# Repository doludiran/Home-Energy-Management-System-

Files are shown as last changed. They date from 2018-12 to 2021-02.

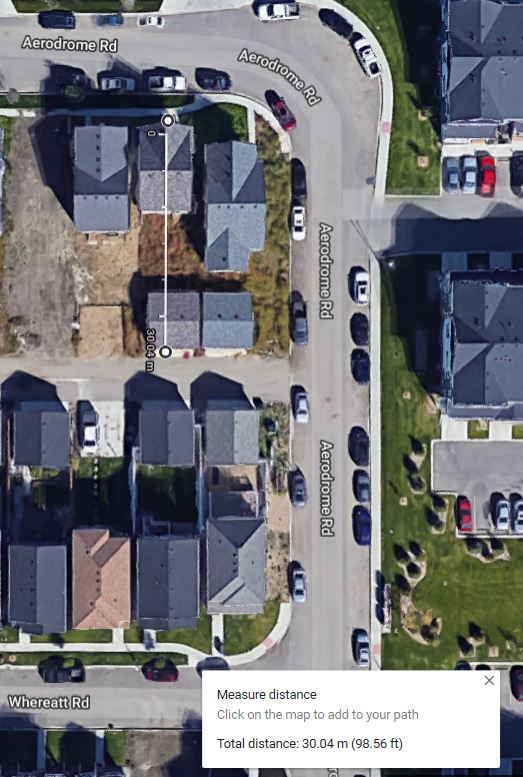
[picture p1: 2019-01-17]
Documentation/HEMS Study/Detached garage.JPG

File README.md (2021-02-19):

# Home-Energy-Management-System-
This system retrieves dynamic electricity pricing information from a utility portal and automatically schedules  large residential loads like EV charging to reduce the overall cost of energy consumed 

The design involves and consists of:
• A Central Control Unit using a Linux based Raspberry Pi programmed in Python. Components of this unit included a touch screen graphic
user interface, secure Internet interface for the automatic retrieval of dynamic pricing information from a utility web portal and xbee wireless
communication interface (zigbee) for remote switching as well as load telemetry data transmission
• A Device Energy Monitoring Unit using an ARM Cortex-M3 based Microcontroller. Components of this unit included a xbee wireless interface
(zigbee) for transmitting monitoring data as well as receiving switching commands from the Central Control Unit, Analog Circuitry for AC load
switching and power consumption measurement (AC Voltage and Current)
• An optimization algorithm to minimize power cost using SciPY
• Multi-threaded programming in c and Python
• Printed Circuit Boards (PCB) design including soldering of Surface-Mount ICs (SMT)
• Hardware and printed circuit board testing and validation
• Component selection and assembly designed to comply with CSA standards

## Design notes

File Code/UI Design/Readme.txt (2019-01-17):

/**
 ******************************************************************************
 * Name:    Readme.txt
 * Capstone Project: HOME ENERGY CONSUMPTION MONITORING AND CONTROL UI DESIGN
 * Version: V1.1
 * Author: Damilola Oludiran 
 * ----------------------------------------------------------------------
 *
 * This is a python touchscreen user interface application built using the Kivy 
 * framework. This module is responsible for the presentation of information the 
 * user as well as retrieval of user preference inputs necessary for the correct  
 * operation of the overall system. 
 * The intended target device is a Raspberry Pi 3 board.
 *          
 * Preconditions:
 * Ensure the following are installed on target:
 *  - Python and Kivy dependencies 
 *  - Kivy
 *  - Kivy garden (matplotlib.backend_kivyagg) 
 *  - sqlite3 database 
 *  - Matplotlib 
 *
 * Note: development is done using Jupiter notebook and has a .ipynb extension. In 
 * in order to run on target, the code should be copied into a .py file 
 *****************************************************************************
 */

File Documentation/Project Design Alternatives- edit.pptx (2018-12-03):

## Revised Client Problem Statement

Design a System that Implements a Demand Response Control/ Management of User Appliances during Peak Energy Consumption Periods by Exploring the Benefits of a Load Scheduling System in Time of Use(ToU) Utility Pricing.

The system will include a Central Control Unit (CCU) that Communicates with a Utility Portal via the Internet to Exchange pricing information with the user

The CCU will Communicate with Various Sensors and Components that will Control Time of Use of Certain Devices and Monitor their Energy Consumption

## Time of Use (ToU) and Real Time Pricing

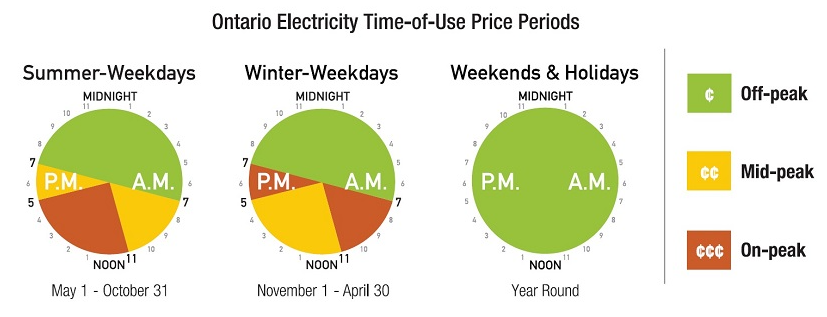
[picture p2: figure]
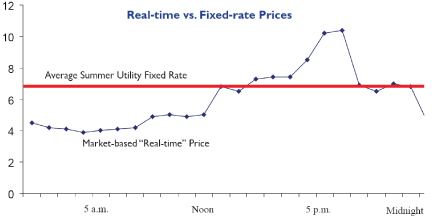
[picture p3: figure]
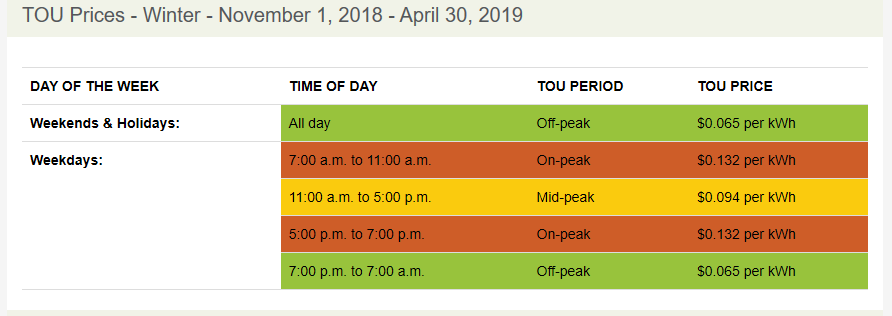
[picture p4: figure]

## System Block Diagram

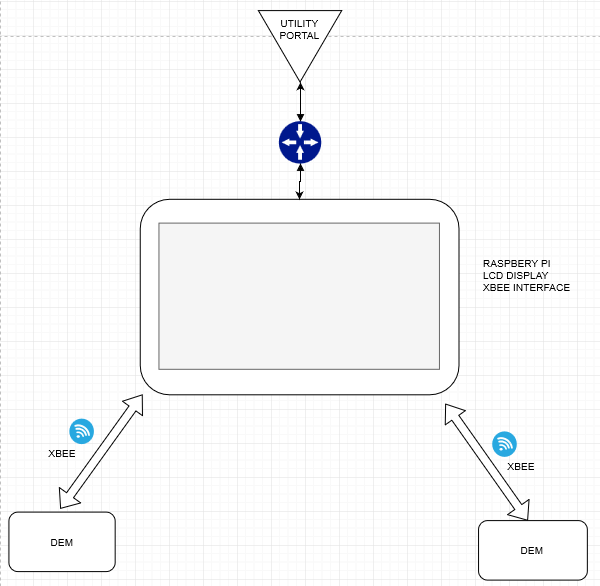
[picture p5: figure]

Central Control Unit (CCU)
Receive Data from Utility Portal
Process the Data/Request
Send Signals to the Device Energy Managers for load Scheduling
Device Energy Manager (DEMs)
Switch the Devices according to the Instructions from the CCU
Monitor Appliance Energy Usage
Send Usage Information to the CCU

CCU

## Sub-System : Device Energy Manager

Manage the Switching of the Desired Appliance

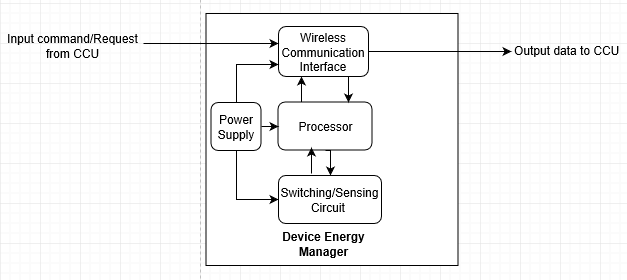
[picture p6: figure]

## Sub-System 1: Device Energy Manager (DEM)

Measure the Energy Usage/Consumption (Optional) of the Desired Appliance

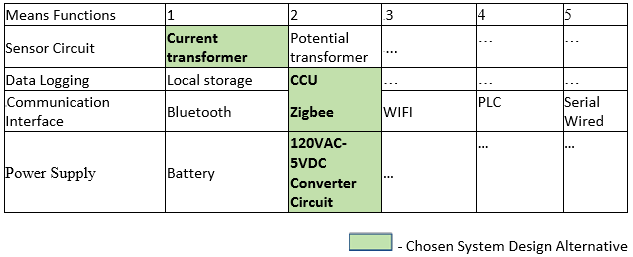
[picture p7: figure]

Switching Circuit | Relay | …… | …… | …… | ……

## Testing Plan

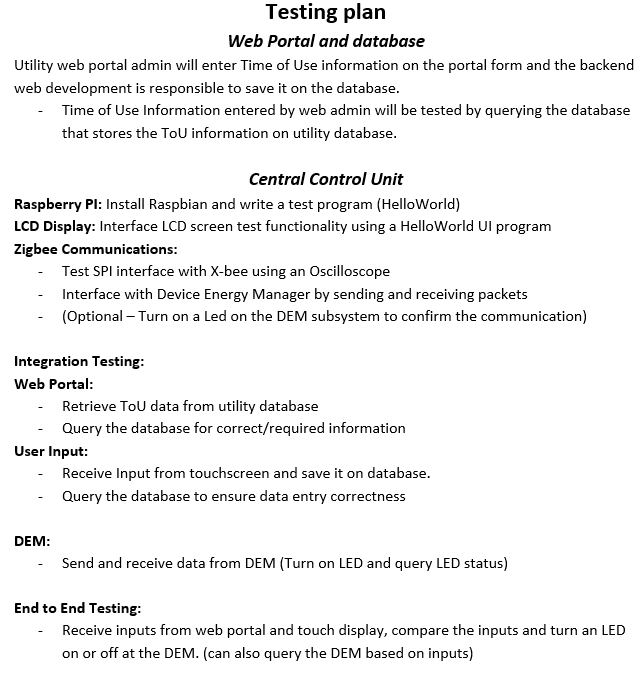
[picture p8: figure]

## Testing Plan

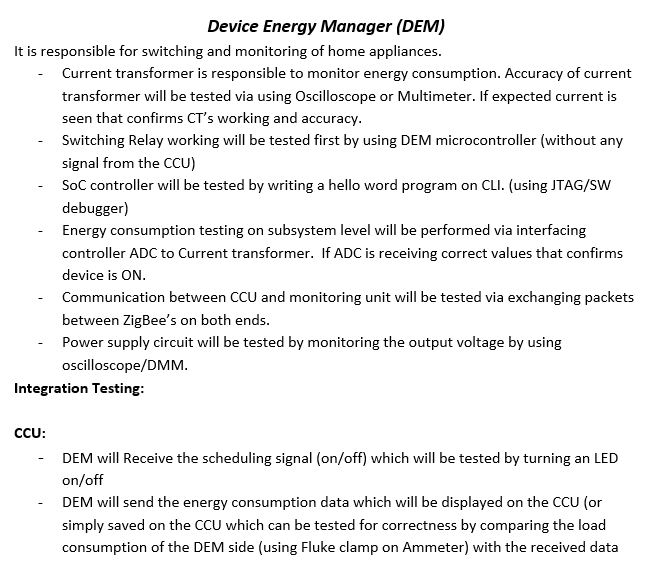
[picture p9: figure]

## Testing Plan – Division of Labour (Overall)

Dami - CCU
- Design and Programming
  - Python based touchscreen User Interface Design
  - Process/display the data from the DEMs
  - Processing User Input for device/appliance scheduling (will be done by using ToU data from utility)
  - Sending scheduling information to the DEMs
- Zigbee Communications
- Enclosure Design and Fabrication (Optional)
Amandeep –
- SoC Testing and Debugging
- RF Antenna Design
- DEM-Side Communication
- Utility Database portal Design
- CCU database design
- Demo Load Electronics
Bikramjit – DEMs
- Programming and Testing
- PCB Schematic Design and Fabrication
- Enclosure Design and Fabrication (Optional)
* This plan might be subject to revision/changes during the progress of the project

## Gantt Chart

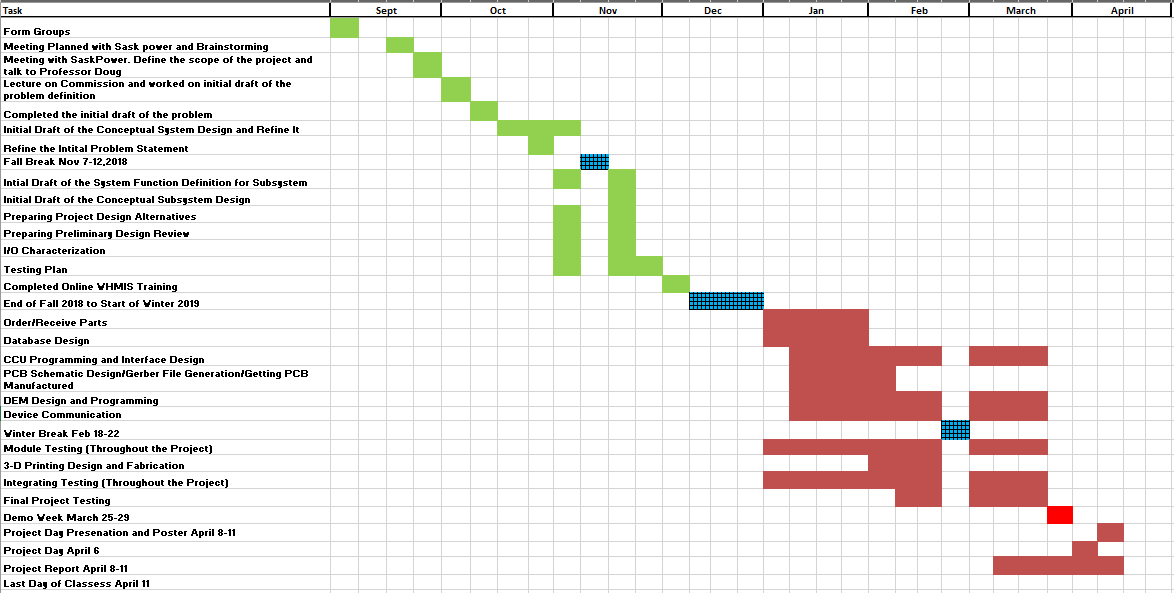
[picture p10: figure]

## Questions

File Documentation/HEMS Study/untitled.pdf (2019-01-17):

Smart home energy management systems: Concept, configurations,

## and scheduling strategies

## Bin Zhou a,n

## , Wentao Li a

## , Ka Wing Chan b

## , Yijia Cao a

## , Yonghong Kuang a

## , Xi Liu a

,

## Xiong Wang a

a College of Electrical and Information Engineering, Hunan University, Changsha 410082, China b Department of Electrical Engineering, The Hong Kong Polytechnic University, Hong Kong

## article info

Article history:
Received 22 April 2015
Received in revised form
22 January 2016
Accepted 13 March 2016
Available online 25 March 2016

Keywords:
Renewable energy
Home energy management system Home energy storage system Home appliance scheduling
Smart house

## abstract

With the arrival of smart grid era and the advent of advanced communication and information infrastructures, bidirectional communication, advanced metering infrastructure, energy storage systems and home area networks would revolutionize the patterns of electricity usage and energy conservation at the consumption premises. Coupled with the emergence of vehicle-to-grid technologies and massive distributed renewable energy, there is a profound transition for the energy management pattern from the conventional centralized infrastructure towards the autonomous responsive demand and cyber-physical energy systems with renewable and stored energy sources. Under the sustainable smart grid paradigm, the smart house with its home energy management system (HEMS) plays an important role to improve the efficiency, economics, reliability, and energy conservation for distribution systems. In this paper, a brief overview on the architecture and functional modules of smart HEMS is presented. Then, the advanced HEMS infrastructures and home appliances in smart houses are thoroughly analyzed and reviewed. Furthermore, the utilization of various building renewable energy resources in HEMS, including solar, wind, biomass and geothermal energies, is surveyed. Lastly, various home appliance scheduling strategies to reduce the residential electricity cost and improve the energy efficiency from power generation utilities are also investigated.
& 2016 Elsevier Ltd. All rights reserved.

Contents

1. Introduction | 31
2. HEMS overview | 31
2.1. Concept of HEMS | 31
2.2. Architecture of HEMS | 31
2.3. Functionalities of HEMS | 32
3. HEMS infrastructures | 33
3.1. Communication and networking system | 33
3.2. Smart meters | 33
3.3. Smart HEMS center | 33
3.4. Home appliances | 34
4. Renewable energy resources in smart houses | 34
4.1. Current status of renewable energy sources in smart houses | 34
4.2. Utilization of renewable energy resources in HEMS | 35
4.3. Techniques to renewable energy in smart HEMS | 36
5. Energy scheduling strategies in smart houses | 36
5.1. Appliance scheduling strategies for HEMSs | 36
5.2. Price-based and incentive-based demand response strategies | 37
5.3. Modelling and control schemes for household appliances | 37

Contents lists available at ScienceDirect

journal homepage: www.elsevier.com/locate/rser

# Renewable and Sustainable Energy Reviews

http://dx.doi.org/10.1016/j.rser.2016.03.047
1364-0321/& 2016 Elsevier Ltd. All rights reserved.

n Corresponding author. Tel.: þ86 731 8388 9677; fax: þ86 731 88664197. E-mail addresses: binzhou@hnu.edu.cn (B. Zhou), yjcao@hnu.edu.cn (Y. Cao).

Renewable and Sustainable Energy Reviews 61 (2016) 30–40 (http://dx.doi.org/10.1016/j.rser.2016.03.047)

5.4. Scenarios analysis for HEMS scheduling strategies | 38
6. Conclusions | 38
Acknowledgements | 39
References | 39
1. Introduction

In 1998, Electrical Power Research Institute (EPRI) carried out a research of “complex interactive network/ system” to develop a highly reliable and fully automated grid in the United States, which is the prototype of the U.S. smart grid [1]. Since the EPRI formally proposed the term “Intelli-Grid” in 2002, the concept of smart grid has been widely accepted to indicate the future development trend of power grids [2,3]. With the use of the term “Smart Grid”, European countries founded the “European Smart-Grids Technology Platform” in 2005, and then launched a research report in 2006 to comprehensively formulate the concepts and framework for the European smart grid [4]. Later, the U.S. Department of Energy released a report “The Smart Grid” in December 2007, and it integrated the European ideas and concepts into the U.S. smart grid to support the trend towards a more reliable and sustainable green energy supply [5,6]. In recent years, developing a modernized smart city infrastructure has become a global common priority in most countries because of the tremendous environmental, economic, and societal benefits that it could offer. In particular, smart electricity usage in demand side plays an important role in improving the sustainability and energy conservation for the home end-users, and will also affect the electricity consumption pattern of human daily behaviors [7,8]. Recent advancements on information and communication technologies, such as advanced metering infrastructure (AMI), smart sensor technologies, bidirectional communication, smart home appliances, home area network (HAN) and home energy storage system (HESS), etc. have been developed. Therefore, this growing trend provides the technical foundation and infrastructures for the smart house with home energy management system (HEMS) [9]. Smart HEMS is an essential home system for the successful demand-side management of smart grids [10]. It monitors and arranges various home appliances in real-time, based on user's preferences via the human–machine interface in smart houses, in order to conserve electricity cost and improve energy utilization efficiency [11–13]. With the growing concerns on global energy security and environmental emissions, more and more distributed renewable generations, such as wind turbines, solar panels, and plug-in electric vehicles (PEVs), etc., would be gird-integrated into the active distribution networks with gradually increasing penetration [14,15]. Coupled with the rapid development in advanced power electronics and alternative energy technologies, building renewable and stored energy sources installed at the residential premises can be incorporated in smart HEMS to improve the in-home efficiency of energy conversion and utilization [16]. Consequently, this leads to a fundamental transition for modern energy management systems from traditional centralized infrastructure towards the cyber-physical HEMSs and autonomous responsive demand with large geographical regions of renewable and stored energy sources throughout smart power systems [17,18].
With the two-way information flow between electricity providers and consumers in smart grid, the massive HEMSs are encouraged to participate in demand response mechanism for energy savings and cooperation. The demand response is defined as the changes in electricity usage by the end-use customers from their normal consumption patterns in response to changes in the time-dependent electricity price [19], and it offers incentives for the demand-side consumers to urge lower electricity usage over periods with higher prices or when power supply reliability is jeopardized [20]. Furthermore, in response to the real-time electricity price from smart meters, the home consumers with HEMS can shift their demand consumptions of appliances automatically or manually into off-peak hours in order to minimize the electricity payment [21]. In a typical smart house, the thermostatically controlled appliances, including heating, ventilation, and air-conditioning system, electric water heater and refrigerator, usually account for most of residential energy consumption [22]. The ever-increasing load demand and energy crisis issue have made the use of smart HEMS more attractive to both the power utilities and customers [23]. Therefore, with the consent of the customers, the HEMS can play an important role for optimal coordination and scheduling of various smart appliances and building renewable facilities.
The objective of this paper is to provide a comprehensive review of the development status and research progress on smart HEMSs with renewable and stored energy sources. First, a brief overview on the architecture and fundamental functions of HEMS is surveyed. Then, the advanced HEMS configurations and home appliances in smart houses are analyzed and presented. Third, the utilization techniques for various building renewable energy resources in smart houses, including solar, wind, biomass and geothermal energy, are reviewed. Moreover, various home scheduling strategies for optimal operations of smart HEMSs are further investigated. Lastly, the concluding remarks are drawn.
2. HEMS overview
2.1. Concept of HEMS

Under the smart grid paradigm, the AMI devices enable a reliable two-way communication between power utilities and home consumers [24]. It provides an opportunity for economic incentives of smart home to manage the demand-side resources by shifting their electricity usage during peak-load periods in response to the changes in electricity prices. The economic incentives include the saving in electricity bill, the improvement in utilization efficiency of household appliances and residential energy conservation [25]. Hence, smart HEMS is defined as the optimal system providing energy management services in order to efficiently monitor and manage electricity generation, storage, and consumption in smart houses [26,27]. With the communication and sensing techniques in HANs, the information collection for energy consumption from all household appliances can be provided, and the remote real-time monitoring and control for different operational modes of smart home devices can even be achieved by a personal computer or smart phone [28]. Besides, HEMS can provide not only the optimum utilization status of home appliances, but also energy storage and management services for distributed energy resources (DERs) and HESS [29].

2.2. Architecture of HEMS

The overall architecture of a representative smart HEMS is shown in Fig. 1. The HEMS center includes a centralized smart

B. Zhou et al. / Renewable and Sustainable Energy Reviews 61 (2016) 30–40 | 31

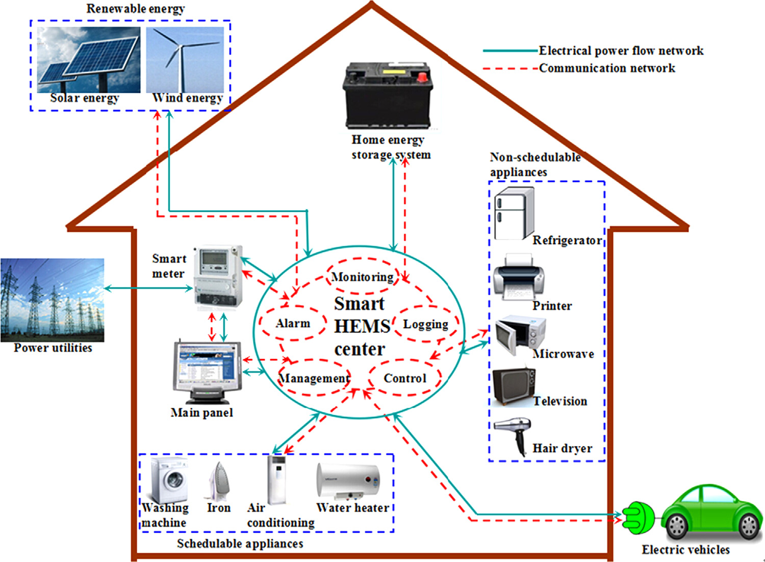
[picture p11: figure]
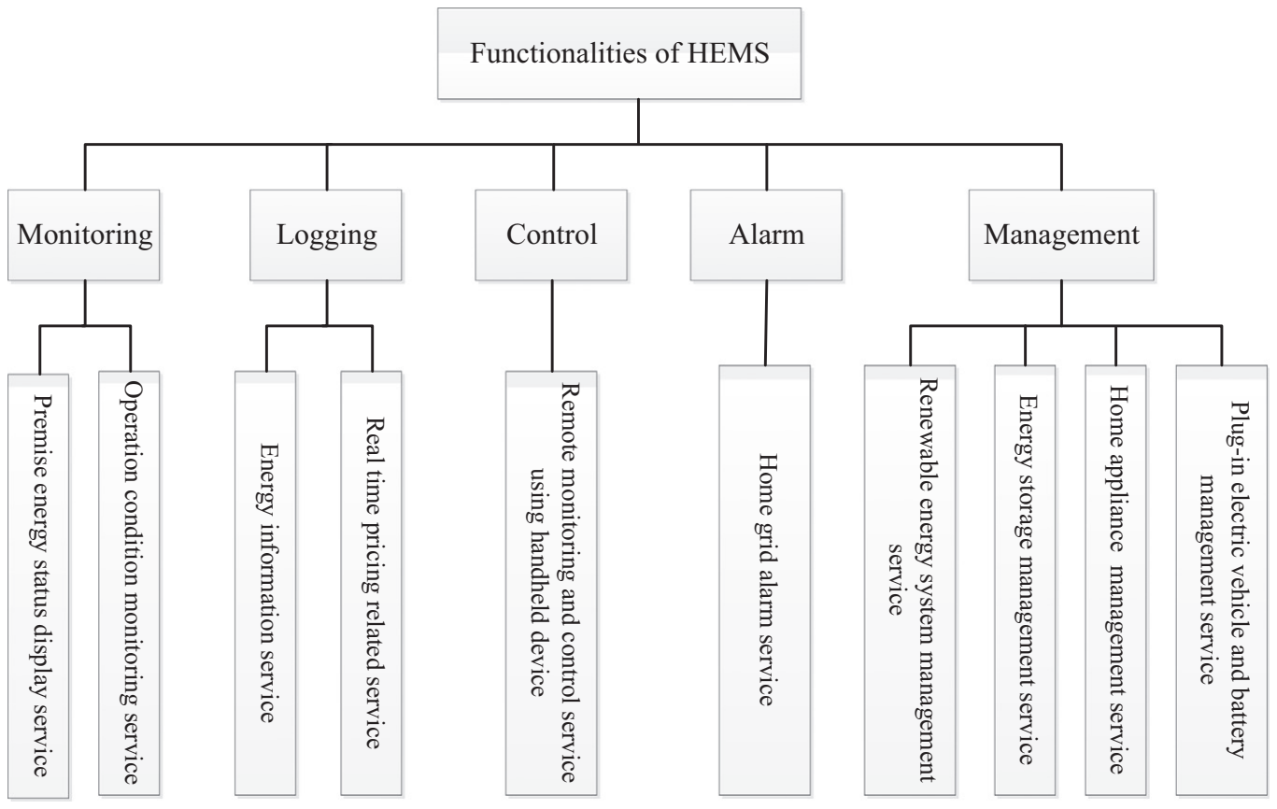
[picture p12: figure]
Functionalities of HEMS; Premise energy status display service; Plug-in electric vehicle and battery; management service

controller to provide the homeowner with monitoring modules and control functionalities based on the home communication network [30]. The real-time electricity consumption data from in-home appliances, including schedulable and non-schedulable appliances, can also be collected by the main panel of smart HEMS to implement optimal demand dispatch. In addition, the house gateway, such as smart meter, can be utilized as an interactive communication interface between power utilities and the smart house in real-life deployment. Typically, the smart meter receives a demand response signal from power utilities as an input to the smart HEMS, and the optimization of home appliance scheduling can be implemented for the residential demand response [31]. Electric vehicle (EV) is a special type of schedulable load. It not only consumes energy from power grids to meet the residents' transportation requirements, but also provides emergency power for other household loads within the smart community environment [32]. Currently, the distributed renewable generations in residential areas most commonly involve solar photovoltaic (PV). The residential on-site energy sources can be fully integrated in the interactive generation management and operations of HEMS, and allow the smart houses not only rely on the bulk power from the transmission systems. Due to the inherent intermittence and randomness of solar energy, the energy storage devices play an important role to improve the power quality and energy efficiency as well as maintain the energy system reliability [33,34].

2.3. Functionalities of HEMS

For the purpose of participating in electricity saving and demand response, HEMS should be more flexible to manage and control smart home appliances, renewable energy resources and

Fig. 1. Overall architecture of a representative HEMS.

Monitoring | Logging | Control | Management Alarm Operation condition monitoring service | Energy information service | Real time pricing related service | Remote monitoring and control service using handheld device | Home grid alarm service | Renewable energy system management service | Energy storage management service | Home appliance management service

Fig. 2. Functionalities of a representative smart HEMS.

32 | B. Zhou et al. / Renewable and Sustainable Energy Reviews 61 (2016) 30–40

HESS [35]. Moreover, the active control services, including real-time information on the amount of energy consumption and the pricing of energy in smart homes, can be provided to the consumers on the basis of HEMS. The household consumers can choose their preferences via the human-machine interface to schedule the service time of various appliances to enhance their energy utilization efficiency [36]. Fig. 2 shows the typical functionalities of a smart HEMS center with five main functional modules, including monitoring, logging, control, management and alarm. Further detailed description on the five HEMS modules are illustrated in Table 1 [36,37].

3. HEMS infrastructures

The in-home infrastructure of HEMS is composed of smart HEMS center, smart meters, communication and networking system, HESSs and other smart devices [34]. With these smart infrastructures, HEMS can access, monitor, control and optimize the performance of various DERs, EVs, household appliances and equipment. Furthermore, HEMS is capable of supporting full integration of smart appliances and smart home as well as two-way interaction with users and electric power utilities. Many attractive features of smart grid such as cost- effectiveness, flexibility, provision of differentiated services and user friendly advanced smart power technology with open standard assessment can also be implemented via the HEMS [38].

3.1. Communication and networking system

So far, various HEMSs have been designed based on different communication schemes with hardware implementation [39–46], such as power line communication [36], ZigBee [39], BACnet [40], Bluetooth [45] and human–machine interface systems [42,43]. Extensive investigations have been done on communication and networking technologies for HANs. Young-Sung Son believed that the combination of a smart meter and power line communication could provide remote access, facilitate planning, and save the energy consumption of home appliances [36]. Dae-Man Han suggested a new Smart HEMS based on an IEEE802.15.4 and ZigBee which divides and assigns various home network tasks to appropriate components [39]. With the support of active sensor networks which compose of sensor and actuator components, HEMS can integrate diversified physical sensing information and control various household devices [39]. Also, Kastner Wolfgang introduced the necessity of the building automation, systems and communication infrastructures based on BACnet [46]. Considering the potential of the easily embedding Bluetooth technique in communication devices and household appliances, Lilakiatsakun proposed a method to establish a complete home network using Bluetooth technique [45]. In addition, Fangxing Li designed a human–machine interface system which can be used in HEMS. It is supposed that HEMS shall have five main components referred as application processor, communication interface, user interface, sensor interface and load interface to facilitate user's operations on this system [42,43].
Based on the evaluation analysis of various communication technologies, ZigBee is chosen to demonstrate the proposed HEMS [42]. ZigBee, a wireless communication technology that is developing rapidly in recent years, has laid solid foundation on networking, security and software-related technical standards. ZigBee makes use of the world's most common 2.4G–2.4835 GHz frequency band. In terms of the low energy consumption and durability, ZigBee is with the low power consumption, low cost technology and can support a large number of characteristics of the network nodes, and thus can be used in a wide range of industrial applications [30].
3.2. Smart meters

Smart meters are the advanced energy meters that measure the energy consumption of a consumer and provide additional information to power utilities using a two-way communication scheme [47,48]. As a result, customers are able to make optimal decisions to schedule the electricity usage of in-home appliances as well as actions of DERs and HESS [49]. As the foundation of data acquisition, data processing and advanced metering equipment management, smart meters are the latest techniques blended with computer science, modern communications and measurement techniques. Considering that smart meters are the basis of smart electricity, the functional design of smart meters should take into account the current facts and future development, such as the access of DER and the actual capacity of communication channel [47].
Main functions of smart meters include the following [50]: 1) Measuring the multi-period and multi-mode power rates of active and reactive energy metering usage; 2) Supporting two-way communication, sending data information and accepting instruction information, such as real-time information query, real-time electricity standard rates, meter upgrade program settings, etc.; 3) Enabling the response in terms of the requirements to achieve smart load shedding and cooperating with smart meter and smart interactive terminals during the islanding transition when a failure happens on the main power grid; 4) Collecting data with smart gas meters, water meters and other versatile value-added services.
3.3. Smart HEMS center

Smart HEMS center, analogue to the brain of entire smart electricity home, is the core of HEMS and implements the smart energy management. Smart HEMS center is located in user's houses as a home appliance. Main functions of smart HEMS center

Table 1
Functional modules of HEMS.

HEMS modules Service description

Monitoring | Monitoring offers easy access to real-time information on energy consumption and allows users to focus on the electricity saving. It can also provide
| display services for the operational modes and energy status of each home appliance.
Logging | Logging is to collate and save the data information on the amount of electricity usage from appliances, generations from DERs and energy storage state.
| This service also contains demand response analysis for real-time prices from grid utility.
Control | There are two types of control, namely, direct control and remote control. Direct control is implemented on both the equipment and control system;
| whereas, remote control means customers can online access to monitor and control the usage patterns of in-home devices via handheld personal
| computer or smart phone from outside.
Management | Management is the most important function of HEMS to enhance the optimization and efficiency of electrical power usage in smart house. It covers a
| range of services including renewable energy system management service, energy storage management service, home appliance management service,
| and Plug-in EV and battery management service.
Alarm | Alarm will be generated and sent to the smart HEMS center with information on the fault locations, for example, if there is any abnormality detected.
B. Zhou et al. / Renewable and Sustainable Energy Reviews 61 (2016) 30–40 | 33

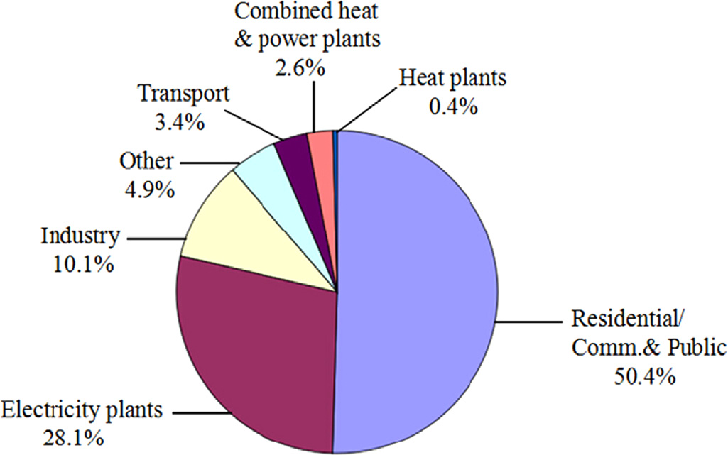
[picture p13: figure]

are as follows [51]: 1) Receiving a large amount of data sent by smart meters, main control panel, and real-time display. The control commands issued by the consumer are sent to all household equipment. Consequently, the automated demand response can be achieved; 2) Providing a friendly human-machine interface and supporting user's real-time browsing, online monitoring, task setting and other functions to arrange the usage of electricity; 3) With high scalability, the smart HEMS center can set water, electricity, gas, and other indoor controls; 4) Integrating DERs, energy storage devices and electricity regulator of EVs as well as analyzing and forecasting distributed generations to achieve the optimal control of DERs.

3.4. Home appliances

Various household appliances and energy storage devices can be thoroughly analyzed and modelled based on the device characteristics and preference usages. In order to implement the optimal coordinated appliance scheduling strategies, the smart home appliances can be divided into two categories: 1) Non-schedulable home appliances, e.g. refrigerator, printer, microwave, television, hair dryer; 2) Schedulable home appliances, which can be scheduled for optimal operation or switched on/off at any time, e.g. washing machine, air conditioner, iron, water heater, EVs. The appliances which can complete a task without any manual control, such as air conditioner and water heater, are schedulable [51]. While non-schedulable appliances, such as lights, computers and televisions, rely on manual control to complete a task and are needed only when the users are home. Since the comfort level of users is quite sensitive to the timely services of non-schedulable appliances, their usage would usually not be delayed. Schedulable appliances can be further classified into ‘interruptible’ and ‘non-interruptible’ in terms of the continuity of operation time [52]. Generally, the interruptible appliances are usually more schedulable than non- interruptible ones. The non-interruptible appliances are constrained by fixed operation period called ‘hold-time’ [52]. As a unique load, the EV becomes more important and extensive as the part of HEMS. Experts expect that the amount of EVs will be increased in the following years, which helps to reduce air pollutants and greenhouse gas emissions [53]. Since EVs can be charged or discharged when connected to the grid, a growing number of practical services can now be realized in power grid [54]. Vehicle-to-grid, as a new concept, indicates that the electric energy stored in the EV battery can also be transmitted to the power grid [55–57]. In the smart HEMS, EVs are capable of balancing the peak power, which means that EVs can supply power during peak periods while users consume power during off-peak periods.

4. Renewable energy resources in smart houses
4.1. Current status of renewable energy sources in smart houses

Since 1990s, the utilization of renewable energy sources has increased with an average annual rate of 2.0% [58]. Additionally, renewable energy has been consumed in various fields, including the industrial, residential, commercial, and public sectors. As shown in Fig. 3, only 31.1% of renewable energy is used for electricity and heat production worldwide, while 50.4% is used for residential, commercial and public purposes in 2012 [58]. It also indicates that the research on the use of renewable energy in HEMS is of great significance and developing prospects. With the rapid development of sustainable energy technologies and increasing demand for low-emission generations, the utilization of renewable energy shows promising prospects for smart houses.

From the technical and economic aspects, it is quite feasible to substitute fossil fuels with renewable energy for home electricity supply [59]. Meanwhile, with further development of smart grid technologies including communication and monitoring, control, and self-healing, the smart home energy utilization has been improved to accommodate multiplying renewable resources [60]. Due to its rapid development of renewable energy resources in the past 15 years, Germany is a forerunner in renewable electricity [61]. In 1998, Germany began to implement “100,000 Roofs Plan”, aiming at obtaining 300 MW solar power from the roofs of citizens. Presently, there are about 0.9% of German families using solar power system. Residents sell rooftop solar electricity at a high price to power grid during the day, however, at night, they buy electricity for use at a fair price. Therefore, residents become energy producers and consumers [62]. Thanks to its easy installation and low cost, the solar PV is widely used in smart houses. Cyprus, known as a leader in solar water heater in the world, is a country where 92% families and 53% hotels are using solar water heater systems, equipping with about 937,363 m² of solar collectors, nearly 1 m² per person [63]. Moreover, the solar PV cell productivity in China in 2008 was about 4 GW, 3 GW PV of which was module capacities. The cumulative capacity of installed PV power was 150 MW. At the same time, the solar water heaters have covered over 125 million m² in buildings, reaching about 60% of the worldwide total [64].
Wind power is characterized by many merits such as clean, renewable, widely distributed and land-saving [65]. Therefore, wind power is more widely used than other resources to solve severe environmental problems. For example, in 2013, one third of Denmark's electricity is produced by wind and over 83 countries in the world are using wind power to produce electricity [66–68]. Estimates show that the annual electricity generated by wind power system will amount to 1.7–5.0 TW h by 2020 if new buildings and existing buildings are all equipped with wind power systems [69–71]. Obviously, the utilization of wind power in smart houses is of great potential.
As an important means of access to energy, the application of biomass combustion power generation technology in smart houses is foreseeable. Since the 1990s, Denmark, Austria and other European countries have started the development and research of biomass power generation technologies. After years of efforts, boilers have been developed for power generation with wood chips, straw, chaff, etc. At present, biomass power generation has been used in households throughout Denmark [64]. Straw power generation and other renewable energy sources have accounted for more than 24% of the national energy consumption. The installed biomass power generation capacity in HEMS of United States has reached 10.5 million kW, while the biomass power

Fig. 3. World sectoral consumption of renewables in 2012.

34 | B. Zhou et al. / Renewable and Sustainable Energy Reviews 61 (2016) 30–40

generation techniques get faster development and higher utilization rate in Japanese cities. Likewise, China's utilization of biomass has been developed substantially. Achievements have been made in biogas, biomass power generation and liquid bio-fuel, while the majority usage belongs to electricity and heat generation. The installed capacity of biomass power generation increased to 4 GW in 2010, which was about 25% of the total. 1600 large-scale digesters and over 30 million home biogas digesters were built for smart home, and the annual biogas output was about 14 bcm and 1.65 Mt for bio-fuel [64]. Furthermore, great importance has been attached to the combination of biomass power and smart home energy dispatch. The immature technologies, the absence of comprehensive product standards, and inadequate supply chain are major barriers to the further development of biomass energy in smart houses.
Geothermal energy, defined as the heat from the underground, is an ideal renewable energy resource that is not intermitted and distributed usually around volcanic areas. There are two forms of geothermal energy utilization: geothermal heating and geothermal generations, and the latter has experienced a rapid development over recent years in the world [72]. So far, the chief geothermal energy suppliers for households are the United States, Iceland and Philippines. All around the world, Icelandic geothermal power is widely used to generate electricity due to its reliable base load and low cost. Thus, 87% of the smart houses in Iceland are heated by geothermal energy [73].
4.2. Utilization of renewable energy resources in HEMS

The world environmental condition, increasing need for energy demand nowadays, and the development of alternative energy technologies have brought forth a large amount of opportunities to develop various sustainable resources. Various building renewable energy resources, including solar, wind, biomass, geothermal energy and HESSs, have been utilized in smart houses.
As of today, solar energy is the richest inexhaustible and clean energy among all kinds of renewable energy resources [74]. Solar energy can be utilized in various aspects including solar water heater (SWH), solar PV, solar drying and solar cooling, etc. Due to easy installation and low cost, the SWH is widely used in households. Hot water heated by the solar energy can be used for showering, cooking and washing. In order to improve the conversion efficiency of SWH and reduce electricity consumption, legislations have been enacted to install SWH on each new building. Besides, more electricity bills are charged for the household who uses electricity to heat water [75]. Solar energy utilization can be classified into two types: solar thermal and solar PV. PV technique, known as the best means to convert solar energy, can directly convert the sunlight into electricity without any help from heat engines [76]. The solar PV is prevailing among residences where the annual sunshine is abundant [77]. Owing to its easy installation and maintenance, solar PV is quite suitable to incorporate into smart home to provide locals with energy and be utilized in various ways with less conversion failures. In addition, HEMS is usually equipped with an HESS which could store the energy for future or emergency use. The HESS also works as a buffer to make the HEMS reliable and improve network control [78,79]. The solar PV module is the most important part of a solar home system (SHS) and its supporting components should be properly adjusted according to direction and tilt of the module. Apart from the low price, the roof mounting for solar PV module is more suitable than ground or pole mounting and requires less wiring. The supporting components should be firmly attached to the roof beams instead of roof tiles [80]. In a stand-alone PV system, it is the irreplaceable charge controller to protect the battery from overcharge and over discharge. The charge controller is necessary for systems with unpredictable loads, user intervention, optimized or undersized battery storage and other characteristics that would allow excessive battery overcharging or over discharging, as the low voltage load will shorten the battery lifetime and diminish the load availability [81]. DC/AC inverters are used in SHS with a power larger than 100 Wp to provide customers with AC electricity. Only a few types of inverters are suitable for SHS, which are of square wave, modified square wave, and pure sine wave [82].
Wind energy is an important alternative energy, and its utilization in smart houses is always a hot topic over the years. Typically, the fan can generate electricity at the wind speed of 2.7 m/s, achieve rated power at 25 m/s, and ensure continuous electricity generation at 40 m/s. The device required by wind power generation is called wind turbine generator, which generally includes fan, generator, steering gear, tower, restricting and safety mechanism, and energy storage device [65]. In smart houses, the building hinders the linear motion of the air so that the air deflects to the top and sides of the building and produces pressure difference around the fan, which makes the generator rotate and generate electricity. Usually, the electrical energy generated is generally used for home lighting equipment, communication equipment and electrical tools [83]. Due to the volatility and intermittency of wind generations, the specific plans on the adjustable reserve capacity are of intense importance. Also, an accurate forecast on wind speed is indispensable to reduce the reserve capacity with the improved reliability [84]. HEMS can provide a well-designed storage platform to schedule the electricity generated by wind turbines through the charging/discharging strategies of HESS.
Primarily used for home cooking, heating and lighting, the biomass energy is widely used in smart houses. Numerous investigations have been studied on the biomass energy utilization, including the biomass energy in high-rise buildings [85], the biomass exploited for building heating [86], the influence of biomass boilers on energy rating [87,88], and the biomass fueled tri-generation system for selected buildings [89]. At present, the biomass power generation used in smart houses includes biomass combustion generation, biomass gasification generation, and biogas power generation. Biomass combustion generation is to combust biomass with excess air in the boiler, then the hot smoke generated exchanges heat with the heat exchanger of the boiler, and the high temperature and high pressure steam generated expands in gas turbine and hence generates electric power [86]. Biomass gasification generation technique means the thermochemical conversion of biomass into gas fuel, which is put into the combustion chamber of boiler, diesel generator, internal combustion engine generator and gas engine after purification to generate electricity. Lastly, biogas combustion generation is a biogas utilization technique that appears with the development of biogas technique. Biogas is utilized in the engine and equipped with integrated power generating units to product electricity and heat, constituting an important way for efficient utilization of biogas [89]. Geothermal energy is characterized by low cost and cleanness, and the most traditional and popular usage of the energy is to generate heat directly [90]. Over the last decades, plenty of geothermal devices have been installed in smart houses. Compared to the deep geothermal energy utilization, the shallow systems do not need the extraordinary geological settings and high geothermal gradients with clean and eco-friendly traits [91–93]. So far, the main utilization of shallow geothermal energy is air conditioning used in residential households, and the heat pump techniques are applied to pump up and utilize the shallow underground lowtemperature heat sources. Ground source heat pump is an efficient energy-saving air conditioning technology to utilize shallow geothermal resources for heat supply and cooling [72]. The exploration and development for geothermal resources is an emerging industry with high investment and high risk due to the geographical distribution limitations of geothermal energy [92].
B. Zhou et al. / Renewable and Sustainable Energy Reviews 61 (2016) 30–40 | 35

4.3. Techniques to renewable energy in smart HEMS

The alternative energy techniques in smart houses generally refer to the renewable resources developed and utilized using smart grid technologies. In this section, home energy storage system, hybrid renewable energy systems, power electronics as well as control and communication technologies are surveyed. HESS techniques have an important impact on the utilization of renewable energy in smart houses. Recent commercial advancements in large energy storage and power electronic technologies offer new opportunities in intermittent generation stabilization, optimum management, power quality improvement, and peak load shaving. Currently, lead acid batteries, flow batteries, ultracapacitors and chemical energy storages have been widely used in HESSs [94,95]. The electricity generated by solar and wind energy is always fluctuant and volatile, and the balance between energy supply and demand at any time is required in household energy systems. Consequently, the coordinated charging/discharging schemes of HESS can effectively balance the variability and volatility of renewable energy generations and maintain a stable and reliable power supply. Moreover, in smart houses, the roof mounting solar PV, wind energy and other DERs are main power sources during the peak-load periods, and the energy storage devices and EVs in HESS are of the essence for interactions between households and power utilities [59]. On the other hand, during the electricity outage periods, the HESS can be employed with various renewable generations to form an independent generating installation to provide electricity supply for the critical load consumers so as to enhance power grid resilience [29].
Due to its inherent seasonality, variability and periodicity, a single renewable energy source, such as solar, wind, and geothermal, is inadequate to provide a continuous and economic power supply for HEMS [96]. Thus, the hybrid energy system with multiplying renewable generations can be formed and utilized to alleviate the intermittent and unstable effects of electricity supply [59]. For most of HEMSs, the sunlight is sufficient with abundant power generations of PV panels in summer, and thus more energy from PV can be used and stored for electricity supply. On the other hand, sunlight will be weakened in winter and wind power is the main contributor to support more electricity supply. In addition, there are various configurations for different hybrid renewable energy systems in smart houses, such as wind/PV, PV/biomass, wind/hydropower, wind/PV/biomass, and so on [97].
Since most of renewable and stored energy resources are transformed into electrical energy in smart houses, the energy conversion technologies are critical for the utilization efficiency of various renewable energies. The major impact of power electronic conversion technologies on renewable energy development and utilization is to improve power quality, energy efficiency-peak shaving, and control strategies [19]. Power electronic techniques have been increasingly adopted in household energy generation system for grid-integrated solar and wind energy sources [82]. With the extensive utilization of renewable generations and energy storage devices in residential buildings, it is necessary to design the optimal sizing and configurations for power electronic converters [11]. Also, with the highly efficient power electronics in alterative generations, energy management and conversions, userend interfaces, together with the advanced control solutions, can pave the way for large-scale applications of renewable energies in smart houses [17]. In smart houses, PV systems generate DC power which needs to be converted to single- or three-phase AC, while the wind and microturbine systems generate variable frequency AC output which needs to be converted into the rated frequency AC for appliance utilization. For battery energy storage systems, a bidirectional DC–DC converter followed by a DC–AC inverter is the most general choice [43]. An increasing penetration level of renewable energy systems results in more stringent household demands, and the tasks of power electronics based HEMS are as varied as they are demanding by local end-customers [42]. The specific demands can be summarized as: 1) reliable/secure power supply, 2) high efficiency, low cost, small volume, and effective protection, 3) control of active and reactive power generations, 4) dynamic ride-through operation, and 5) system monitoring and communication in HEMS [11].
Communication and information technologies are required in smart HEMS to implement optimal appliance scheduling and energy management strategies. Within a smart home, the HEMS center with metering devices can collect and deliver information and control signals to optimize the electricity consumption and production schedule [30]. So far, different communication standards have been envisioned within HAN, such as HomePlug (IEEE P1901), Ethernet (IEEE 802.3), X10 (X10 standard), Insteon (X10 standard), ITU G.hn (G.hn), Z-Wave (Zensys, IEEE 802.15.4) WiFi (IEEE 802.11, IEEE 802.15.4), ONE-NET (Open-source) 6LowPAN (IEEE 802.15.4), ZigBee (IEEE 802.15.4), and EnOcean (EnOcean standard) [98]. Therefore, for effective utilization of renewable energies in HEMS, the devices require the ability to broadcast vital information about their state and energy requirements, as well as act based on signals received from the HEMS [39].
5. Energy scheduling strategies in smart houses
5.1. Appliance scheduling strategies for HEMSs

In the deregulated power markets, the implementation of demand response can loosen the control of retail electricity prices and improves the elasticity of demand [99,100]. In recent years, various decision-support tools have been reported to optimize and implement the home appliance scheduling with electrical energy services for residential consumers in smart houses [101–109]. The application of PEVs as dynamic energy storages with their travel patterns to coordinate the optimal home energy scheduling in a residential community has been presented in [102–104]. Automatic energy consumption scheduling strategies with price predictors was proposed in [105,106] to minimize electricity payment in a real-time pricing tariff environment. In [51], an energy management controller was developed on the basis of demand response information from the home gateway, and all appliances in smart houses will operate automatically in the most costeffective way. Considering various uncertainties on appliance operational time, intermittent renewable generations and variations of electricity prices, the stochastic efficient scheduling schemes for optimized HEMSs have been addressed in [107,108]. Moreover, the distributed control algorithms for household demand response have been presented in [52,109] based on the bidirectional communication network architecture to schedule the in-building appliances and renewable energy sources.
In this context, many countries and regions conducted extensive investigations and practices for the demand response, especially the United States who helped organizations carry out the demand response and achieved satisfactory results. In August 2005, US President George W. Bush signed the Energy Policy Act. The bill clearly defines that the implementation of demand response and enforces it with great support. In addition, a study of demand response was submitted by the US Department of Energy to the Congress in February 2006, elaborating on the benefits of the implementation of demand response and recommendations [110]. Subsequently, the US Federal Energy Regulatory Commission also submitted the annual report of demand response to the Congress in August 2006 and September 2007 which analyzed the background and status of implementation of demand response in
36 | B. Zhou et al. / Renewable and Sustainable Energy Reviews 61 (2016) 30–40

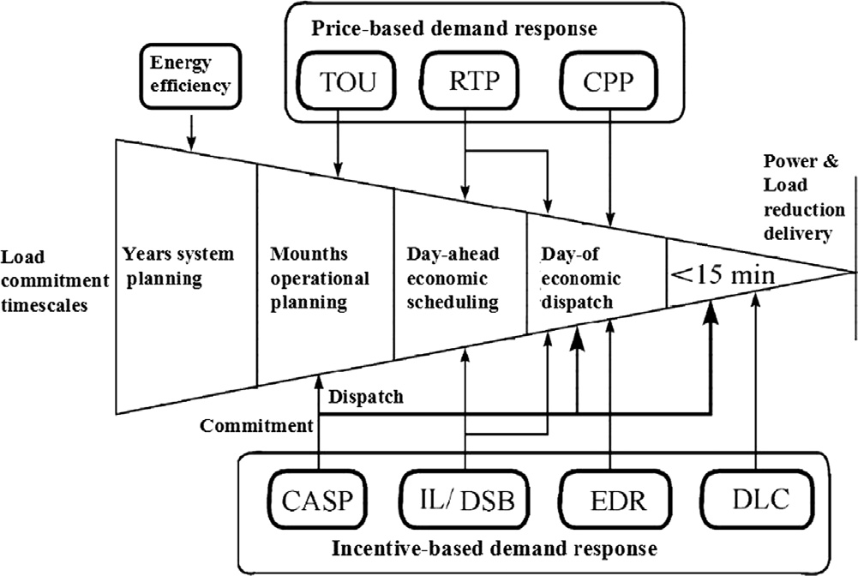
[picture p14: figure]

residential households, the influence of demand response on power grids as well as the applications of AMI in the demand response and smart houses [111,112].

5.2. Price-based and incentive-based demand response strategies

According to the research reports from US Department of Energy, in accordance with the user in different ways to respond, the demand response schemes of power market includes the following two types: price-based demand response and incentive-based demand response [109]. Table 2 shows a comparison of the two demand response schemes [110]. The price-based demand response refers to the retail prices when users are in face of changeable electricity demand, including time-of-use pricing (TOU), real-time pricing (RTP) and critical peak pricing (CPP) and so on. User decision-making process through the internal economy would change the periods of low electricity price and reduce the electricity consumption in high-price periods to conserve electricity costs. On the other hand, the incentive-based demand response stands for the demand response implementation mechanism through the formulation of a deterministic or timevarying policy, including direct load control (DLC), interruptible load (IL), emergency demand response (EDR), demand side bidding (DSB), and capacity/ ancillary service program (CASP) and so on [110]. The function of incentive-based demand response presents its capability in motivating users in the impact of system reliability or timely response by higher electricity prices and demand reduction [99]. These two types of demand response mechanisms are inherently relevant and complementary to each other, and Fig. 4 illustrates their appliances scheduling and commitment strategies with different energy utilization efficiency and time scales in smart HEMS [110]. As can be seen in Fig. 4, with the real-time appliance scheduling strategies, the demand response in smart houses not only can be implemented flexibly on different time scales, but also can participate in the coordination of various appliance management and renewable generation scheduling [113,114].
Modern smart grid infrastructures with two-way communication enable power utilities to provide end-users with a time-dependent electricity price for interactive demand response. Based on communication and sensing techniques in HANs, a smart HEMS center can therefore schedule an optimal real-time and priceresponsive electricity usage scheme for home energy storages and residential appliance loads, including schedulable and non-schedulable appliances [100]. The principal objective of optimal demand response scheme of HEMS is to manage the power consumption of home appliances during peak and off-peak periods in order to reduce the electricity cost of consumers and improve the utilization of energy from power generation utilities. Furthermore,

HEMS should also schedule and coordinate the power generated from weather-dependent renewable energies, energy storage devices and user comfort levels to make more reliable and efficient use of electricity in an optimum way. Thus, there arises an urgent requirement for an optimal appliance scheduling scheme of HEMS with renewable and storage energy sources in smart grid environment [101,102]. The progressive development of smart grid infrastructures and advanced energy storage devices has brought new opportunities and challenges in demand response. The smart HEMS should cope with increased uncertainties of renewable energy sources in a large scale, HESS, and consumer comfort preference on home appliances [113]. Besides, a smart HEMS shall be able to respond to renewable generation fluctuations, electricity price, and other human behavior influences in real-time or near real-time to achieve a comfortable lifestyle with financial incentives [114]. The system shall also be flexible enough to accommodate and manage various home appliances, renewable energy resources and HESSs for energy saving and demand response.

5.3. Modelling and control schemes for household appliances

The emergence of smart grids and the increasing concern for electricity saving have presented opportunities for smart HEMS in demand response markets. As an important demand response tool, HEMS shift and curtail household appliance usages to improve the energy efficiency and production profile of a household on behalf of a consumer. HEMS usually formulate optimal consumption and production schedules with the consideration of multiple objectives such as energy costs, environmental concerns, load profiles, and consumer comfort [115]. In general, the main objective of control schemes for household appliances in HEMS is

Table 2
A comparison of two demand response schemes.
Schemes | Options | Functional descriptions
Price-based demand response Time-of-use pricing | A tariff-making model in which the electricity prices vary with time, usually designed over a 24 h day.
| Real-time pricing | A pricing scheme in which the price for electricity typically fluctuates hourly, reflecting changes of
| | wholesale price of electricity.
| Critical peak pricing | A pricing strategy where electricity prices are determined beforehand at peak hours of critical day.
Incentive-based demand response | Direct load control | In order to solve the reliability problem or regional emergency in power systems, the program operator
| | remotely shuts down or cycles a customer's electrical equipment on short notice.
| Interruptible load | Reducing or interrupting the participation of load in emergency situations of the system.
| Demand side bidding | Customers offer bids for curtailment based on wholesale electricity market prices or an equivalent.
| Emergency demand response | Processing the system reliability accident caused by network operating risk, power shortages, black-
| | outs, and so on.
| Capacity/ancillary service
| program | Dealing with the generator failure, transmission line fault and other system accidents caused by the
| | tight capacity. It can also participate in voltage control, frequency regulation and demand side
| | resources reserve.

Fig. 4. Demand response scheduling strategies in smart HEMS.

B. Zhou et al. / Renewable and Sustainable Energy Reviews 61 (2016) 30–40 | 37

the minimization of energy consumption [115]. Besides, various artificial intelligence techniques have been applied to the control of both conventional and bioclimatic buildings. Intelligent controllers, optimized by the use of evolutionary algorithms were developed for the control of the subsystems of an intelligent building and in-home appliances [116]. The synergy of the neural networks, with fuzzy logic, and different evolutionary algorithms resulted in the so-called computational intelligence, which now has started to be applied in smart houses [117]. Moreover, the detailed modelling considerations for HEMS, including modelling demand response of devices, modelling of well-being, modelling multi-objectivity, modelling for uncertainty and communications infrastructure requirements inferred based on modelling, are surveyed in [118].
Since each appliance has unique characteristics, difficulties may arise for the HEMS to intuitively develop a model that represents each device. Beyond the infrastructure and communication challenges associated with the dynamic inclusion of new devices, such as recognizing one's plug-in hybrid. EVs returning home, the modelling and control of a multitude of appliances can be an evident barrier to the deployment of HEMS optimization [39]. Well-being analysis, relating to the lifestyle of residential consumers, is considered as an important objective to maintain in managing energy consumption [97]. The loss in the quality of service caused by energy delivery can bring inconvenience to the consumer. It is unsuitable to simply infer the inconvenience incurred to the consumer as a result of a shifted load because inconvenience is not time-invariant while consumers are heterogeneous. The work in [69] elaborates the multiobjective optimal models for smart appliance scheduling, and incorporating uncertainty into the scheduling process has the potential to improve the scheduling efficiency. Model predictive control is the most common method for addressing forecast errors, and is an open-loop online control system that approximates the desired solution by reducing the impact of the undesired dynamic properties of the system [101]. The HEMS modelling requirements are dependent on the market and communication infrastructure. In case where information from the grid is minimal or unnecessary, the HEMS only needs to communicate with the devices in the house [112], and the HEMS passively receive the information from the grid, either through the internet or through broad wireless signals [118]. Finally, when active bi-directional communication is required between the HEMS and the utilities, the HEMS should send the information frequently, securely, and with an effective communication protocol.
5.4. Scenarios analysis for HEMS scheduling strategies

A smart HEMS is a residential demand response tool that shifts and curtails demand to improve the energy efficiency and reduce electricity cost based on the real-time electricity price and consumer comfort [117]. In this section, the HEMS scheduling strategies have been analyzed under different operational scenarios. Study on the efficiency of HEMS based on Marc Beaudin and Hamidreza Zareipour indicates that a HEMS could reduce the operational cost of electricity by 23.1%, and decrease the residential peak-load demand by 29.6% [118]. In addition, it can be found from [98] that other advantages with HEMS include the minimization of energy wastage, reduction of household occupant intervention, eco-friendliness, and improvement of resident well-being. In the practical applications, not all users can simultaneously obtain the utilization of power load control, HESS, DER and the opportunity of selling electricity to the power grid. However, the extensive investigations indicate that energy consumption bill can be decreased if users possess HESS, DER, and the chance of selling electricity to the grid. In [119], three appliance scheduling schemes under different HEMS operational scenarios have been implemented and analyzed, and the corresponding electricity usage costs are shown in Table 3. The technical capabilities in the smart house are incrementally increased, including the load scheduling only, and then adding successively the HESS, the capability to sell electricity, and the capability to generate electricity (solar panels, and DER genset). In the basic scenario with the user limited to scheduling controllable loads, the economic gain varies from 9.8% (against B-DA case) to 28.3% (against B-RT case). In presence of the HESS, the proposed algorithm in
[119] improves the objective function by 21.2% to 37.7%. If the consumer also has the ability to sell electricity, the robust appliance scheduling method outperforms the base case by 23.3–53.8%. Finally, if the solar panel is also grid-connected to the home energy system, the robust appliance scheduling approach in [119] outperforms the base case by 34.9–86.6%. It can be noted that the B-RT and B-DA scenarios limited to the load scheduling capabilities always lead to higher bills than the corresponding flat price scenario. This illustrates suboptimal energy utilization when residential customers are to cope with dynamic pricing environments not equipped with the proper decision tools. It can also be concluded that the modeling framework proposed in [119] will lead to significant economic savings for both the energy consumer and provider.
6. Conclusions

In the smart grid environment, the smart house with its HEMS plays an important role in the intelligent use of electricity and demand response. The smart HEMS with wireless networks, smart home appliances, digital citizen services, and smart sensor technologies could elevate standards of living and commerce with social and environmental capitals. In recent years, the popularity of HEMS has been increased significantly due to high accessibility, convenience and affordability via smart phone and tablet connectivity. Meanwhile, the development of modernized smart grid infrastructures with a variety of two-way communication, metering and monitoring devices lays a solid foundation for smart HEMS application. In the near future, the extensive use of HEMS will thoroughly change the way of electricity usage and renewable energy utilization in the residential houses. In this paper, the introduction and description for the overview of HEMS architecture have been illustrated, as well as a detailed investigation on

Table 3
Comparative analysis on electricity cost under different scenarios.
Scenarios | Base case with real-time pricing (B-RT case) ($)

Base case with day-ahead prices (B-DA case) ($)

The robust approach proposed in [119] ($)

Appliance scheduling | 14.35 | 14.17 | 12.78
Adding energy storage system 13.50 | 13.02 | 10.26
Adding electricity selling | 13.48 | 11.52 | 6.23
Adding solar PV panels | 4.39 | 6.43 | 0.59
Adding DER set | 2.53 | 6.22 | 0.42
38 | B. Zhou et al. / Renewable and Sustainable Energy Reviews 61 (2016) 30–40

the functions of renewable energy, HESSs, home appliances and demand response in HEMS. On the other hand, the utilization of renewable energy in buildings is becoming increasingly widespread. Findings show that solar energy is a main contributor to home energy consumption, while the wind, biomass, and geothermal energy often contribute relatively less and limited due to urban geography and climate factors. The utilization of building renewable energy also demonstrates that remarkable energy savings could be achieved from transmission energy losses and traditional primary energy. Furthermore, the home scheduling strategies for smart appliances, renewable energy and HESS have been investigated and analyzed to reduce the residential electricity cost and improve energy utilization from electric power utilities. Consequently, developing the smart HEMS has become a common global priority to support the trend towards a more sustainable and reliable green energy supply for smart grid.

Acknowledgements

The authors gratefully acknowledge the support of the National Natural Science Foundation of China (Key Program: 51137003), the National Natural Science Foundation of China (51507056), the Fundamental Research Funds for the Central Universities (Grant number 531107040841), and also would like to express our sincere thanks to the organizations and individuals whose literatures have been cited in this paper.

References

[1] Amin M. Minimizing failure while maintaing efficiency of complex interactive networks and systems: EPRI and US Department of Defense Complex interactive networks/systems initiative; First Annual Report; 2000.
[2] Haase P. Intelli grid: a smart network of power. EPRI J 2005:17–25 (http://refhub.elsevier.com/S1364-0321(16)00282-3/sbref1). (http://refhub.elsevier.com/S1364-0321(16)00282-3/sbref1)
[3] Profiling and mapping of intelligent grid R & D programs. EPRI 2006.
[4] European smart-grids technology platform: vision and strategy for Europe's electricity networks of the future. Directorate-General for Research Sustainable Energy Systems; 2006.
[5] Obama. Remarks by the president on recovery act funding for smart grid technology; 2009.
[6] IEEE. IEEE provides leadership for smart grid initiative around the globe; 2009.
[7] Chen SY, Song SF, Li LX, et al. Survey on smart grid technology. Power Syst Technol 2009;33(8):1–7 (http://refhub.elsevier.com/S1364-0321(16)00282-3/sbref2). (http://refhub.elsevier.com/S1364-0321(16)00282-3/sbref2)
[8] Kirschen DS. Demand-side view of electricity markets. IEEE Trans Power Syst 2003;18(2):502–7 (http://refhub.elsevier.com/S1364-0321(16)00282-3/sbref3). (http://refhub.elsevier.com/S1364-0321(16)00282-3/sbref3)
[9] Liu ZY. Basic knowledge of smart grid. Beijing: China Electric Power Press; 2010. (http://refhub.elsevier.com/S1364-0321(16)00282-3/sbref4)
[10] Brooks A, Lu E, Reicher D, Spirakis C, Weihl B. Demand dispatch. IEEE Power Energy Mag 2010;8(3):20–9 (http://refhub.elsevier.com/S1364-0321(16)00282-3/sbref5). (http://refhub.elsevier.com/S1364-0321(16)00282-3/sbref5)
[11] Vojdani A. Smart integration—the smart grid needs infrastructure that is dynamic and flexible. IEEE Power Energy Mag 2008;6(6):71–9 (http://refhub.elsevier.com/S1364-0321(16)00282-3/sbref6). (http://refhub.elsevier.com/S1364-0321(16)00282-3/sbref6)
[12] Farhangi H. The path of the smart grid. IEEE Power Energy Mag 2009;8 (1):18–28 (http://refhub.elsevier.com/S1364-0321(16)00282-3/sbref7). (http://refhub.elsevier.com/S1364-0321(16)00282-3/sbref7)
[13] Zhang P, Li C, Bhatt N. Next-generation monitoring, analysis, and control for the future smart control center. IEEE Trans Smart Grid 2010;1(2):186–92 (http://refhub.elsevier.com/S1364-0321(16)00282-3/sbref8). (http://refhub.elsevier.com/S1364-0321(16)00282-3/sbref8)
[14] Kantarci ME, Mouftah HT. Wireless multimedia sensor and actor networks for the next-generation power grid. AdHoc Netw 2011;9(4):542–51 (http://refhub.elsevier.com/S1364-0321(16)00282-3/sbref9). (http://refhub.elsevier.com/S1364-0321(16)00282-3/sbref9)
[15] Ali ARA, Hag AE, Bahadiri M, Harbaji M, Yousef AEH. Smart home renewable energy management system. Energy Proced 2011;12:120–6 (http://refhub.elsevier.com/S1364-0321(16)00282-3/sbref10). (http://refhub.elsevier.com/S1364-0321(16)00282-3/sbref10)
[16] Li C, Shi H, Cao Y, Wang J, Kuang Y, Tan Y. Comprehensive review of renewable energy curtailment and avoidance: a specific example in China. Renew Sustain Energy Rev 2015;41:1067–79 (http://refhub.elsevier.com/S1364-0321(16)00282-3/sbref11). (http://refhub.elsevier.com/S1364-0321(16)00282-3/sbref11)
[17] Ma O, Alkadi N, Cappers P, Denholm P. Demand response for ancillary services. IEEE Trans Smart Grid 2013;4(4):1988–95 (http://refhub.elsevier.com/S1364-0321(16)00282-3/sbref12). (http://refhub.elsevier.com/S1364-0321(16)00282-3/sbref12)
[18] Li SH, Zhang D, Roget AB, O’Neill Z. Integrating home energy simulation and dynamic electricity price for demand response study. IEEE Trans Smart Grid 2014;5(2):779–88 (http://refhub.elsevier.com/S1364-0321(16)00282-3/sbref13). (http://refhub.elsevier.com/S1364-0321(16)00282-3/sbref13)
[19] Zhou S, Wu Z, Li J, Zhang X. Real-time energy control approach for smart home energy management system. Electr Power Compon Syst 2014;42:315–26 (http://refhub.elsevier.com/S1364-0321(16)00282-3/sbref14). (http://refhub.elsevier.com/S1364-0321(16)00282-3/sbref14)
[20] Benefits of demand response in electricity markets and recommendations for achieving them. U.S. Department of Energy; 2006.
[21] Zhao Y, Sheng W, Sun J, Shi W. Research and thinking of friendly smart home energy system based on smart power. Electr Control Eng ((ICECE)) 2011:4649–54 (http://refhub.elsevier.com/S1364-0321(16)00282-3/sbref15). (http://refhub.elsevier.com/S1364-0321(16)00282-3/sbref15)
[22] Tompros S, Mouratidis N, Draaijer M, Foglar A, Hrasnica H. Enabling applicability of energy saving applications on the appliances of the home environment. IEEE Netw 2009;23:8–16 (http://refhub.elsevier.com/S1364-0321(16)00282-3/sbref16). (http://refhub.elsevier.com/S1364-0321(16)00282-3/sbref16)
[23] Parvania M, Firuzabad MF. Demand response scheduling by stochastic SCUC. IEEE Trans Smart Grid 2010;1:1. (http://refhub.elsevier.com/S1364-0321(16)00282-3/sbref17)
[24] Kahrobaee S, Rajabzadeh RA, Kiat SL, Asgarpoor S. A multiagent modeling and investigation of smart homes with power generation, storage, and trading features. IEEE Trans Smart Grid 2013;4(2):659–68 (http://refhub.elsevier.com/S1364-0321(16)00282-3/sbref18). (http://refhub.elsevier.com/S1364-0321(16)00282-3/sbref18)
[25] Tsui KM, Chan SC. Demand response optimization for smart home scheduling under real-time pricing. IEEE Trans Smart Grid 2012;3:4. (http://refhub.elsevier.com/S1364-0321(16)00282-3/sbref19)
[26] Han J, Choi CS, Park WK, Lee I. Green home energy management system through comparison of energy usage between the same kinds of home appliances. In: Proceedings of the 15h IEEE international symposium on consumer electronics (ISCE); 2011: p. 1–4.
[27] Son YS and Moon KD. Home energy management system based on power line communication. In: Proceedings of the 28th international conference on consumer electronics (ICCE) 2010.
[28] Han J, Choi CS, and Lee I. More efficient home energy management system based on ZigBee communication and infrared remote controls. In: Proceedings of the 29th international conference on consumer electronics (ICCE); 2011.
[29] Jeong Li, Sic CC, Ki PW, Soo HJ, Woo Li. A study on the use cases of the smart grid home energy management system. In: Proceedings of the international conference on ICT convergence (ICTC); 2011. p. 746–50.
[30] Kuzlu M, Pipattanasomporn M, Rahman S. Hardware demonstration of a home energy management system for demand response applications. IEEE Trans Smart Grid 2012;3(4):1704–11 (http://refhub.elsevier.com/S1364-0321(16)00282-3/sbref20). (http://refhub.elsevier.com/S1364-0321(16)00282-3/sbref20)
[31] Dimeas A, Drenkard S, Hatziargyriou N, Karnouskos S, Kok K, Ringelstein J, Weidlich A. Smart houses in the smart grid: developing an interactive network. IEEE Electr Mag 2014;2(1):81–93 (http://refhub.elsevier.com/S1364-0321(16)00282-3/sbref21). (http://refhub.elsevier.com/S1364-0321(16)00282-3/sbref21)
[32] Mesarića P, Krajcarb S. Home demand side management integrated with electric vehicles and renewable energy sources. Energy Build 2015;108 (1):1–9 (http://refhub.elsevier.com/S1364-0321(16)00282-3/sbref22). (http://refhub.elsevier.com/S1364-0321(16)00282-3/sbref22)
[33] Missaoui R, Joumaa H, Ploix S, Bacha S. Managing energy smart homes according to energy prices: analysis of a building energy management system. Energy Build 2014;71:155–67 (http://refhub.elsevier.com/S1364-0321(16)00282-3/sbref23). (http://refhub.elsevier.com/S1364-0321(16)00282-3/sbref23)
[34] Asare B, Kling WL, Ribeiro PF. Home energy management systems: evolution, trends and frameworks. In: Proceedings of the universities power engineering conference; 2014: p. 1–5.
[35] Ali AR, Hag AE, Bahadiri M, Harbaji M, Haj YAE. Smart home renewable energy management system. Energy Proced 2011;12:120–6 (http://refhub.elsevier.com/S1364-0321(16)00282-3/sbref24). (http://refhub.elsevier.com/S1364-0321(16)00282-3/sbref24)
[36] Son YS, Pulkkinen T, Moon KD, Kim C. Home energy management system based on power line communication. IEEE Trans Consum Electron 2010;56 (3):1380–6 (http://refhub.elsevier.com/S1364-0321(16)00282-3/sbref25). (http://refhub.elsevier.com/S1364-0321(16)00282-3/sbref25)
[37] Dam SS, Bakker CA, Buiter JC. Do home energy management systems make sense? Assessing their overall lifecycle impact Energy Policy 2013;63:398–407 (http://refhub.elsevier.com/S1364-0321(16)00282-3/sbref26). (http://refhub.elsevier.com/S1364-0321(16)00282-3/sbref26)
[38] Zhang Y, Zeng P, Zang C. Review of home energy management system in smart grid. Power Syst Protect Control 2014;42(18):144–54 (http://refhub.elsevier.com/S1364-0321(16)00282-3/sbref27) [in Chinese. (http://refhub.elsevier.com/S1364-0321(16)00282-3/sbref27)
[39] Han D, Lim J. Design and implementation of smart home energy management systems based on ZigBee. IEEE Trans Consum Electron 2010;56(3):1417–25 (http://refhub.elsevier.com/S1364-0321(16)00282-3/sbref28). (http://refhub.elsevier.com/S1364-0321(16)00282-3/sbref28)
[40] Inoue M, Higuma T, Ito Y, Kushiro N, Kubota H. Network architecture for home energy management system. IEEE Trans Consum Electron 2003;49:606–13 (http://refhub.elsevier.com/S1364-0321(16)00282-3/sbref29). (http://refhub.elsevier.com/S1364-0321(16)00282-3/sbref29)
[41] Kantarci ME, Mouftah HT. Wireless sensor networks for cost efficient residential energy management in the smart grid. IEEE Trans Smart Grid 2011;2 (2):314–25 (http://refhub.elsevier.com/S1364-0321(16)00282-3/sbref30). (http://refhub.elsevier.com/S1364-0321(16)00282-3/sbref30)
[42] Hu QR, Li FX. Hardware design of smart home energy management system with dynamic price response. IEEE Trans Smart Grid 2013;4(4):1878–87 (http://refhub.elsevier.com/S1364-0321(16)00282-3/sbref31). (http://refhub.elsevier.com/S1364-0321(16)00282-3/sbref31)
[43] Song G, Ding F, Zhang W, Song A. A wireless power outlet system for smart homes. IEEE Trans Consum Electron 2008;54(4):1688–91 (http://refhub.elsevier.com/S1364-0321(16)00282-3/sbref32). (http://refhub.elsevier.com/S1364-0321(16)00282-3/sbref32)
[44] Kuzlu M, Pipattanasomporn M, Rahman S. Hardware demonstration of a home energy management system for demand response applications. IEEE Trans Smart Grid 2012;3(4):1704–11 (http://refhub.elsevier.com/S1364-0321(16)00282-3/sbref33). (http://refhub.elsevier.com/S1364-0321(16)00282-3/sbref33)
[45] Lilakiatsakun W, Seneviratne A. Wireless home networks based on a hierarchical bluetooth scatternet architecture. In: Proceedings of the 9th IEEE international conference on networks 2001: p. 481–85.
[46] KastnerW Neugschwandtner G, Soucek S, Newmann HM. Communication systems for building automation and control. Proc IEEE 2005;93:6. (http://refhub.elsevier.com/S1364-0321(16)00282-3/sbref34)
[47] Benzi F, Anglani N, Bassi E, Frosini L. Electricity smart meters interfacing the households. IEEE Trans Ind Electron 2011;58(10):4487–94 (http://refhub.elsevier.com/S1364-0321(16)00282-3/sbref35). (http://refhub.elsevier.com/S1364-0321(16)00282-3/sbref35)
[48] Depuru SSSR, Wang L, Devabhaktuni V, Gudi N. Smart meters for power grid – challenges, issues, advantages and status. In: Proceedings of the power systems conference and exposition (PSCE) 2011: p. 1–7.
[49] Arif A, Hussain AM, Mutairi AN, Ammar AE, Khan Y, Malik N. Experimental study and design of smart energy meter for the smart grid. In: Proceedings of the renewable and sustainable energy conference (IRSEC) 2013: p. 515–20.
[50] Zheng J, Gao DW, Lin L. Smart meters in smart grid: an overview. In: Proceedings of the green technologies conference; 2013: p. 57–64.
[51] Zhao Z, Lee WC, Shin Y, Song K. An optimal power scheduling method for demand response in home energy management system. IEEE Trans Smart Grid 2013;4(3):1391–400 (http://refhub.elsevier.com/S1364-0321(16)00282-3/sbref36). (http://refhub.elsevier.com/S1364-0321(16)00282-3/sbref36)
[52] Phani C, Yang P, Nehorai A. A distributed algorithm of appliance scheduling for home energy management system. IEEE Trans Smart Grid 2014;5(1):282–90 (http://refhub.elsevier.com/S1364-0321(16)00282-3/sbref37). (http://refhub.elsevier.com/S1364-0321(16)00282-3/sbref37)
[53] Ma Y, Houghton T, Cruden A, Infield D. Modeling the benefits of vehicleto-grid technology to a power system. IEEE Trans Power Syst 2012;27 (2):1012–20 (http://refhub.elsevier.com/S1364-0321(16)00282-3/sbref38). (http://refhub.elsevier.com/S1364-0321(16)00282-3/sbref38)
B. Zhou et al. / Renewable and Sustainable Energy Reviews 61 (2016) 30–40 | 39

[54] Tu Y, Li C, Cheng L, Le L. Research on vehicle-to-grid technology. Comput Distr Contr Intell Environ Monit ((CDCIEM)) 2011:1013–6 (http://refhub.elsevier.com/S1364-0321(16)00282-3/sbref39). (http://refhub.elsevier.com/S1364-0321(16)00282-3/sbref39)
[55] Kempton W, Tomić J. Vehicle-to-grid power fundamentals: calculating capacity and net revenue. J Power Sources 2005;144:268–79 (http://refhub.elsevier.com/S1364-0321(16)00282-3/sbref40). (http://refhub.elsevier.com/S1364-0321(16)00282-3/sbref40)
[56] Kempton W, Steven EL. Electric vehicles as a new source of power for electric utilities. Transp Res 1997;2(3):157–75 (http://refhub.elsevier.com/S1364-0321(16)00282-3/sbref41). (http://refhub.elsevier.com/S1364-0321(16)00282-3/sbref41)
[57] Andersson SL, Elofsson AK. Plug-in hybrid electric vehicles as regulating power providers: case studies of Sweden and Germany. Energy Policy 2010:38. (http://refhub.elsevier.com/S1364-0321(16)00282-3/sbref42)
[58] IEA. Renewables information 2014. International Energy Agency 2014.
[59] GENI. Renewable energy potential of small island states. Global Energy Network Institute; August 2008. Available at:〈http://www.geni.org/globalenergy/library/technical-articles/generation/small-island-nations/renewableenergy-potential-of-small-island-states/Renewable%20Energy%20Pot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〉. (http://www.geni.org/globalenergy/library/technical-articles/generation/small-island-nations/renewable-energy-potential-of-small-island-states/Renewable%20Ener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)
[60] Vijayapriya T, Kothari D. Smart grid: an overview. Smart Grid Renew Energy 2011;2(4):305–11 (http://refhub.elsevier.com/S1364-0321(16)00282-3/sbref43). (http://refhub.elsevier.com/S1364-0321(16)00282-3/sbref43)
[61] The Reegle Portal. Available at: 〈http://www.reegle.info/policy-and-regulatory-overviews/DE〉. (http://www.reegle.info/policy-and-regulatory-overviews/DE)
[62] Dena - German energy agency. Bruttostromerzeugung in Deutschland. 2012. [Online]. Available at: 〈http://www.thema-energie.de/energie-im-ueberblick/daten-fakten/statistiken/energieerzeugung/bruttostromerzeugung-indeutschland.html〉. (http://www.thema-energie.de/energie-im-ueberblick/daten-fakten/statistiken/energieerzeugung/bruttostromerzeugung-in-deutschland.html)
[63] IRENA. Feed-in tariff specifications, features, amendments, and current and future challenges in Cyprus. Int Renew Energy Agency 2013. (http://refhub.elsevier.com/S1364-0321(16)00282-3/sbref44)
[64] The reegle portal. Available at: 〈http://www.reegle.info/policy-and-regulatory-overviews/CN〉. (http://www.reegle.info/policy-and-regulatory-overviews/CN)
[65] Fthenakis V, Kim HC. Land use and electricity generation: a life-cycle analysis. Renewable and Sustainable Energy Reviews 2009;13(6-7):1465–74 (http://refhub.elsevier.com/S1364-0321(16)00282-3/sbref45). (http://refhub.elsevier.com/S1364-0321(16)00282-3/sbref45)
[66] Available at: 〈http://online.wsj.com/articles/denmarks-wind-power-outputrises-to-record-in-first-half-1409750563〉. (http://online.wsj.com/articles/denmarks-wind-power-output-rises-to-record-in-first-half-1409750563)
[67] Vittrup C. was a record-setting year for Danish wind power. Energinet. dk 2013;2014:20. (http://refhub.elsevier.com/S1364-0321(16)00282-3/sbref46)
[68] REN21 (2011). Renewables 2011: global status report. 2011.〈http://germanwatch.org/klima/gsr2011.pdf〉. (http://germanwatch.org/klima/gsr2011.pdf)
[69] The World Wind Energy Association. Half-year Report. WWEA; 2014: p. 1–8.
[70] Raadala HL, Gagnonb L, Modahla IS, Hanssena OJ. Life cycle greenhouse gas (GHG) emissions from the generation of wind and hydro powerr. Renew Sustain Energy Rev 2011:3417–22 (http://refhub.elsevier.com/S1364-0321(16)00282-3/sbref47). (http://refhub.elsevier.com/S1364-0321(16)00282-3/sbref47)
[71] The feasibility of building-mounted/integrated wind turbines (BUWTs): achieving their potential for carbon emission. Energy Research. (5) 2005. p. 17–89.
[72] Bertani R. Geothermal power generation in the world 2005–2010 update report. Geothermics; 2012: p. 1–29.
[73] Gunnarsson A. Geothermal power in Iceland. In: Proceedings of the power engineering society summer meeting; 2002. p. 1.
[74] Parida B, Inivan S, Goic R. A review of solar photovoltaic technologies. Renew Sustain Energy Rev 2011;15(3):1625–36 (http://refhub.elsevier.com/S1364-0321(16)00282-3/sbref48). (http://refhub.elsevier.com/S1364-0321(16)00282-3/sbref48)
[75] Anja S, Sc M. Analysis of the potential solar energy market in the Caribbean. OECD library; July 2010. Available at:〈http://www.credp.org/Data/Solar_Market_Analysis_Caribbean.pdf〉. (http://www.credp.org/Data/Solar_Market_Analysis_Caribbean.pdf)
[76] World Energy Resources: 2013 Survey. World Energy Council; 2013. Available at:〈http://www.worldenergy.org/wp-content/uploads/2013/10/WER_2013_8_Solar_revised.pdf〉. (http://www.worldenergy.org/wp-content/uploads/2013/10/WER_2013_8_Solar_revised.pdf)
[77] Live Science Survey. 2012. Available at:〈http://www.livescience.com/en energy.html〉. (http://www.livescience.com/enenergy.html)
[78] Wan C, Zhao J, Song Y, Xu Z. Photovoltaic and solar power forecasting for smart grid energy management. CSEE J Power Energy Syst 2015;1(4):38–46 (http://refhub.elsevier.com/S1364-0321(16)00282-3/sbref5050). (http://refhub.elsevier.com/S1364-0321(16)00282-3/sbref5050)
[79] Tascikaraoglu A, Boynuegri AR, Uzunoglu M. A demand side management strategy based on forecasting of residential renewable sources: a smart home system in Turkey. Energy Build 2014;80:309–20 (http://refhub.elsevier.com/S1364-0321(16)00282-3/sbref49). (http://refhub.elsevier.com/S1364-0321(16)00282-3/sbref49)
[80] Vervaart MR, Nieuwenhout FDJ. SOLAR HOME SYSTEMS 2000. (http://refhub.elsevier.com/S1364-0321(16)00282-3/sbref50)
[81] Harrington S, Dunlop J. Battery charge controller characteristics in photovoltaic systems. IEEE Trans Aerosp Electron Syst Mag 1992;7(8):15–21 (http://refhub.elsevier.com/S1364-0321(16)00282-3/sbref51). (http://refhub.elsevier.com/S1364-0321(16)00282-3/sbref51)
[82] Luo FL, Ye H. Laddered multilevel DC/AC inverters used in solar panel energy systems. Power Electron IET 2013;6(9):1769–77 (http://refhub.elsevier.com/S1364-0321(16)00282-3/sbref52). (http://refhub.elsevier.com/S1364-0321(16)00282-3/sbref52)
[83] Yang XY, Xiao Y, Chen SY. Wind speed and generated power forecasting in wind farm. Proc CSEE 2005;25(11):1–5 (http://refhub.elsevier.com/S1364-0321(16)00282-3/sbref53) [in Chinese. (http://refhub.elsevier.com/S1364-0321(16)00282-3/sbref53)
[84] Ma L, Luan S, Jiang C, Liu H, Zhang Y. A review on the forecasting of wind speed and generated power. Renew Sustain Energy Rev 2009;13(4):915–20 (http://refhub.elsevier.com/S1364-0321(16)00282-3/sbref54). (http://refhub.elsevier.com/S1364-0321(16)00282-3/sbref54)
[85] Mazen R, Radwan M, Abdel SM. Utilization of biomass energy in high-rise buildings. In: Proceedings of the 4th international youth conference on energy (IYCE); 2013: p. 1–3.
[86] The NEED project, Biomass 2012. Available:〈http://www.NEED.org〉, 2012..
[87] Carpioa M, Zamoranob M, Costac M. Impact of using biomass boilers on the energy rating and CO (http://refhub.elsevier.com/S1364-0321(16)00282-3/sbref55)2 (http://refhub.elsevier.com/S1364-0321(16)00282-3/sbref55) emissions of Iberian Peninsula residential buildings. Energy Build 2013;66:732–44 (http://refhub.elsevier.com/S1364-0321(16)00282-3/sbref55). (http://refhub.elsevier.com/S1364-0321(16)00282-3/sbref55)
[88] Šubić MB, Rauch M, Dović D, Andrassy M. Primary energy consumption of the dwelling with solar hot water system and biomass boiler. Energy Conversion Manag 2014;87:1151–61 (http://refhub.elsevier.com/S1364-0321(16)00282-3/sbref56). (http://refhub.elsevier.com/S1364-0321(16)00282-3/sbref56)
[89] Huang Y, Wang YD, Rezvani S, Wright DRM, Anderson M, Hewit NJ. Biomass fuelled trigeneration system in selected buildings. Energy Convers Manag 2011;52(6):2448–54 (http://refhub.elsevier.com/S1364-0321(16)00282-3/sbref57). (http://refhub.elsevier.com/S1364-0321(16)00282-3/sbref57)
[90] Dickson M, Fanelli M. Geothermal background. UNESCO renewable energy series. In: Dickson MH, Fanelli M, editors. Geothermal energy: utilization and technology. London, UK: Earthscan Publications Ltd; 2003. (http://refhub.elsevier.com/S1364-0321(16)00282-3/sbref58)
[91] Fridleifsson I, Bertani R, Huenges E, Lund J, Ragnarsson A, Rybach L. The possible role and contribution of geothermal energy to the mitigation of climate change. In: Homeyer O, Trittin T, (eds). In: Proceedings of the IPCC scoping meeting on renewable energy source; 2008.
[92] Man Y, Yang H, Spitler J, Fang Z. Feasibility study on novel hybrid ground coupled heat pump system with nocturnal cooling radiator for cooling load dominated buildings. Appl Energy 2011:4160–71 (http://refhub.elsevier.com/S1364-0321(16)00282-3/sbref59). (http://refhub.elsevier.com/S1364-0321(16)00282-3/sbref59)
[93] Rosiek S, Batlles FJ. Shallow geothermal energy applied to a solar-assisted air-conditioning system in southern Spain: two-year experience. Appl Energy 2012;100:267–76 (http://refhub.elsevier.com/S1364-0321(16)00282-3/sbref60). (http://refhub.elsevier.com/S1364-0321(16)00282-3/sbref60)
[94] Neves D, Silva CA, Connors S. Design and implementation of hybrid renewable energy systems on micro-communities: a review on case studies. Renew Sustain Energy Rev 2014;31:935–46 (http://refhub.elsevier.com/S1364-0321(16)00282-3/sbref61). (http://refhub.elsevier.com/S1364-0321(16)00282-3/sbref61)
[95] Francisco DG, Andreas S, Oriol GB, Roberto VR. A review of energy storage technologies for wind power applications. Renew Sustain Energy Rev 2012;16(4):2154–71 (http://refhub.elsevier.com/S1364-0321(16)00282-3/sbref62). (http://refhub.elsevier.com/S1364-0321(16)00282-3/sbref62)
[96] Neven D, Maria GC. Increasing renewable energy sources in island energy supply: case study Porto Santo. Renew Sustain Energy Rev 2004;8(4):383–99 (http://refhub.elsevier.com/S1364-0321(16)00282-3/sbref63). (http://refhub.elsevier.com/S1364-0321(16)00282-3/sbref63)
[97] Ma T, Yang HX, Lin L. A feasibility study of a stand-alone hybrid solar–wind– battery system for a remote island. Appl Energy 2014;121:149–58 (http://refhub.elsevier.com/S1364-0321(16)00282-3/sbref64). (http://refhub.elsevier.com/S1364-0321(16)00282-3/sbref64)
[98] Kailas A, Cecchi V, Mukherjee A. A survey of communications and networking technologies for energy management in buildings and home automation. J Comput Netw Commu 2012. (http://refhub.elsevier.com/S1364-0321(16)00282-3/sbref65)
[99] Elta K, Cajsa B, Angela P, Tobias E, Lennart S, Rudi AH. Quantifying distribution-system operators' economic incentives to promote residential demand response. Util Policy 2015;35:28–40 (http://refhub.elsevier.com/S1364-0321(16)00282-3/sbref66). (http://refhub.elsevier.com/S1364-0321(16)00282-3/sbref66)
[100] Matteo M, Beth-Anne S, Giorgio R. Role of residential demand response in modern electricity markets. Renew Sustain Energy Rev 2014;33:546–53 (http://refhub.elsevier.com/S1364-0321(16)00282-3/sbref67). (http://refhub.elsevier.com/S1364-0321(16)00282-3/sbref67)
[101] Zong Y, Kullmann D, Thavlov A, Gehrke O, Bindner HW. Application of model predictive control for active load management in a distributed power system with high wind penetration. IEEE Trans Smart Grid 2012;3(2):1055–62 (http://refhub.elsevier.com/S1364-0321(16)00282-3/sbref68). (http://refhub.elsevier.com/S1364-0321(16)00282-3/sbref68)
[102] Rad MAH, Wong VWS, Jatskevich J, Schober R, Garcia AL. Autonomous demand-side management based on game-theoretic energy consumption scheduling for the future smart grid. IEEE Trans Smart Grid 2010;1(3):302–31 (http://refhub.elsevier.com/S1364-0321(16)00282-3/sbref69). (http://refhub.elsevier.com/S1364-0321(16)00282-3/sbref69)
[103] Nguyen DT, Le LB. Joint optimization of electric vehicle and home energy scheduling considering user comfort preference. IEEE Trans Smart Grid 2014;5(1):188–99 (http://refhub.elsevier.com/S1364-0321(16)00282-3/sbref70). (http://refhub.elsevier.com/S1364-0321(16)00282-3/sbref70)
[104] Pedrasa MAA, Spooner TD, MacGill IF. Coordinated scheduling of residential distributed energy resources to optimize smart home energy services. IEEE Trans Smart Grid 2010;1(2):134–43 (http://refhub.elsevier.com/S1364-0321(16)00282-3/sbref71). (http://refhub.elsevier.com/S1364-0321(16)00282-3/sbref71)
[105] Rad AHM, Garcia AL. Optimal residential load control with price prediction in real-time electricity pricing environments. IEEE Trans Smart Grid 2010;1 (2):120–33 (http://refhub.elsevier.com/S1364-0321(16)00282-3/sbref72). (http://refhub.elsevier.com/S1364-0321(16)00282-3/sbref72)
[106] Corno F, Razzak F. Intelligent energy optimization for user intelligible goals in smart home environments. IEEE Trans Smart Grid 2012;3(4):2128–35 (http://refhub.elsevier.com/S1364-0321(16)00282-3/sbref73). (http://refhub.elsevier.com/S1364-0321(16)00282-3/sbref73)
[107] Konstantinos O, Emmanouil A, Charis S. Frequency-based control of islanded microgrid with renewable energy sources and energy storage. J. Mod. Power Syst Clean Energy 2016;4(1):54–62 (http://refhub.elsevier.com/S1364-0321(16)00282-3/sbref500). (http://refhub.elsevier.com/S1364-0321(16)00282-3/sbref500)
[108] Chen XD, Wei TQ, Hu SY. Uncertainty-aware household appliance scheduling considering dynamic electricity pricing in smart home. IEEE Trans Smart Grid 2013;4(2):932–41 (http://refhub.elsevier.com/S1364-0321(16)00282-3/sbref75). (http://refhub.elsevier.com/S1364-0321(16)00282-3/sbref75)
[109] Chen C, Wang JH, Kishore S. A distributed direct load control approach for large-scale residential demand response. IEEE Trans Power Syst 2014;29 (5):2219–28 (http://refhub.elsevier.com/S1364-0321(16)00282-3/sbref76). (http://refhub.elsevier.com/S1364-0321(16)00282-3/sbref76)
[110] US Department of Energy. Benefits of demand response in electricity markets and recommendations for achieving them: a report to the United State Congress pursuant to section 1252 of the Energy Policy Act of 2005.
[111] Federal Energy Regulatory Commission. Assessment of demand response and advanced metering; 2006. Staff report.
[112] Federal Energy Regulatory Commission. Assessment of demand response and advanced metering; 2007. Staff report.
[113] Zhang Q, Wang X, Wang J, Feng C, Liu L. Survey of demand response research in deregulated electricity markets. Autom Electr Power Syst 2008;32(3):97– 106 (http://refhub.elsevier.com/S1364-0321(16)00282-3/sbref77) [in Chinese. (http://refhub.elsevier.com/S1364-0321(16)00282-3/sbref77)
[114] Ozturk Y, Senthilkumar D, Kumar S, Lee G. An intelligent home energy management system to improve demand response. IEEE Trans Smart Grid 2013;4(2):694–701 (http://refhub.elsevier.com/S1364-0321(16)00282-3/sbref78). (http://refhub.elsevier.com/S1364-0321(16)00282-3/sbref78)
[115] Wang S, Xu X. Optimal and robust control of outdoor ventilation airflow rate for improving energy efficiency and IAQ. Build Environ 2004;39:763–73 (http://refhub.elsevier.com/S1364-0321(16)00282-3/sbref79). (http://refhub.elsevier.com/S1364-0321(16)00282-3/sbref79)
[116] Lopez L, Sanchez F, Hagras H, Callaghan V, An evolutionary algorithm for the off-line data driven generation of fuzzy controllers for intelligent buildings. In: Proceedings of the IEEE international conference on system, man and cybernetics. 1; 2004. p. 42–7.
[117] Dounis AI, Caraiscos C. Advanced control systems engineering for energy and comfort management in a building environment—a review. Renew Sustain Energy Rev 2009;13:1246–61 (http://refhub.elsevier.com/S1364-0321(16)00282-3/sbref80). (http://refhub.elsevier.com/S1364-0321(16)00282-3/sbref80)
[118] Beaudin M, Zareipour H. Home energy management systems: a review of modelling and complexity. Renew Sustain Energy Rev 2015;45:318–35 (http://refhub.elsevier.com/S1364-0321(16)00282-3/sbref81). (http://refhub.elsevier.com/S1364-0321(16)00282-3/sbref81)
[119] Hubert T, Grijalva S. Modeling for residential electricity optimization in dynamic pricing environments. IEEE Trans Smart Grid 2012;3(4):2224–31 (http://refhub.elsevier.com/S1364-0321(16)00282-3/sbref82). (http://refhub.elsevier.com/S1364-0321(16)00282-3/sbref82)
40 | B. Zhou et al. / Renewable and Sustainable Energy Reviews 61 (2016) 30–40

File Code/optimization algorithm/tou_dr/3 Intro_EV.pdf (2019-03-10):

### ENEL 890AO: Computational Methods in Electrical Engineering

Zhanle (Gerald) Wang
Faculty of Engineering
U of R

Introduction of Electric Vehicle

### Electric Vehicle (EV) and EV charging

- Electric cars vs Petrol cars (https://www.youtube.com/watch?v=ewcWN-rHQ6Q)

Advantages • Sustainability • Efficiency • Convenience • Economy

### Sustainability

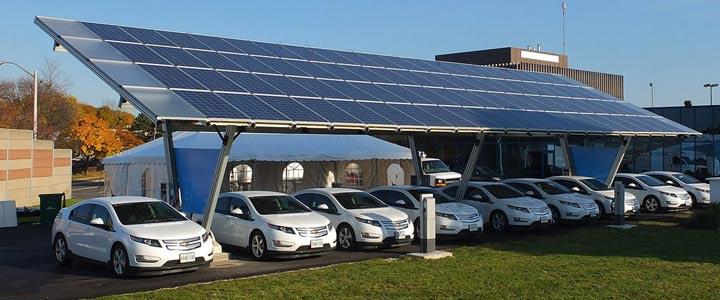
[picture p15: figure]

https://www.solarpowerrocks.com/affordable-solar/how-much-solar-do-i-need-to-charge-my-electric-car/

### Efficiency

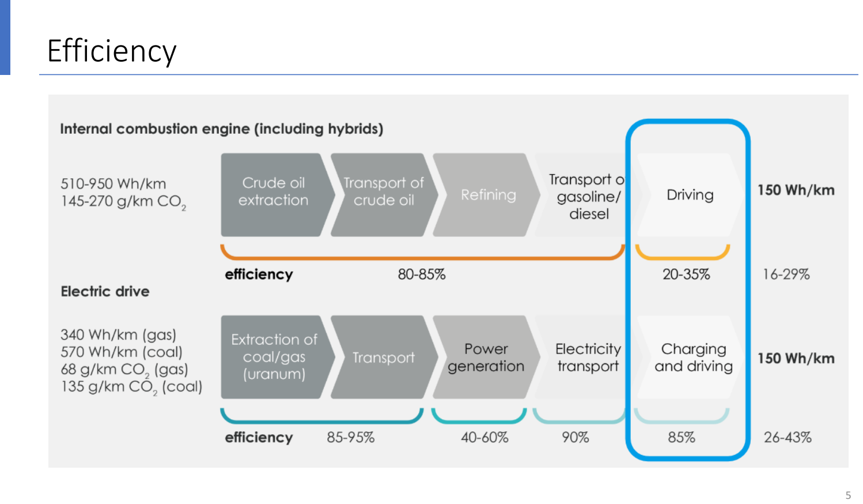
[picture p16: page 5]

### Lower total cost of ownership

- Higher purchase price, but
- Lower maintenance costs
- Lower taxes
- Cheaper fuel (electricity)
- Government subsidy

- Emission Calculator Tool: https://afdc.energy.gov/vehicles/electric_emissions.html
- Fuel Economy Tool:
http://www.fueleconomy.gov/feg/Find.do?action=sbsSelect
- compare the ‘2018 Honda Civic 4Dr, 2.0 L, 4 cyl, Automatic’ and the ‘2018 Tesla Model S AWD - 75D’.
- 33.7 kWh (121 MJ) is equivalent to one gallon gas fuel
- 259 miles is about 417 km

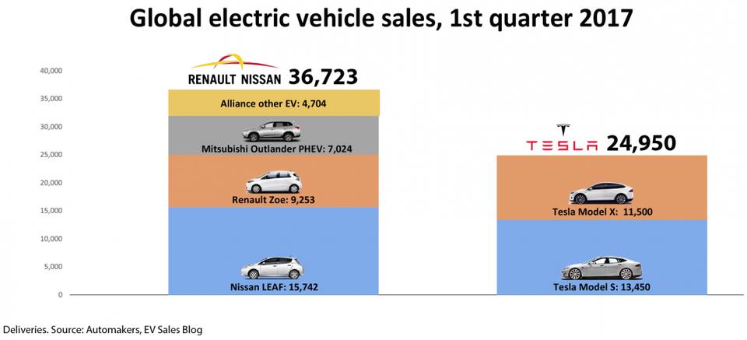
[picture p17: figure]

### Basic EV charging

- Onboard charger: 1.9 – 22 kW
- DC offboard charger: 50 – 350 kW
- Charging level
- Level 1: 0 – 10 kW
- Level 2: 10 – 50 kW
- Level 3: 50 – 350 kW

### Impact on power system

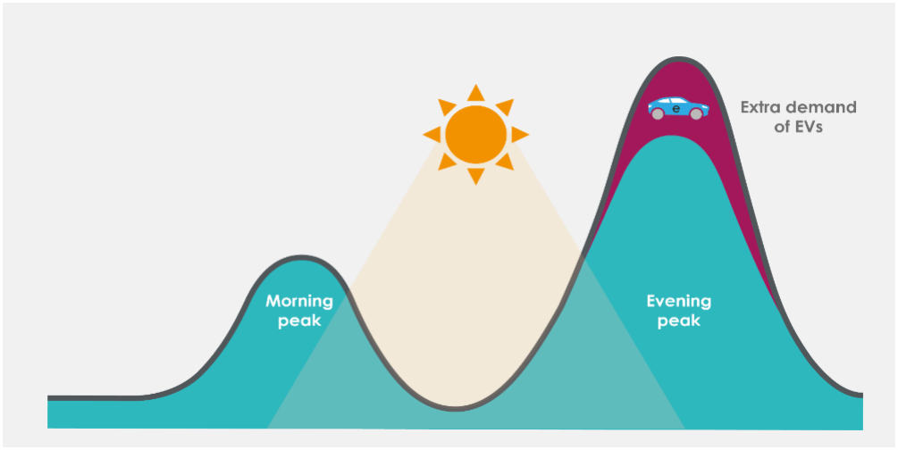
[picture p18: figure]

### Possible solutions

- Grid capacity expansion (expensive)
- Controlled battery charging or Smart charging
- Incentive to user
- Rewarded for flexible load pattern

### Smart Charging

- Smart charging is a series of intelligent functionalities to control the EV charging power in order to create a flexible, sustainable, low cost and efficient charging environment.

### Benefits of smart charging

- Increase the flexibility of charging
- Higher utilization rates of fixed assets
- Efficient utilization of energy in distribution network
- Make electric vehicles more sustainable
- Provide new revenue streams to EV owners

V2G

- Using the electric vehicle battery to feed power back to the grid using a bidirectional EV charger

### V2G advantages and challenges

- Advantage
- Storage for renewables
- Reduce peak demand
- Emergency power
- Ancillary services
- Challenges
- Bidirectional charger
- Battery degradation
- ICT infrastructure
- Standardization and regulatory framework
- Lack of incentives for user

Example applications of smart charging

- Local load balancing
- Adjust charging time/power according to load
- Balance multiple charge points with priority
- Renewable energy utilization
- Price based charging
- Peak shaving
- Grid back up

### Load balancing

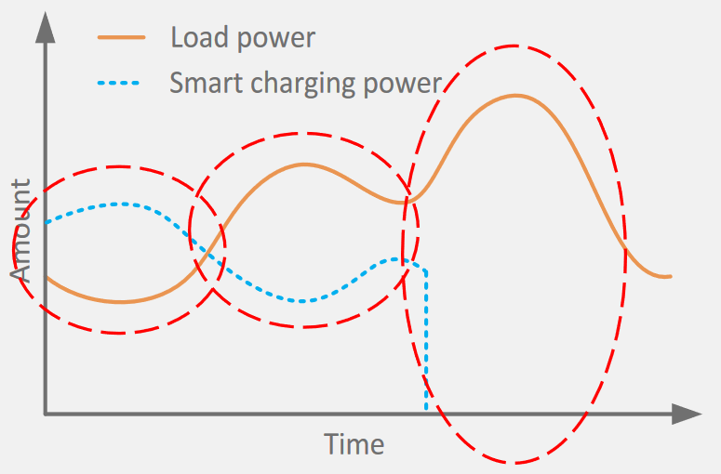
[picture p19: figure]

### Load balancing

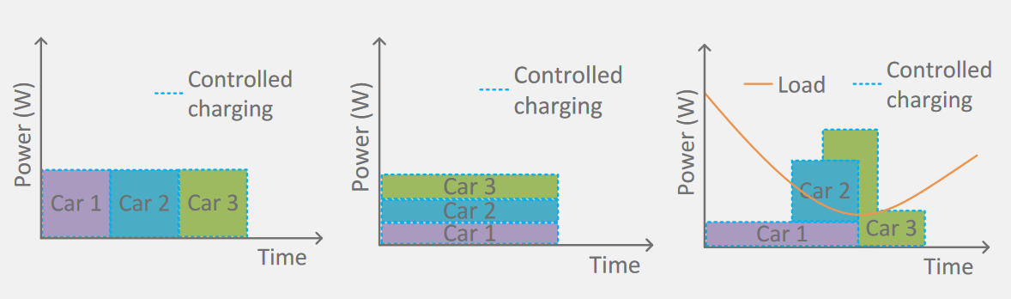
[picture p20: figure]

### Renewable energy availability

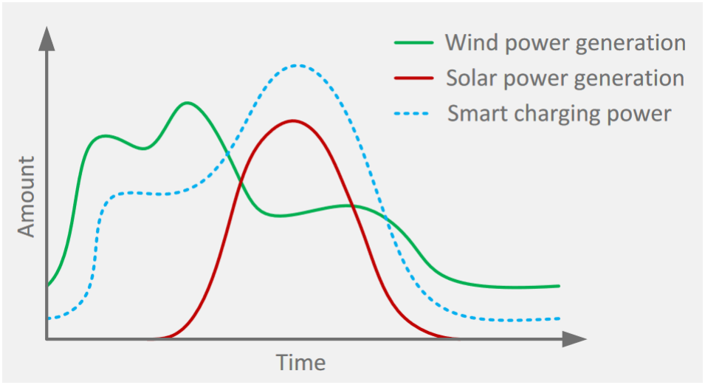
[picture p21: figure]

### Price based charging

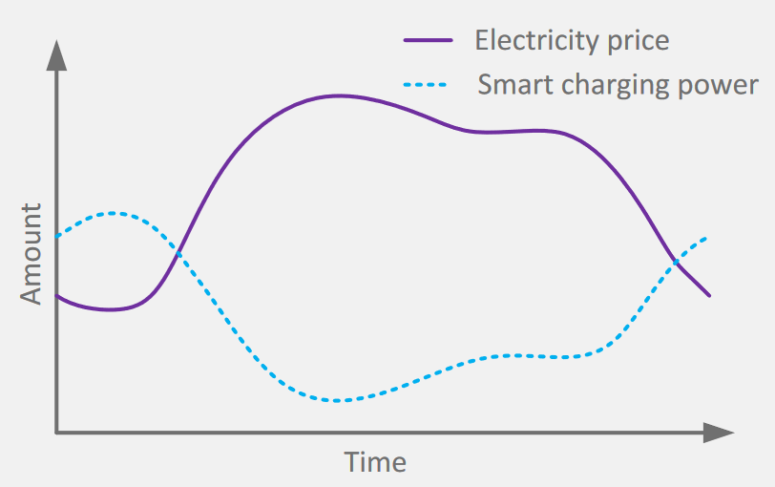
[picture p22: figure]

### Price based charging

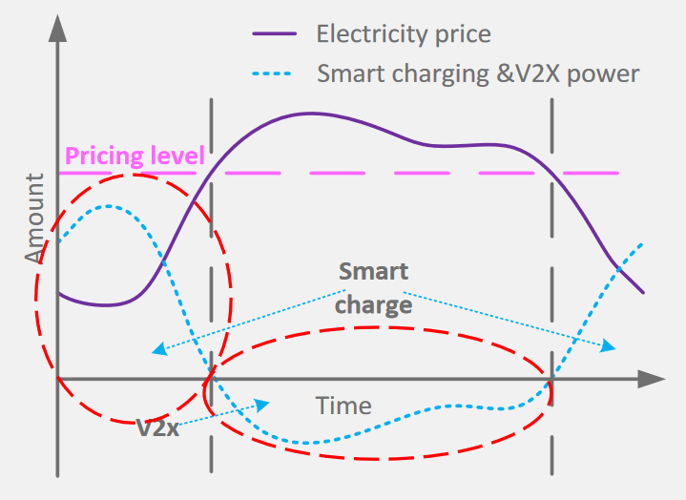
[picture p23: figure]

### Peak shaving

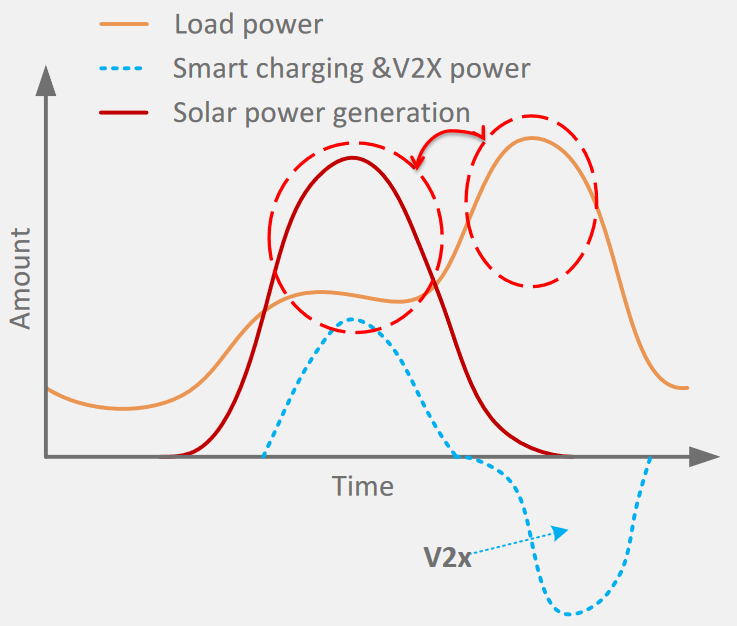
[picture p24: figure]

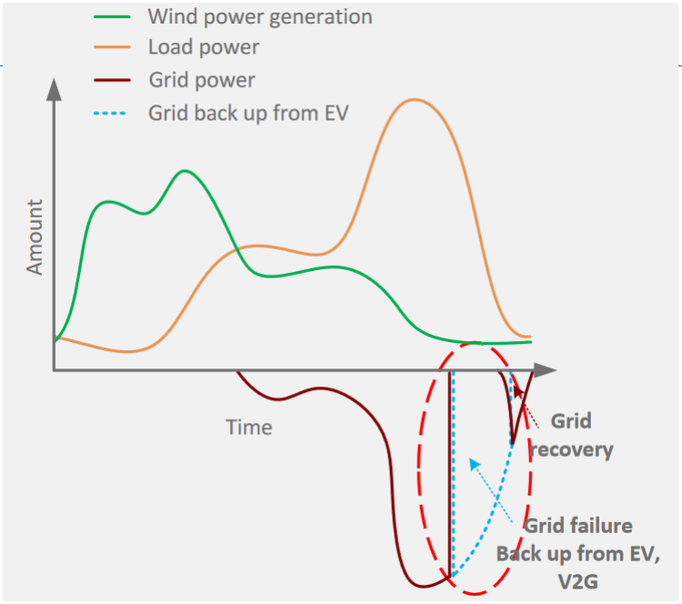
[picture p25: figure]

### Grid backup

### Example: price-based charging

- Capacity: 100 kWh
- Rated charging demand: 10 kW
- State-of-charge (SOC): Available capacity expressed as a percentage of some reference, sometimes its rated capacity. (e.g., empty 0%, full 100%)

### Example: price

### -based charging

-time

Suppose you have a EV with a capacity
of 100 kWh. The rated power of the
charger is 10 kW.
In your neighborhood hourly real
price (RTP) is applied for electricity
usage.
When you arrive home the SOC is
10%, you need to determine the
hourly EV charging schedule to
minimize the electricity cost.

### Example: price-based charging

Suppose you have a EV with a capacity of 100 kWh. The rated power of the charger is 10 kW. In your neighborhood hourly real-time price (RTP) is applied for electricity usage. When you arrive home the SOC is 10%, you need to determine the hourly EV charging schedule to minimize the electricity cost.

### Formulation Steps

- Encode decisions/actions as decision variables whose values we are seeking
- Identify the relevant problem data
- Express constraints on the values of the decision variables as mathematical relationships (inequalities) between the variables and problem data
- Express the objective function as a function of the decision variables and the problem data


### Python code

n = 24
# Construct the problem.

q = cp.Variable(n)
objective = cp.Minimize(p*q)
constraints = [0 <= q, q <= 10, sum(q)==90]
prob = cp.Problem(objective, constraints)

# The optimal objective value is returned by `prob.solve()`. result = prob.solve()

# The optimal value for x is stored in `x.value`. print(q.value)

plt.plot(p)
plt.figure()
plt.plot(q.value)

import pandas as pd
import cvxpy as cp
import matplotlib.pyplot as plt

# read .csv

mp = pd.read_csv("hourlyprice.csv",header=None) # convert dataframe to array
p = mp.values
p = p[0]
p = p/1000

### Matlab code

filename = 'hourlyprice.csv'; p = csvread(filename);
p = p';
p = p/1000; % $/kWh
n=24;
cvx_begin
variable q(n)
minimize( q'*p )
subject to
q<=10;
q>=0;
sum(q) == 100;
cvx_end

%% plot
t=1:24;
[hAx,hLine1,hLine2] = plotyy

(t,p,t,q);
title('Smart Charging')
xlabel('Time')
ylabel

(hAx(1),'Price ($/kWh')
ylabel

(hAx(2),'Charging Demand (kW)') set(hAx(2),'YLim',[

-1 11])
set(hLine1,'Marker','.')
set(hLine2,'Marker','s')

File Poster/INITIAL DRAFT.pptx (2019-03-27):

## MODEL PICTURES

HOME ENERGY MANAGEMENT SYSTEM
(HEMS)

GRAPHS

WITHOUT HEMS


GRAPHS

WITH HEMS

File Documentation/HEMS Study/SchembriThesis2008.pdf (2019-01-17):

i

## The Influence of Home Energy Management Systems on the Behaviours of Residential Electricity Consumers: An Ontario, Canada Case Study

by

### Jeremy Schembri

### A thesis presented to the University of Waterloo in fulfillment of the thesis requirements for the degree of Master of Environmental Studies

in

### Environment and Resource Studies

### Waterloo, Ontario, Canada, 2008

### © Jeremy Schembri 2008

ii

AUTHOR‟S DECLARATION

I hereby declare that I am the sole author of this thesis. This is a true copy of the thesis including any required final revisions, as accepted by my examiners.

I understand that my thesis may be made electronically available to the public.

iii

# Abstract

The current state of Ontario‟s electricity system and natural environment has prompted

the provincial government to call for the province to adopt a „culture of conservation.‟

Answering this call will involve the promotion of a variety of solutions. Included in that

will be the use of information and communication technology, which encompasses

technologies such as home energy management system (HEMS). It is believed that the

feedback and home automation features of the HEMS will enable its users to alter their

electricity consumption behaviours, via net reductions and/or load shifting. This study

has assessed the ability of HEMS to encourage reduction in total and on-peak electricity

consumption while in a time-of-use pricing environment. Additional focus was on which

consumers had the greatest success using the HEMS to adopt electricity conservation

behaviours. Two hundred and sixteen participants of a Milton, Ontario HEMS pilot study

were chosen to take part in this case study. These participants were divided into two

equal groups: a sample group, those who received a HEMS, and a control group, those

who did not receive a HEMS. Participants from both groups were asked to complete two

surveys and allow their electricity consumption data to be analyzed. The initial survey

was to establish some baseline information about the participants. The second survey was

designed to determine if changes had occurred in the household since the initial baseline

survey. Through the analysis of the survey and households electricity consumption data,

conclusions were drawn on how participants used the HEMS. The study had a 2.9%

relative reduction in total electricity consumption and a 13.2% relative reduction in on-

peak electricity consumption. However, additional analysis of the results revealed

promising findings with regard to the HEMS ability to catalyze conservation and demand

management among recent time-of-use pricing adopters.

iv

# Acknowledgements

I would first like to thank Dr. Ian H. Rowlands for having the confidence in me to

undertake a study of this magnitude. His advice and guidance over the years was always

constructive and helpful. I could not have asked for a better supervisor than Professor

Rowlands as his concern for and dedication to his students goes unmatched.

Additional gratitude goes to Milton Hydro Inc.‟s President and CEO, Don Thorne,

and Vice-President Finance, Mary-Jo Corkum, for their continued support of the CDM

research being completed at the University of Waterloo. Also, I would be remised not to

extend a sincere thank you to Andrew Peers of Milton Hydro Inc. Andrew was my

primary contact, he was always quick to assist in any way he could, even when this meant

opening the doors of his home to myself and other project stakeholders.

I am very appreciative to all those at Direct Energy and Bell Canada whom I had

grown to know well over the course of this study. Their hard work and determination in

ensuring that this study was launched was vital to the completion of this thesis. The

completion of this research was made possible thanks to Bell Canada's support through

its Bell University Laboratories R & D program.

The statistical advice of Erin Harvey of the University of Waterloo‟s statistical

consulting services was invaluable and allowed for a more complete statistical analysis

within this thesis. Dr. Paul Parker also provided insights and guidance that allowed for

this work to be well balanced and complete.

I would also like to recognize Chris Lemieux and Jennifer Robinson for sharing

their experiences and advice with me throughout my thesis writing process. Their words

of wisdom and humour kept me level headed and moving forward.

Finally, I would like to thank all my family and friends who supported me

throughout this process. Special thanks to my mother, my brother Josh, and Cassie

Corrigan, each were there when I needed them and always willing to assist when they

could, and for that I am truly grateful.

v
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

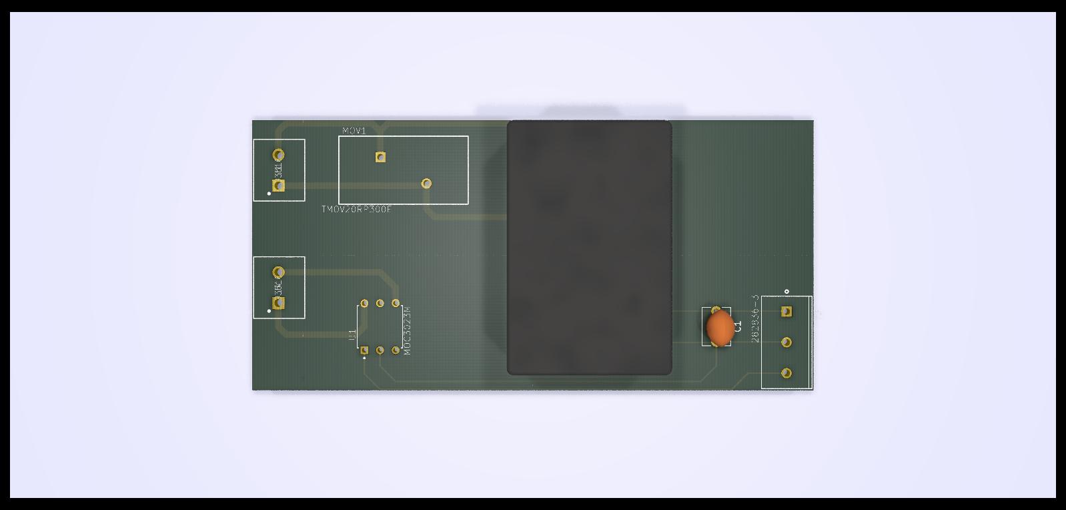
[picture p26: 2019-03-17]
PCB Designs/DEM PCB Design/power supply/Revised PS/initial.jpg

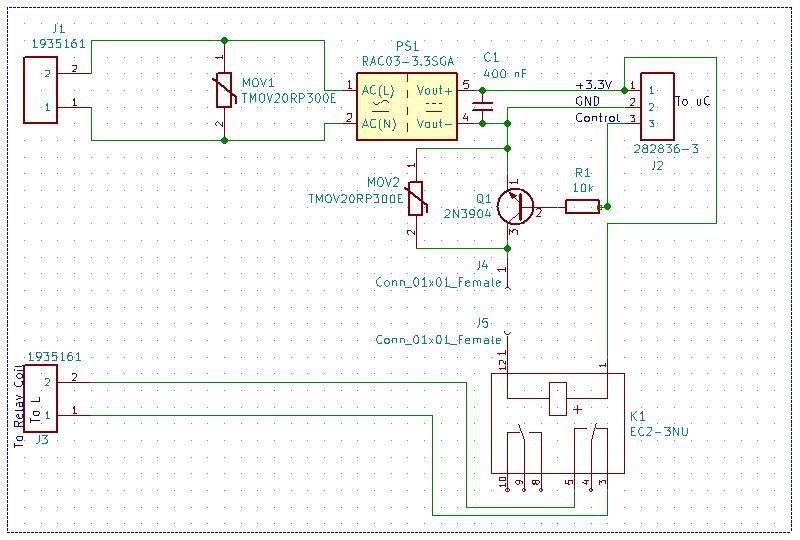
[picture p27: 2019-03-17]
PCB Designs/PCB Final inc. gerber/PS and Switching.JPG

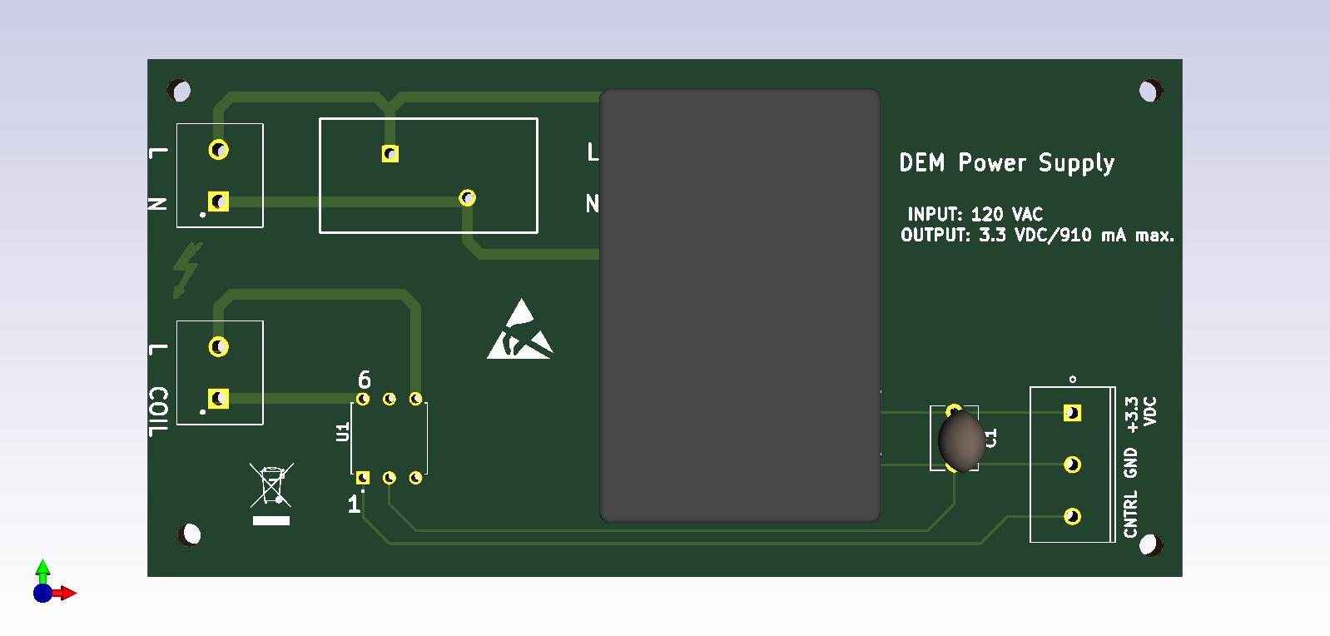
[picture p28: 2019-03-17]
PCB Designs/DEM PCB Design/power supply/Revised PS/rev1.jpg

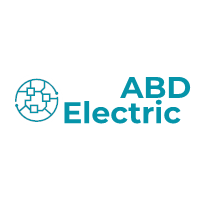
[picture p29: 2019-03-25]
Code/Utility portal/Backend code/Finalrevision/image/abd.png

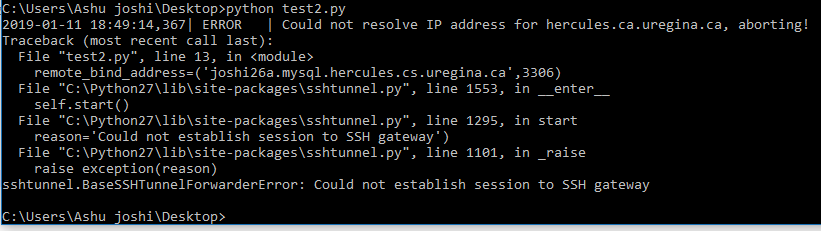
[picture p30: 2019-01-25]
Code/Python to Mysql script/errorscreenshoot.PNG

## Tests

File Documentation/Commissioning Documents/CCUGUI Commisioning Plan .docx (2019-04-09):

| ENEL 417 Capstone project Home Energy Management System (HEMS) Commisioning Plan ------------------------ Central control unit (CCU) User interface APPLICATION WRITTEN BY: Damilola Oludiran

TECHNICAL REQUIREMENTS:

Object-oriented programming (Python Classes and Class methods)

USER INTERFACE APPLICATION SPECIFICATIONS:

SCREENS:

- Home Screen
1. Present Time of Use Billing information in a Graphic and intuitive way
2. Means to access menu of connected appliances and loads (Thermostat and EV)
3. Time/Date and other relevant information
- Menu Screen:
1. Means to access control screens and information for the thermostat and EV
2. Means to return to home screen
- Thermostat Screen:
1. Control the temperature level based on user input
2. Means to switch between Heating and/or Cooling Modes
3. Means to return to previous screen
- EV Screen:
1. Means for Switching the load remotely
2. Means for collecting user scheduling input
3. Means of displaying historical energy consumption
4. Ability to return to previous screen
- Scheduling Screen:
1. Retrieve user input for specifying deadline for appliance
2. Retrieve user input for specifying appliance start times
3. Means to cancel schedule
4. Means to return to previous screen
- Energy consumption Screen:
1. Present Appliance Energy Consumption Data in a Graphical and intuitive way
2. Means to return to previous screen

CENTRAL CONTROL UNIT GRAPHIC USER INTERFACE APPLICATION DESIGN:

OVERVIEW:

1. HOME SCREEN

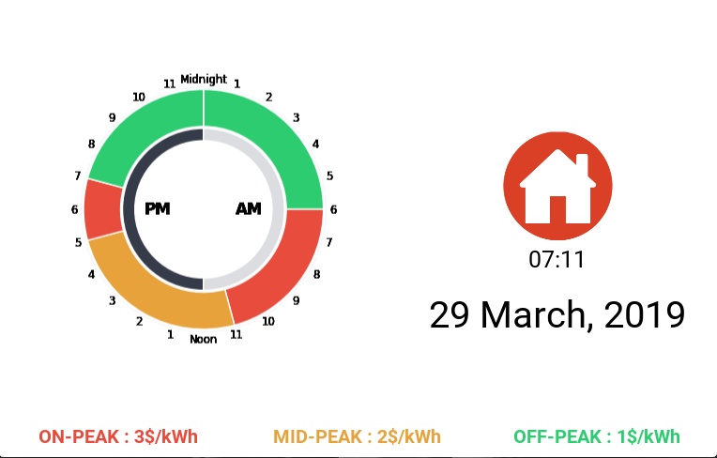
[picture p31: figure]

Purpose: | - Present Dynamic Pricing Data to the User in a Graphical Intuitive way - Means to access menu of connected appliances and loads (Thermostat and EV) - Time/Date and other relevant information
Navigation and User Interaction: | The Time of use pricing data is presented in a 24hour clock format. The various pricing periods of the day are indicated using different colors. Green Indicates Off-Peak, Orange indicates Mid-Peak and Red Indicates On-Peak. The Home icon is a button for accessing the device menu screen. The Daily Pricing information is also presented at the bottom of the screen for reference.

2. MENU SCREEN:

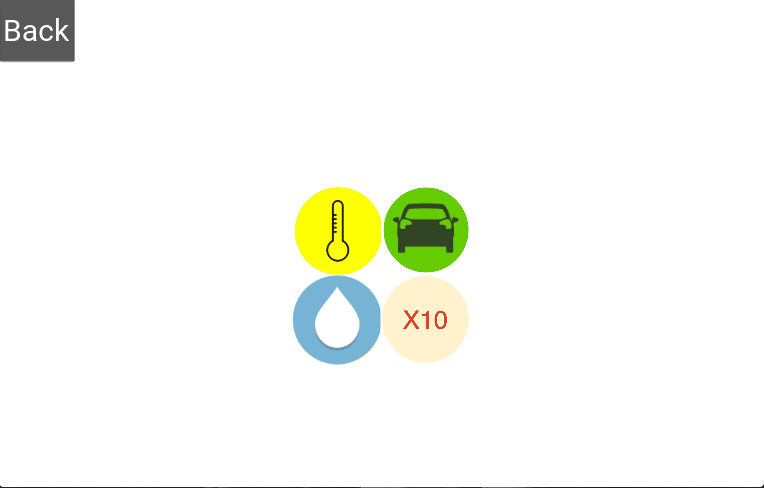
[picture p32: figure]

Purpose: | - Means to access control screens and information for the thermostat and EV - Means to return to home screen
Navigation and User Interaction: | The user can access the profile/information of all connected loads. Each Icon is a button.

3. THERMOSTAT SCREEN:

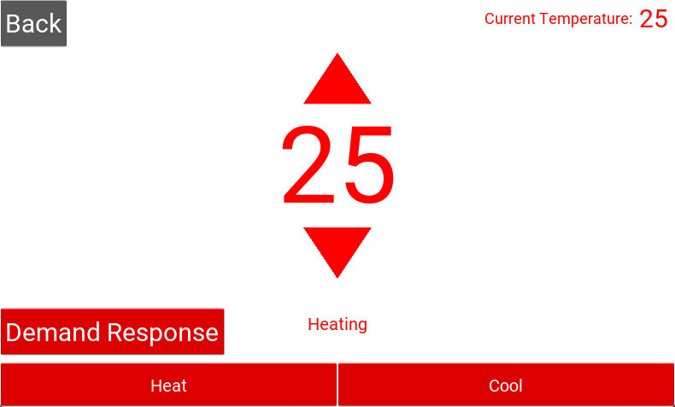
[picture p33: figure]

Purpose: | - Control the temperature level based on user input - Means to switch between Heating and/or Cooling Modes - Means to return to previous screen
Navigation and User Interaction: | The user can control the Home Temperature settings from this interface. The user can also switch between heating and cooling modes and indicate willingness to save costs by selecting a Demand Response mode

4. EV SCREEN:

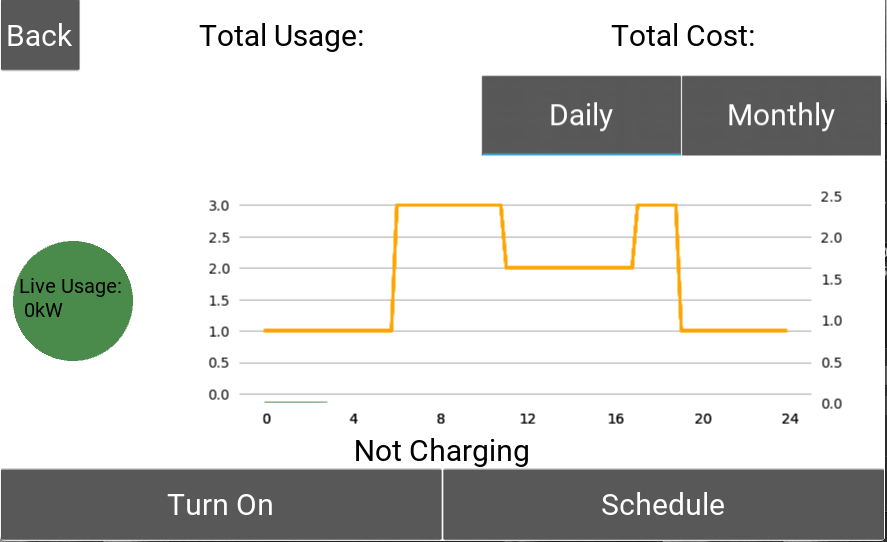
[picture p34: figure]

Purpose: | - Means for Switching the load remotely - Means for collecting user scheduling input - Means of displaying historical energy consumption - Ability to return to previous screen
Navigation and User Interaction: | The user can remotely switch the EV using the Turn on Button. Toggling the button turns the EV charging on or off depending on the previous state. The user can also access a scheduling screen using the schedule button. The real-time power consumption of the load is presented to the user in a graphical plot that shows the pricing information and the real-time load profile of the EV. The total monthly cost and total energy consumed.

5. EV SCHEDULING SCREEN:

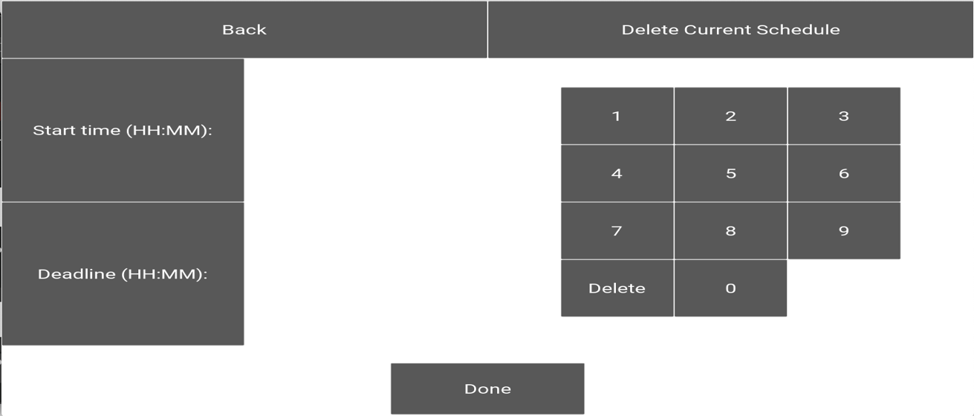
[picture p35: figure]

Purpose: | - Retrieve user input for specifying deadline for appliance - Retrieve user input for specifying appliance start times - Means to cancel schedule - Means to return to previous screen
Navigation and User Interaction: | The user can enter a plug-in time and deadline (when the EV should be fully charged). The schedule is submitted by pushing the “Done” button. the user can also delete the current schedule if optimization is no longer required. The Input format Is also authenticated as

6. ENERGY CONSUMPTION SCREEN:

*See EV Screen Above
Purpose:
Navigation and User Interaction:

CLASS DIAGRAM (OVERVIEW):

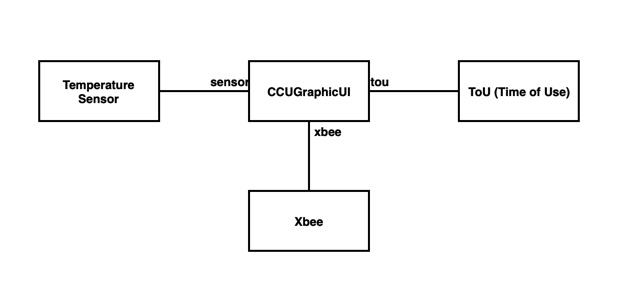
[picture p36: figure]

Figure 1.5: High-level Class Diagram

The figure above represents an overview of the application structure. The system is programmed in python using a multi-threaded approach. The Main application is a user interface application programmed using the Kivy python library. There are three other threads, namely, the ToU, XBee and Temperature Sensor and they are responsible for asynchronously processing the various IOs necessary for system operation. The sequence diagram below shows the inter-thread/ system interaction.

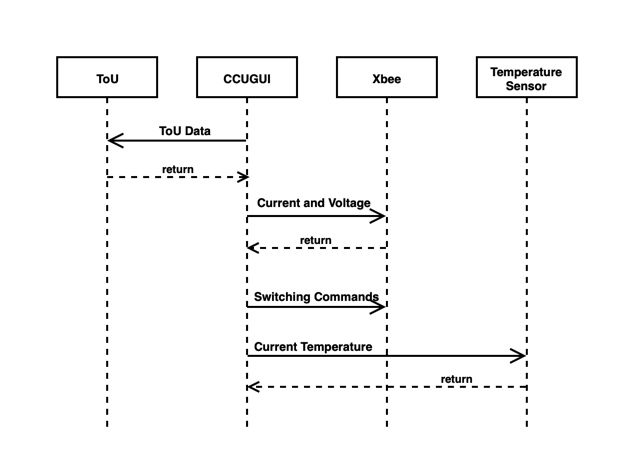
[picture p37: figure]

Figure 1.6: Sequence Diagram

CENTRAL CONTROL UNIT GRAPHIC USER INTERFACE APPLICATION TESTING:

STAND-ALONE TESTING:

The following tests will be performed on the central control unit application to evaluate the design against the design specifications listed above:

1. Log into the utility portal and enter new Time of Use (ToU) pricing information
2. Run the CCUGUI.py program.
3. Confirm that the ToU information displayed on the Home Screen is correct
4. Confirm the current data and time displayed on the home screen
5. Evaluate the home screen based on the following interface specification:

HOME SCREEN:

Specification | Y/N
Retrieve and Present Time of Use Billing information in a Graphic and intuitive way | Yes
Means to access menu of connected appliances and loads (Thermostat and EV) | Yes
Time/Date and other relevant information | Yes

6. Click on the menu button on the home screen
7. Evaluate the menu screen based on the following specifications:

MENU SCREEN:

Specification | Y/N
Access buttons and/or icons for the control screens and information for the thermostat and EV | Yes
Means to return to Home Screen | Yes

8. Click on the thermostat icon
9. Attempt to increase or decrease temperature setting
10. Change from heating to cooling mode
11. Evaluate the screen based on the following specifications:

Thermostat Screen:

Specification | Y/N
Control the temperature level based on user input | Yes
Switch between Heating and/or Cooling Modes | Yes
Means to return to previous screen | Yes

12. Return to the menu screen
13. Select the EV icon
14. Evaluate the screen based on the following specifications:

EV Screen:

Specification | Y/N
Switch the load remotely | Yes
Collect user scheduling input | Yes
Display historical energy consumption | Yes
Return to previous screen | Yes

15. Select the scheduling option
16. Input a test schedule for EV charging at future time
17. Delete Schedule
18. Evaluate the screen based on the following specifications:

SCHEDULING SCREEN:

Specification | Y/N
Specify deadline for appliance in HH:MM time format | Yes
Specify appliance runtime in HH:MM time format | n/a
Specify appliance start times in HH:MM time format | Yes
Cancel schedule | Yes
Return to previous screen | Yes

19. Return to EV screen
20. Select the usage option
21. Evaluate the screen based on the following specifications:

ENERGY CONSUMPTION SCREEN: **see EV Screen

Specification | Y/N
Present Appliance Energy Consumption Data in a Graphical and intuitive way | Yes
Means to return to previous screen | Yes

Scheduling Test Scenario:

Start from 4:00 a.m.

End at 4:00 p.m.

3kWh load at 0.6kW charging point: Approximate Charging Time: 5 hours

Results:

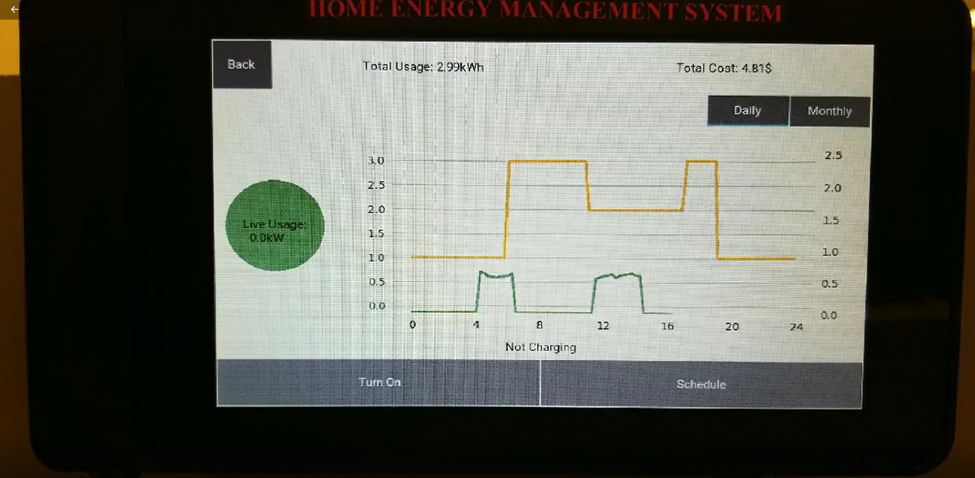
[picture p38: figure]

Comments: We expected the charging to start in the off-peak hours between 4:00am and 6:00am and then stop during the on-peak hours till 11:00am to resume charging till completion before 4:00p.m. Results was as expected.

The working of Optimization and Scheduling was confirmed.

Tested By: Amandeep Joshi, Bikramjit Saini, Damilola Oludiran

Date: 28/03/2019

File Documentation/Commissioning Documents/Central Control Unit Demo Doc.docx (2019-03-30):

Central Control Unit

This unit is responsible for the control and management of the Home Energy Management System. It’s functions include:

- Retrieving the Time of Use pricing information from the Utility Portal
- Retrieving Temperature readings as well as sending control signals to Thermostat subsystem Heater and AC
- Optimization, scheduling and sending control signals to the Device Energy Manager
- Receiving Current and Voltage Measurements from the Device Energy Manager and Computing total energy consumption and cost

Components:

- Raspberry Pi 3B
- 7 inch Official Raspberry Pi Touchscreen Display
- Xbee s2c RF module

Software Architecture Overview:

The Central Control Unit Application Development is done using Python, it consists of a Graphic User Interface developed using the Kivy Framework. Kivy is an open-source cross-platform development python framework using for the development for touch screen applications. The various IO interface and time of use data retrieval is done using python threaded classes that interface and communicate with the system through queues. The figure below shows the high-level system overview.

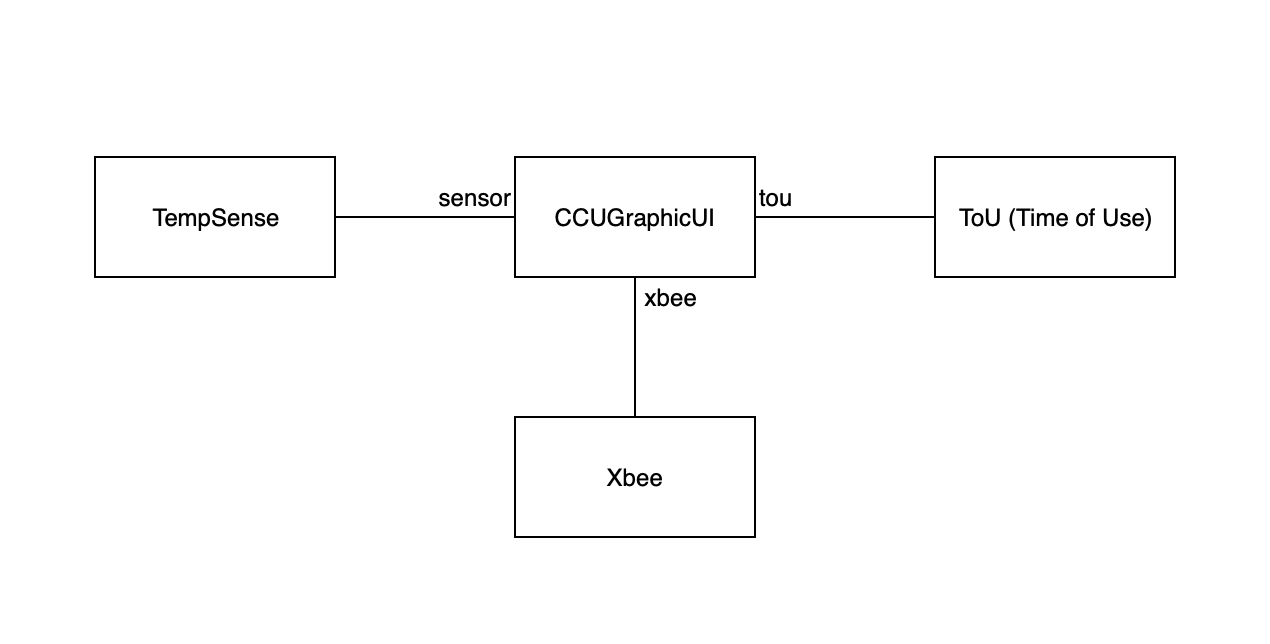
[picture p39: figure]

Figure 1: High level system overview

Wireless Communication:

Protocol: 802.15.4

Radio: Xbee s2c

Interface: USART

Baudrate: 9600 bps

Optimization Model:

Price: Π(t)

Charging Power: P(t)

Minimize Σ P(t)× Π(t)

Subject to: 0 ≤P(t)≤ Pmax

Σ P(t)=Required Energy

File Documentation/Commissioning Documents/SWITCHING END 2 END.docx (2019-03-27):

switching circuit

End to End Testing

University of Regina

ENEL 417

Purpose: Test the remote switching from Central Control Unit (CCU) to the Device Energy Manager (DEM)

Important Note: Please make sure the end to end Zigbee communication is tested before performing this test.

Procedure: In order to test this circuit, perform the following step:

1. Connect the Zigbee module to the power supply and the microcontroller board* as shown in figure 1.0 below:

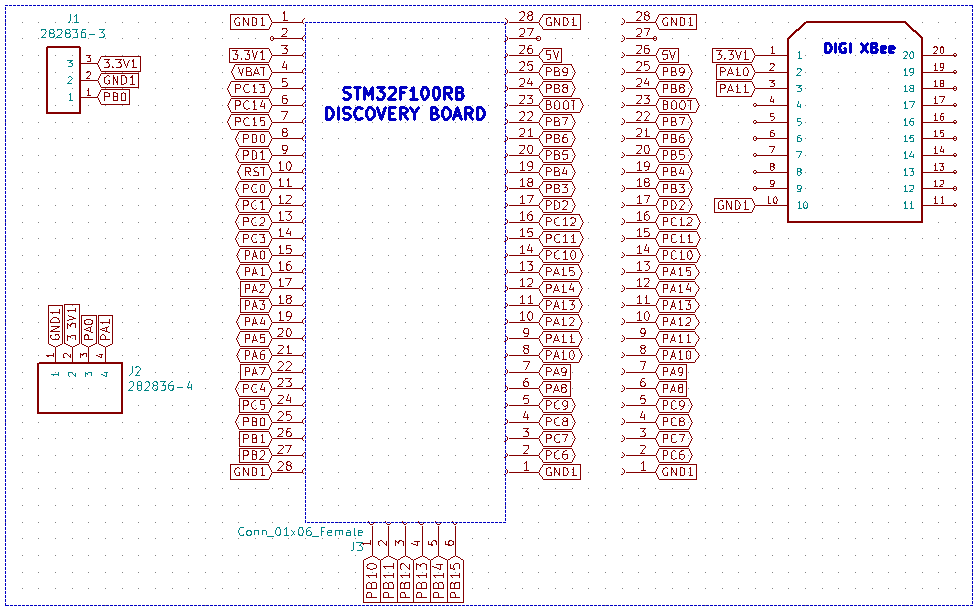
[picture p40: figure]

Figure 1.0: Microcontroller and XBEE Schematic

*- For this test, please connect the Zigbee data pins (2 (Rx),3 (Tx)) to PA3 and PA2 respectively. The above schematic is for the final design and uses USART2 instead of USART1

2. Connect the switching circuit as shown in figure 1.1 below:


Figure 1.1: Power Supply and Switching Circuit

3. Ask the team member responsible for programming the device to load the program into the STM32 discovery board.
4. Ask the team member responsible for CCU to run the app and send the switching command via XBEE
5. The Blue LED on the STM32 board will light up indicating that the switching command has reached and the microcontroller has sent the switching signal to the switching circuit
6. Additionally, the switching circuit is connected to PB0 pin on the microcontroller. A DMM can be used to check the status of this pin in order to confirm the switching signal. The DMM will read around 3V when the pin is ‘on’.
7. In the end, the PB0 pin can be connected to the control input of the circuit in figure 1.1.
8. The DC relay can be heard energizing which will close the contacts 3 and 5. This confirms that the end to end switching is working.
9. The AC relay is not used in this test but is tested in the switching circuit test.

Results:

Pass: (Y / N):

Date:

Signature Signature Signature Signature

(Supervisor) Team Member1 Team Member2 Team Member3

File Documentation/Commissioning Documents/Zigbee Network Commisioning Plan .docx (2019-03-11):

| ENEL 417 Capstone project Home Energy Management System (HEMS) Commisioning Plan ------------------------ SUB-SYSTEM LEVEL Zigbee network WRITTEN BY: Damilola Oludiran

WIRELESS COMMUNICATION INTERFACE SPECIFICATIONS:

1. 1. Range: at least 30m urban (non-line of sight).

(*typical distance between a house and a detached garage in Regina, Saskatchewan)


2. Minimum Throughput 2.5Kbps (Data) (assuming 144Hz sample rate for Current Data)

RANGE TESTING WITH XCTU:

DESCRIPTION:

Digi XCTU is a configuration and testing software that will be used to test the network performance under a variety of cases and scenarios.

TEST REQUIREMENTS:

- PC with Xbee X-CTU
- 2x Xbee RF Nodes
- 1x USB to Serial Adaptor

INSTALL DIGI XCTU:

Digi XCTU can be downloaded and installed from https://www.digi.com/products/iot-platform/xctu

TEST SETUP:


PROCEDURE:

- Set up the Remote node as shown in the figure above.
- Connect the other Xbee to a PC running XCTU with a serial to USB connector. Ensure all the pins are properly connected (TX->RX, 3.3V->Vcc, Gnd->Gnd)
- Launch Digi XCTU and click add radio, select the serial port and connect to the attached radio.
- Select Range Test from the Tools drop down menu


- Select the local node and the remote node


- Change the Range Test Type to Loopback and set the number of packets to 100 packets.

- Set the Rx and Tx timeouts to 1000ms as shown in the figure above.

- Move the remote node to the required test distance and click on start test.

- Record results in the table below:

TEST CASES:

Test Case 1:

Location: | University of Regina, Education Building, 4th Floor

Trial | Distance | Remote Power | Packets Sent | Packets Lost (Packet loss rate) | Tx Errors
1 | 22.86m (non-line of sight | -83dBm | 100 | 28 | 44
2 | 62m (line of sight) | -73dBm | 100 | 6 | 30
3 | - | - | - | - | -

Comments:

The remote node was powered using an STM32F100RB microcontroller connected to a laptop. The loopback connection was done in code on the STM board.

Test Case 2:

Location: | Residential, 2-bedroom basement apartment in Harbor Landing

Trial | Distance | Remote Power | Packets Sent | Packets Lost (Packet loss rate) | Tx Errors
1 | 12.50m | -74dBm | 100 | 0 | 2
2 | 12.50m | -82dBm | 100 | 0 | 2
3 | 20.21m | -86dBm | 100 | 0 | 1
4 | 20.21m | -84dBm | 113 | 6 | 6
5 | 33.50m | -76dBm | 122 | 5 | 34

Comments:

These tests were done with the central node in a basement apartment of the house, so the test node was always one floor above the main receiving node and non-line of sight in all scenarios. Distance measurements were estimated using Google Maps and are shown in the figures below.

Test Scenarios:


Trial 1 & 2 | Indoor Layout: Distance Estimation: 12.5m


Trial 3 & 4 | Distance Estimation:


Trial 5 | Distance Estimation: 33.50m

Result Summary:

No connection loss was observed in any of the test situation, although distances and environmental factors affected communications we can compensate for these effects in system operation.

**XCTU screen captures for these tests are included in Appendix A below.

Team member 1 Team member 2 Team member 3 Supervisor

DEM COMMUNICATION INTERFACE TESTING:

TEST REQUIREMENTS:

- PC running Digi XCTU and Keil uvision
- 1x TTYL serial to USB connector
- 2 Digi Xbee Radios
- STM32F100RB Microcontroller

PROCEDURE:

- Both Xbee Radios have been configured as required. Connect the Coordinator Xbee to the PC using the provided TTYL serial to USB connector.
- Launch Digi XCTU and click on the add radio icon
- Select the appropriate serial port for the radio
- Once the radio is connected, Switch to console working mode and open a serial connection with the radio
- Connect the end node radio to the STM microcontroller; Xbee RX to PA2, TX to PA3, Xbee Vcc to 3.3V and Ground to any ground pin on the microcontroller
- Launch the Xbee test keil uvision project and build
- Flash the program to the microcontroller and press the reset button on the microcontroller
- You should begin to register received packets on Digi XCTU


- Verify that the data received is the same as sent from the STM microcontroller. This is done by inspecting the received frame details on XCTU as shown below


- Record the received data, should be 0x4567 (Arbitrarily Chosen). You can modify the program to test with different 2-byte data.

Expected outcome: | Received Data = 0x4567
Result: | Received Data = 0x4567

- Uncomment the code segment for receiving data and comment on the sending code segment as shown below. This code segment toggles the LED on PC8 of the microcontroller if the received data is equal to 0x4567


- Run the program.
- On Digi XCTU, click on the plus (+) sign shown in the figure below to make a new frame.


- Select a frame name and click “Create frame using frame generator tool”
- Set the frame type to 0x01-Tx (Transmit) Request: 16-bit address
- Set the destination address 0x00DE (this is the address of the DEM Radio)
- Set the data to “45 67” Hex.


- Click OK and click add frame.
- Click Start sequence to start transmitting the frame. Check that the blue LED on the microcontroller toggles.

Expected outcome: | Blue LED on the STM microcontroller toggles
Result: | Test passed. Blue LED toggles.

Team member 1 Team member 2 Team member 3 Supervisor

END-TO-END TESTING:

TEST REQUIREMENTS:

- PC running keil uvision.
- 1x ttyl serial to usb connector
- 2x Digi Xbee Radios
- 1x Raspberry Pi
- 1x STM32F100RB

PROCEDURE:

- Both Xbee Radios have been configured as required. Connect the Coordinator Xbee to the raspberry pi as shown in the figure below.


- Connect the end node xbee radio to the STM32F100RB microcontroller; Xbee RX to PA2, TX to PA3, Xbee Vcc to 3.3V and Ground to any ground pin on the microcontroller
- Open the DEM comms folder and launch the project on keil uvision.
- Run the program and flash the target. The program toggles the blue LED on the STM microcontroller if the received data is equal to 0x5890 (Arbitrarily chosen).
- Press the reset button on the STM microcontroller.
- Turn the raspberry pi. And open a terminal window.
- Navigate to the xbeetest directory using cd Desktop/xbeetest command.
- Run main.py using typing python main.py

Expected outcome: | Blue LED on the STM microcontroller toggles
Result: | Test passed. Blue LED toggles.

Team member 1 Team member 2 Team member 3 Supervisor

INTEGRATION TESTING:

DESCRIPTION:

The aim of this test is to test the remote appliance switching and reading of current sensor simultaneously. A test program will run on the DEM and continuously send current readings to the CCU and also listen for switching commands. Another program will run on the CCU and will be responsible for displaying the received current readings and periodically send switching signals to the DEM. Both systems will have counters for indicating the number of transmitted and received packets to determine the throughput of the communications network in a variety of situations and a range of distances. For accuracy, the data received can be compared to measurements from an ammeter.

TEST REQUIREMENTS:

Hardware:

- CCU
- DEM prototype with subsystems (CT and switching Circuit)

Software:

- Commstest.py
- Commstestnode.c

TEST SETUP:


Team member 1 Team member 2 Team member 3 Supervisor

APPENDIX A

Range Testing Data: (University of Regina Education building 4th floor)

1. 22.86m (non-line of sight:


2. 62m (line of sight):


Residential, 2-bedroom basement apartment in Harbor Landing:

1. 12.50m:


2. 12.50m


3. 20.21m:


4. 20.21m


5. 33.50m:


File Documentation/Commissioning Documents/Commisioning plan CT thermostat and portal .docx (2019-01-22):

| ENEL 417 Capstone project Home Energy Management System (HEMS) Commisioning Plan ------------------------ Insert main system name (CCU, DEM, Utility portal etc.) WRITTEN BY: Amandeep Joshi

Project specification: Utility Portal:

1. Time of use form field has different data types associated with different fields as below:

Effective date field data type: date

Time associated with time of use period: Time

Time of use period: It is drop down menu to select ON-Peak, off peak, and mid peak (data type varchar)

Time of user Price (TOU price): It accept number values only.

2. Entered data in from will be saved on web server in associated data format for each field.

Testing Plan for Utility Portal:
1. Data entered via utility portal operated will be tested relative to the field format via checking the file saved on the portal back end via accessing portal backend server side.

2. Python Script is responsible for fetching data from utility. Fetched data correctness will be verified via comparing it with files saved on portal server.

Thermostat model: Block diagram

Battery 9V

Pull up Resistor

GPIO PIN

5V

Switching Circuit

Air-conditioner

Temperature

Sensor

Raspberry pie

Controller 3B

GPIO PIN

Heater

Switching Circuit

Battery 9V

Figure 1.0

Thermostat model specifications:

1. Accuracy of sensing unit is +/- 0.5 ֯ C from -10 ֯ C to 85 ֯ C. Sensor’s actual temperature measurement range lies between -55 ֯ C to 125 ֯ C. Operating voltage range for sensing unit is 3.0 volt to 5.5 volt.

2. One wire protocol (proprietary serial communication) for communication with Microcontroller.

3. Software development for reading temperature with different resolution of 9 bit to 12 bit can be configured.

4. Set point is set to lower than current indoor temperature: Turn the Air-conditioner ON.

5. Set point is Set Higher than current indoor temperature: Turn the Heater ON.

6. Although, scheduler is responsible for switching thermostat loads. But user can override the scheduler setting via manually setting set points.

Testing plan for Thermostat model:

S/N | Tasks to Accomplish | Task results meet the specifications (Y/N)
1. | Temperature sensing unit accuracy verification. Steps are as follows to verify the accuracy of measured temperature. 1. In order to verify the temperature measuring accuracy of temperature sensing unit, another temperature measuring tool is required as reference. It can be another reference thermometer.
2. | Correctness Software development for sensor reading will be tested as follows: 1. Vary the temperature around temperature sensor using via placing hand on sensor or placing sealed ice pack safely. Then print the sensor reading on LCD to verify sensor readings. 2. Sensor temperature measurement range and resolution similarly verified via displaying sensor reading on control.
3. | Load switching such as AC and heater 1. Set the set point below the room temperature and check if heater turns on or not. Similarly turns on set point higher than room temperature, if AC turns ON that verifies the accuracy of load switching and software development of it.

Interfacing of Current transformer with Microcontroller to monitor power usage: Block diagram

Figure 1.2

Specifications:

1. Current transformer must have 120 VAC as in input and maximum it can handle is 34 A when both primary windings are connected in parallel. Turn ratio of selected transformer is 200:1:1.

Accuracy of measurement with Ammeter clamp is 2.0 % ±5 digits (45 – 65 Hz)

2. In order to interface current transformer with microcontroller ADC for monitoring purpose, voltage range should be 0 to 3.3 V AC.

3. Burden resistor selection at the secondary of CT must be anticipated according to maximum current drawn in the circuit and must fulfills the requirement of required voltage that can be fed to Op-Amp and signal conditioning circuit.

4. Output of Signal conditioning circuit must be 0 to 3.3V.

Risk Assessment and mitigation strategy (RAMS):

S/N | Potential Hazardous dealing with 120 AC Testing Environment : Power Lab | Mitigation Strategy
1. | Trip and Fall Hazard | Clear the trip hazard from the way.
2. | Electric Shock Hazard | Be mindful of shock and make connections very carefully. Try to use one hand while making connections.
3. | Fire Hazard (If more current passed than rated values of component and devices. | Be mindful will connecting current rating loads. Verify connections and load ratings with Supervisor before turning ON anything.
4. | Exposed electrical wiring | Proper inspection of wiring before powering ON Something. If there is exposed wiring, replace it with correct wire in good condition.

Testing Plan for CT and controller interfacing circuit:

Figure 1.3

S/N | Testing of Monitoring unit Input voltage for monitoring unit is 120 V and Output Voltage must be 3.3 V. Current on the secondary of step down transformer must be 34 A. Steps are given below to test the monitoring circuit. | Task results meet the specifications (Y/N)
1. | To safely perform testing of monitoring circuit which deals with high voltages and current rating .So, Isolation transformer must be connected between variable transformer and 120 V input supply
2. | Then connect the step down transformer after variable transformer. Step down from 120 V AC to 10 V. Use Demonstration transform available in power lab as step down.
3. | Connect Ammeter Clamp on the secondary of Step-down transformer to verify current on the primary of CT. If Ammeter reads 34 Amp which corresponds to 3.3 Volt on the output side of Monitoring Circuit

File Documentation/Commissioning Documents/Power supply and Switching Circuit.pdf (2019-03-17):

# ENEL 417


# CAPSTONE PROJECT

Home Energy Management System (HEMS)

## COMMISIONING PLAN

## DEVICE ENERGY MONITOR

## POWER SUPPLY AND SWITCHING UNIT

### WRITTEN BY:

### Bikramjit Singh Saini


Objective: Commissioning of the Power Supply, Optocoupler Triac and Relay Circuit.

Specifications: Below are the specifications of the system under test

### 1. Operating Voltage: 120 VAC

2. Power Supply must supply 3.3 VDC (+/- 120 mV) and 600 mA (+/- 100 mA) of current at the output*

### 3. The DC Relay have a coil voltage of 3.3 VDC (~ 50mA)

4. The contact of the DC relay must be rated at 120 VAC and 40 mA current in order to operate the AC relay with coil voltage120 VAC (4VA: 33.33 mA)

### 5. Load Switching capability: Typical 25 A. Maximum 30 A. (at 120 VAC)

Figure 1.0: Device Energy Manager (Power Supply and Optocoupler Triac: System Under Test)

Figure 1.1: Power Supply and Switching Circuit Schematic

Safety Checklist: This checklist must be completed and checked by your supervisor before starting the commissioning process described below as the circuit involves working with 120 VAC:

Safety Checklist for Testing Circuits Involving 120 VAC Date: yyyy/mm/dd
S. No | Task | Completed (Y/N)
1 Use the isolation transformer and variac for testing circuit as | shown in figure 1.3 below | Y
2 Use the 120 VAC supply from the same circuit (figure 1.3) to | power the AC switching circuit | Y
3 Do not connect AC power/load to the load contacts of the | relay | Y
4 Supervisor: The procedure mentioned in step 1 and 2 is | followed | Name: Doug Wagner Signature:
5 Supervisor: The wiring is verified and the circuit is ready to | be energized and tested | Name: Doug Wagner Signature:


Figure 1.2: 120 VAC Safety Circuit Block Diagram

Note: - See figure 1.1 for power supply circuit schematic

Commissioning Plan: The commissioning is accomplished by testing each of the above-mentioned specifications.

Note: Make sure the safety checklist for testing circuits involving 120 VAC is completed before doing the following testing
S. No | TESTING STEP | Pass (Y/N)
1 | Input Supply: Input supply is 120 VAC. | Y
2 Power Supply Circuit: Apply power to the circuit constructed during the safety | checklist review. Slowly increase the voltage of the variac to 120 VAC (Make sure to monitor the voltage on the wattmeter). Check the output of the Power Supply Module using a DMM in DC Volts mode: ~3.3V – Pass < or > 3.3V – Fail Results: The output was analyzed using the oscilloscope. The voltage was found to be 3.3V with +/- 30 mVP-P ripple. A 220 nF capacitor was added on the output which reduced the ripple voltage to +/- 15 mVP-P | Y

### 3 Switching Circuit: In order to test the switching circuit, Connect the 120 VAC

supply to the AC Relay Coil circuit as shown below:


Apply 3.3V from the DC power supply to the control input of J02 connector (Pin 3).

The AC contact will close and a click can be heard which means the test is passed

Results: As soon as 3.3V was applied to the base of the BJT transistor, the AC Relay was heard energizing confirming the working of the circuit.

Y

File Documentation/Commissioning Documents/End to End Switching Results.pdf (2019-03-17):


Scanned by CamScanner


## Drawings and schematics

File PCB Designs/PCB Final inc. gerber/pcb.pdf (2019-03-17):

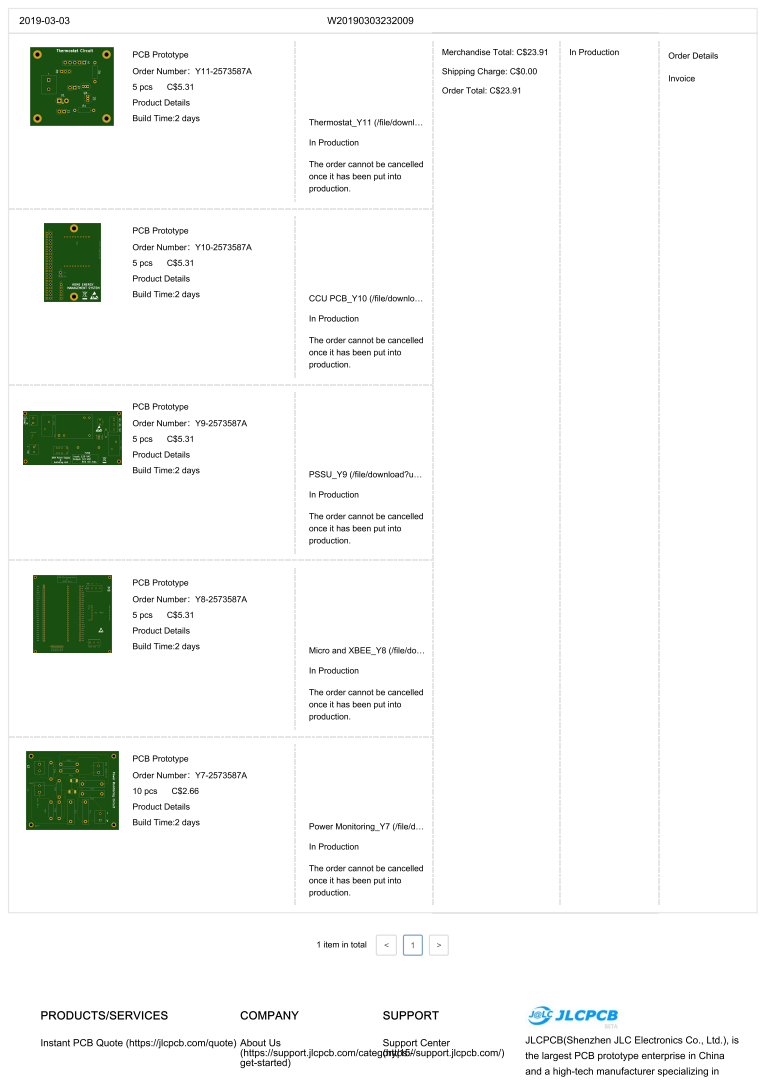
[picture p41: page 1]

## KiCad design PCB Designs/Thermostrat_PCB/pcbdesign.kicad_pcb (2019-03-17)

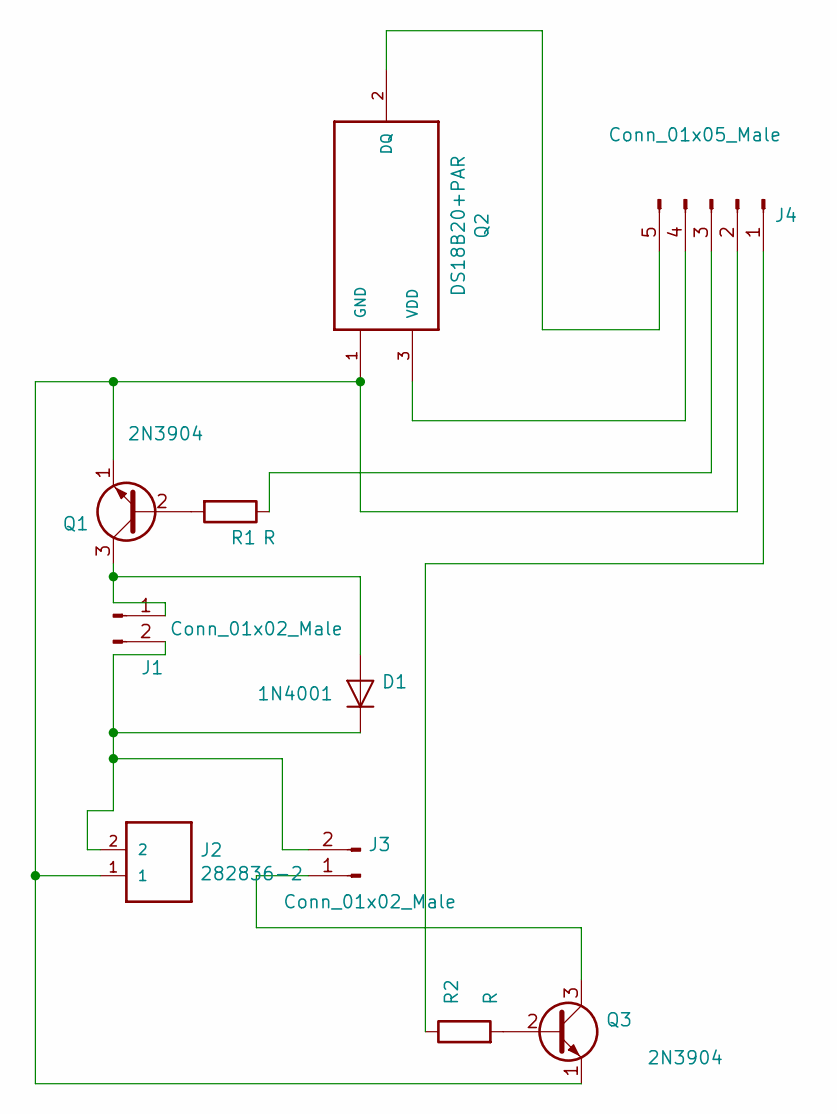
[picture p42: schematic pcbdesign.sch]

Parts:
D1: 1N4001; D_DO-15_P3.81mm_Vertical_AnodeUp
J1, J3: Conn_01x02_Male; PinHeader_1x02_P2.54mm_Vertical
J2: 282836-2; CONN_282836-2
J4: Conn_01x05_Male; PinHeader_1x05_P2.54mm_Vertical
Q1, Q3: 2N3904; TO-92_Inline
Q2: DS18B20+PAR; TO-92
R1, R2: R; R_Axial_DIN0207_L6.3mm_D2.5mm_P10.16mm_Horizontal

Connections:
unnamed: D1.1 (K), J1.2, J2.2, J3.2
unnamed: D1.2 (A), J1.1, Q1.3 (C)
unnamed: J2.1, J4.2, Q1.1 (E), Q2.1 (GND), Q3.1 (E)
unnamed: J3.1, Q3.3 (C)
unnamed: J4.1, R2.1
unnamed: J4.3, R1.1
unnamed: J4.4, Q2.3 (VDD)
unnamed: J4.5, Q2.2 (DQ)
unnamed: Q1.2 (B), R1.2
unnamed: Q3.2 (B), R2.2

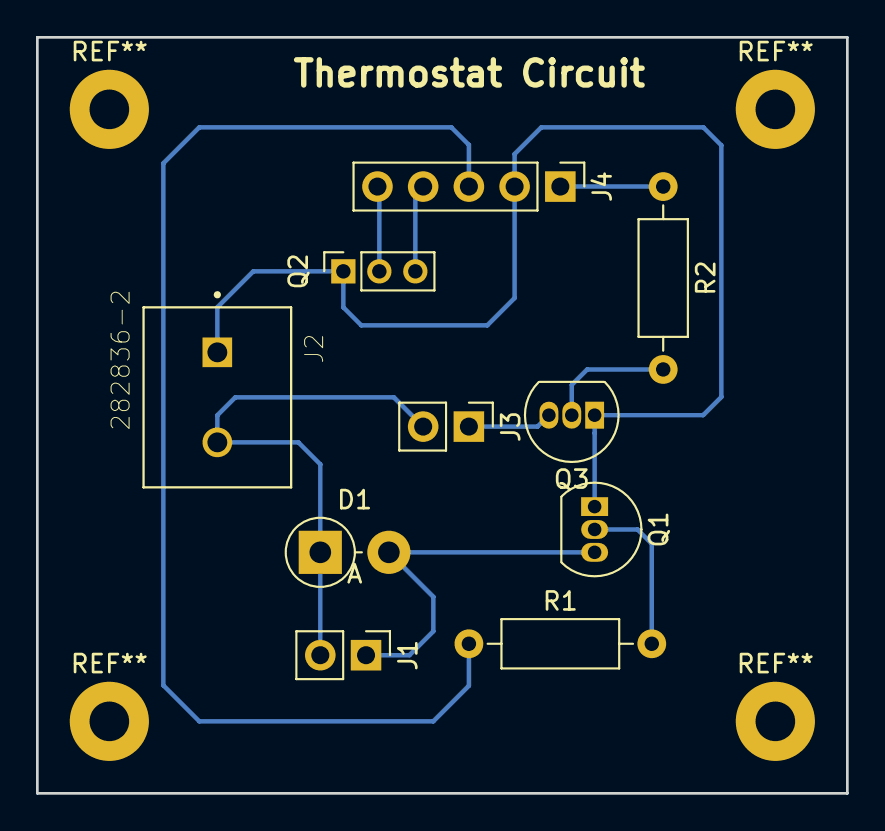
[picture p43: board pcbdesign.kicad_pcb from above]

Board: 2 copper layers, 45.0 x 42.0 mm, 10 parts (0 on the bottom side), 10 nets.

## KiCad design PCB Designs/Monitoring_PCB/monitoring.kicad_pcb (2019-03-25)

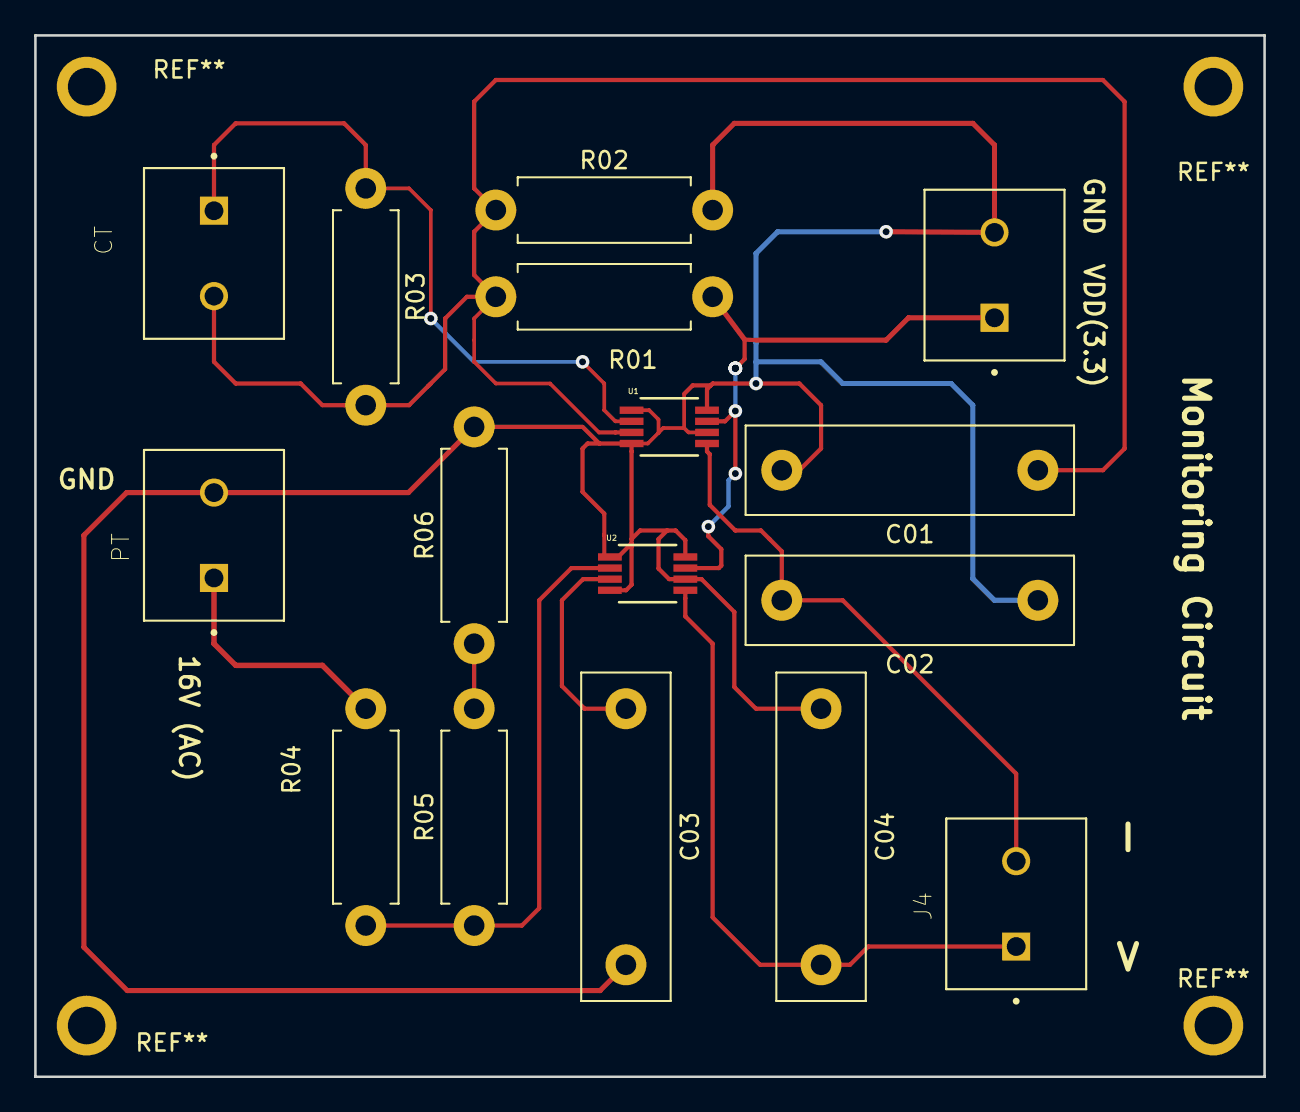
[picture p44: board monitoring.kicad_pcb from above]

Board: 2 copper layers, 72.0 x 61.0 mm, 16 parts (0 on the bottom side), 10 nets.

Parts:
C01, C03: 0.1uF; C_Rect_L19.0mm_W5.0mm_P15.00mm_MKS4
C02, C04: 1uF; C_Rect_L19.0mm_W5.0mm_P15.00mm_MKS4
CT: 282836-2; CONN_282836-2
J3, J4: 282836-2; CONN_282836-2
PT: 282836-2; CONN_282836-2
R01, R02: 100k; R_Axial_DIN0411_L9.9mm_D3.6mm_P12.70mm_Horizontal
R03: 4; R_Axial_DIN0411_L9.9mm_D3.6mm_P12.70mm_Horizontal
R04: 10k; R_Axial_DIN0411_L9.9mm_D3.6mm_P12.70mm_Horizontal
R05: 215k; R_Axial_DIN0411_L9.9mm_D3.6mm_P12.70mm_Horizontal
R06: 1k; R_Axial_DIN0411_L9.9mm_D3.6mm_P12.70mm_Horizontal
U1, U2: LTC1966CMS8PBF; MSOP-8_MS

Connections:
unnamed: C01.1, CT.2, R01.2, R02.1, R03.2, U1.3
unnamed: C01.2, C02.1, C03.2, C04.1, J3.2, PT.2, R02.2, R06.2, U1.1, U1.4, U1.6, U1.8, U2.1, U2.4, U2.6, U2.8
unnamed: C02.2, J4.2, U1.5
unnamed: C03.1, U2.3
unnamed: C04.2, J4.1, U2.5
unnamed: CT.1, R03.1, U1.2
unnamed: PT.1, R04.1
unnamed: J3.1, R01.1, U1.7, U2.7
unnamed: R04.2, R05.1, U2.2
unnamed: R05.2, R06.1

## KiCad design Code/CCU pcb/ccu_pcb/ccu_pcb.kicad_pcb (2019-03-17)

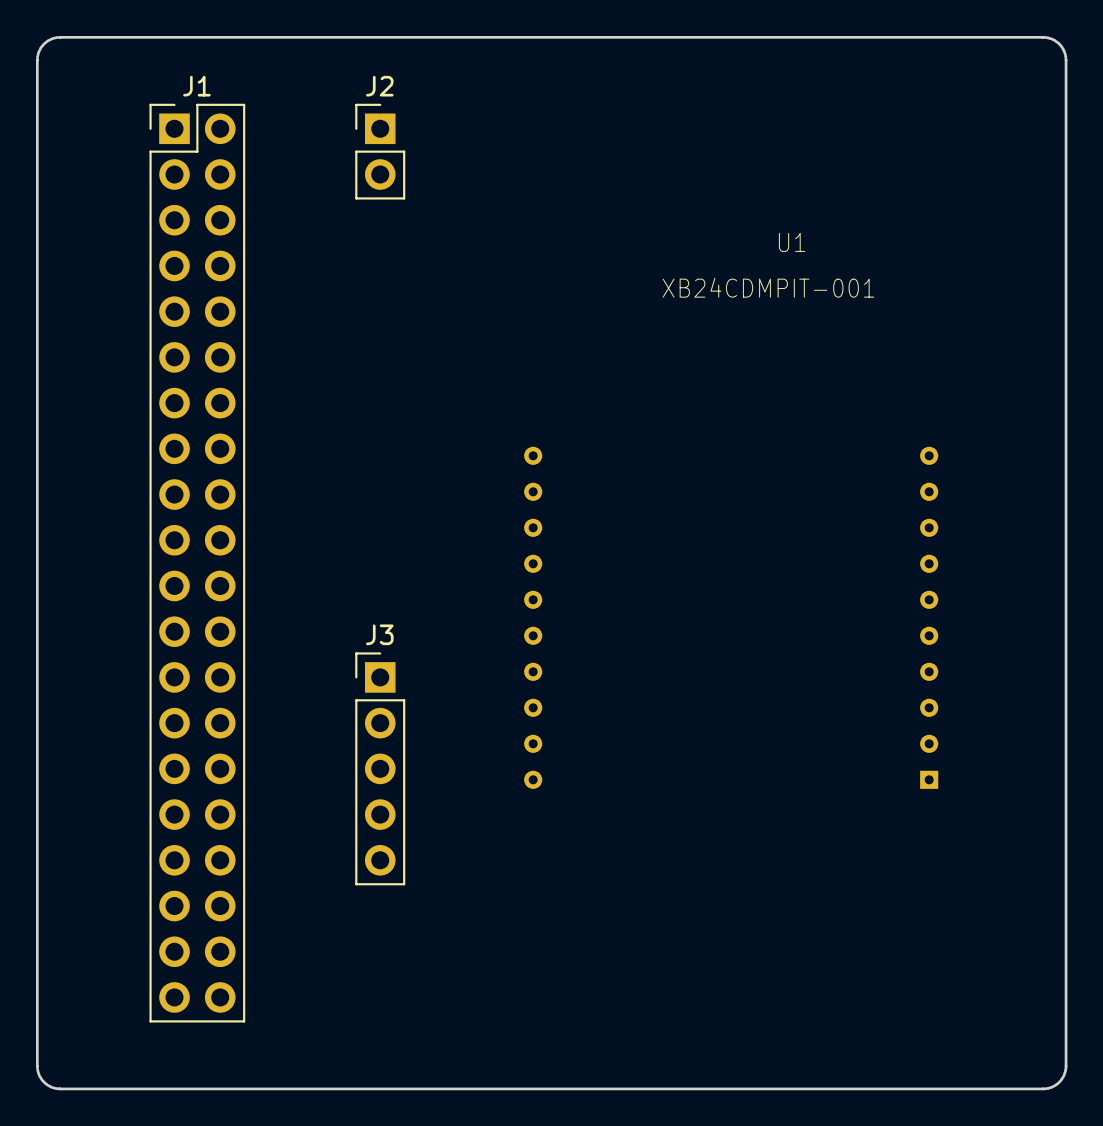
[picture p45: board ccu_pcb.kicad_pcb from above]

Board: 2 copper layers, 57.2 x 58.4 mm, 4 parts (0 on the bottom side), 8 nets, no tracks yet.

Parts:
J1: Conn_02x20_Odd_Even; PinHeader_2x20_P2.54mm_Vertical
J2: Conn_01x02_Male; PinHeader_1x02_P2.54mm_Vertical
J3: Conn_01x05_Male; PinHeader_1x05_P2.54mm_Vertical
U1: XB24CDMPIT-001; DIP-20

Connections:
5Vsupply: J1.2, J2.1, J3.1
GND: J1.40, J2.2, J3.5, U1.10
Therm_in_c: J1.18, J3.4
Therm_in_h: J1.16, J3.3
Therm_out: J1.12, J3.2
VCC: J1.1, U1.1
X_DIN: J1.8, U1.3
X_DOUT: J1.10, U1.2

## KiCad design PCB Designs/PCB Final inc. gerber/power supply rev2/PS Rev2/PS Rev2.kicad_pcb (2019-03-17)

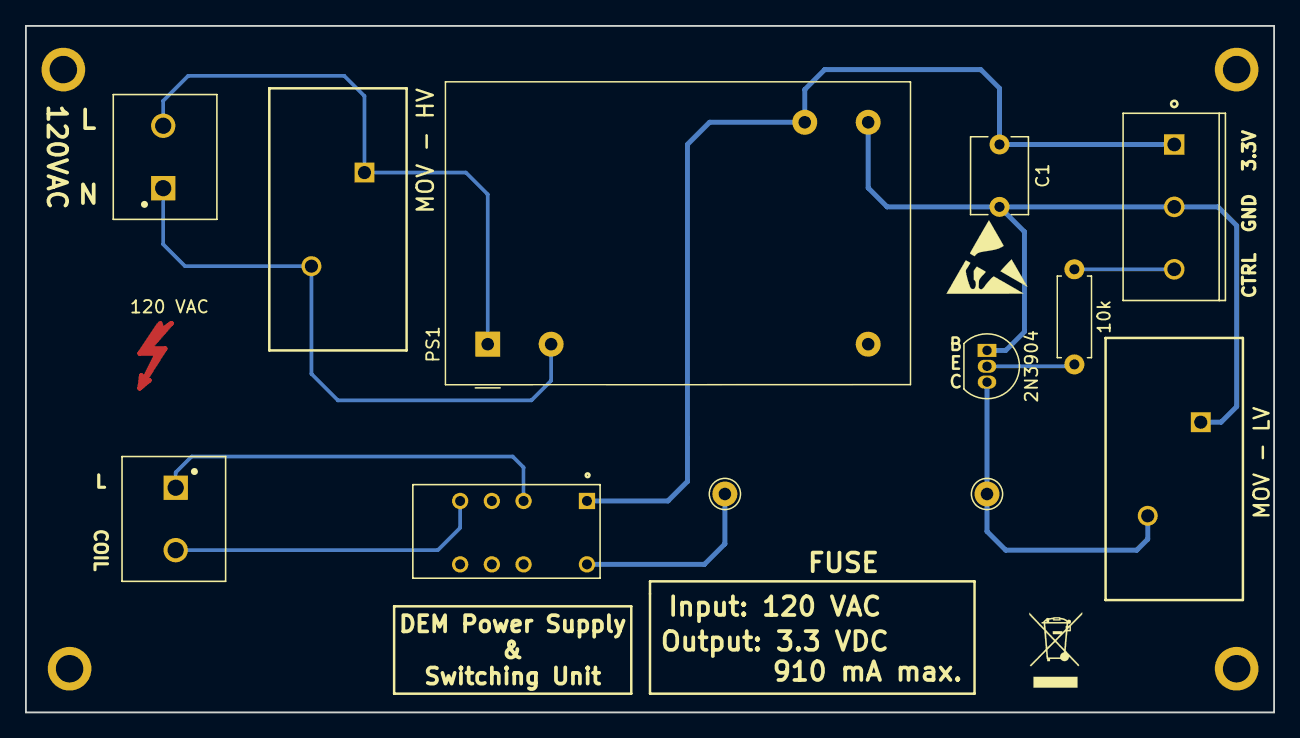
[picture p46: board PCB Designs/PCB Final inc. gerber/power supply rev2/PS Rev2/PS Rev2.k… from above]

Board: 2 copper layers, 100.0 x 55.0 mm, 13 parts (0 on the bottom side), 10 nets.

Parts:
2N3904: 2N3904; TO-92_Inline
10k: 10k; R_Axial_DIN0207_L6.3mm_D2.5mm_P7.62mm_Horizontal
120 VAC : Symbol_Highvoltage_Type1_CopperTop_Small
C1: 400 nF; C_Disc_D6.0mm_W4.4mm_P5.00mm
J1, J3: 1935161; PHOENIX_1935161
J2: 282836-3; TE_282836-3
J4, J5: Conn_01x01_Female; Pin_D1.0mm_L10.0mm
K1: EC2-3NU; KEMET_EC2-3NU
MOV - HV: TMOV20RP300E; CAPRR750W81L2100T1100H2300P
MOV - LV: TMOV20RP300E; CAPRR750W81L2100T1100H2300P
PS1: RAC03-3.3SGA; Converter_ACDC_RECOM_RAC04-xxSGx_THT

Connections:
unnamed: C1.1, J2.1, K1.1, PS1.5
unnamed: 2N3904.1, C1.2, J2.2, MOV - LV.1, PS1.4
unnamed: J1.1, MOV - HV.2, PS1.2
unnamed: J1.2, MOV - HV.1, PS1.1
unnamed: 10k.1, J2.3
unnamed: J3.1, K1.3
unnamed: J3.2, K1.5
unnamed: 2N3904.3, J4.1, MOV - LV.2
unnamed: J5.1, K1.12
unnamed: 2N3904.2, 10k.2

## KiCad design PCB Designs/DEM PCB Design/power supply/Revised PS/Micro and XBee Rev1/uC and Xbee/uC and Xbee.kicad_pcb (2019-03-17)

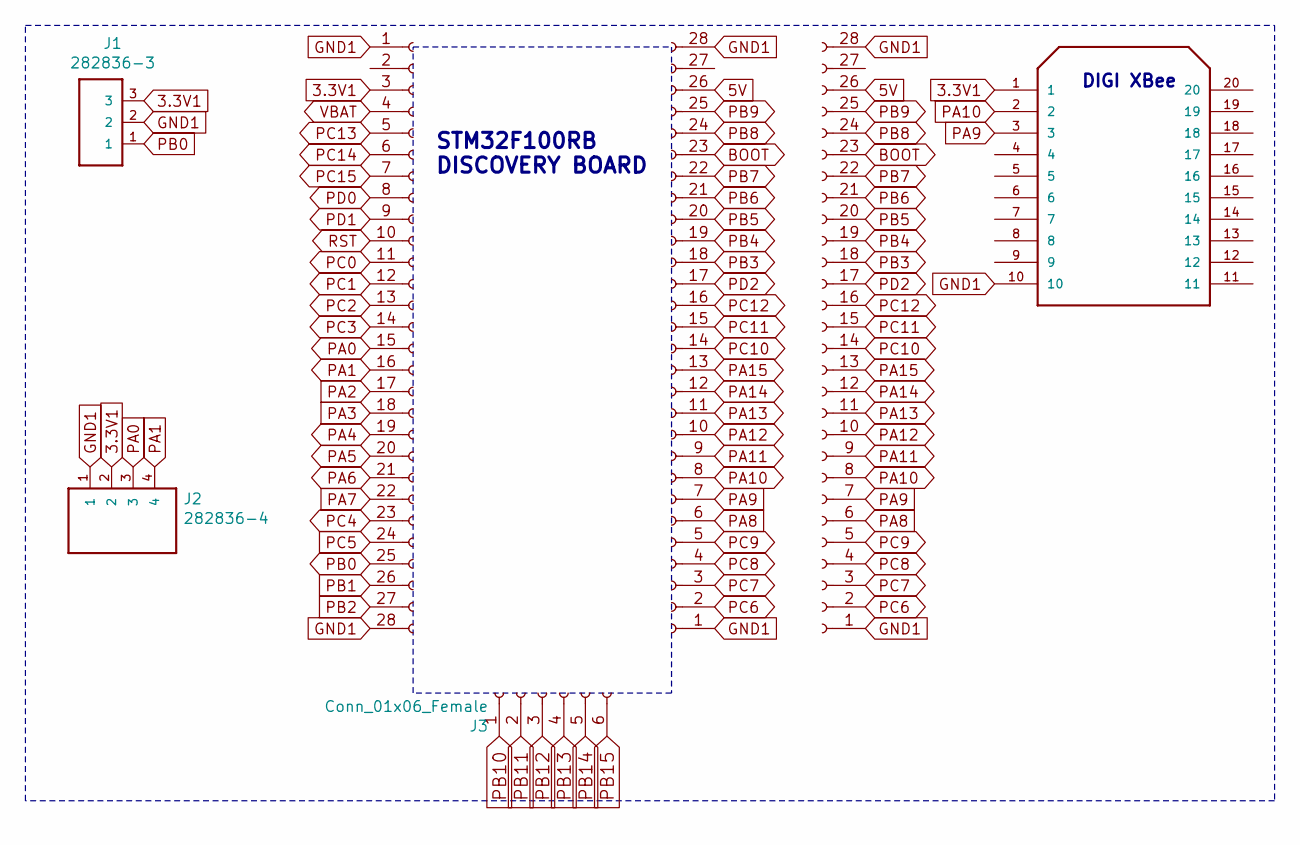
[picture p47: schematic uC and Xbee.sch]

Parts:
J1: 282836-3; TE_282836-3
J2: 282836-4; TE_282836-4
J3: Conn_01x06_Female; PinSocket_1x06_P2.54mm_Vertical
J4, J5, J6: Conn_01x28_Female; PinHeader_1x28_P2.54mm_Vertical
U1: XB24CDMSIT-001; DIP-20

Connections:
3.3V1: J1.3, J2.2, J4.3, U1.1
5V: J5.26, J6.26
BOOT: J5.23, J6.23
GND1: J1.2, J2.1, J4.1, J4.28, J5.1, J5.28, J6.1, J6.28, U1.10
PA0: J2.3, J4.15
PA1: J2.4, J4.16
PA2: J4.17
PA3: J4.18
PA4: J4.19
PA5: J4.20
PA6: J4.21
PA7: J4.22
PA8: J5.6, J6.6
PA9: J5.7, J6.7, U1.3
PA10: J5.8, J6.8, U1.2
PA11: J5.9, J6.9
PA12: J5.10, J6.10
PA13: J5.11, J6.11
PA14: J5.12, J6.12
PA15: J5.13, J6.13
PB0: J1.1, J4.25
PB1: J4.26
PB2: J4.27
PB3: J5.18, J6.18
PB4: J5.19, J6.19
PB5: J5.20, J6.20
PB6: J5.21, J6.21
PB7: J5.22, J6.22
PB8: J5.24, J6.24
PB9: J5.25, J6.25
PB10: J3.1
PB11: J3.2
PB12: J3.3
PB13: J3.4
PB14: J3.5
PB15: J3.6
PC0: J4.11
PC1: J4.12
PC2: J4.13
PC3: J4.14
PC4: J4.23
PC5: J4.24
PC6: J5.2, J6.2
PC7: J5.3, J6.3
PC8: J5.4, J6.4
PC9: J5.5, J6.5
PC10: J5.14, J6.14
PC11: J5.15, J6.15
PC12: J5.16, J6.16
PC13: J4.5
PC14: J4.6
PC15: J4.7
PD0: J4.8
PD1: J4.9
PD2: J5.17, J6.17
RST: J4.10
VBAT: J4.4

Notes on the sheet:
STM32F100RB DISCOVERY BOARD
DIGI XBee

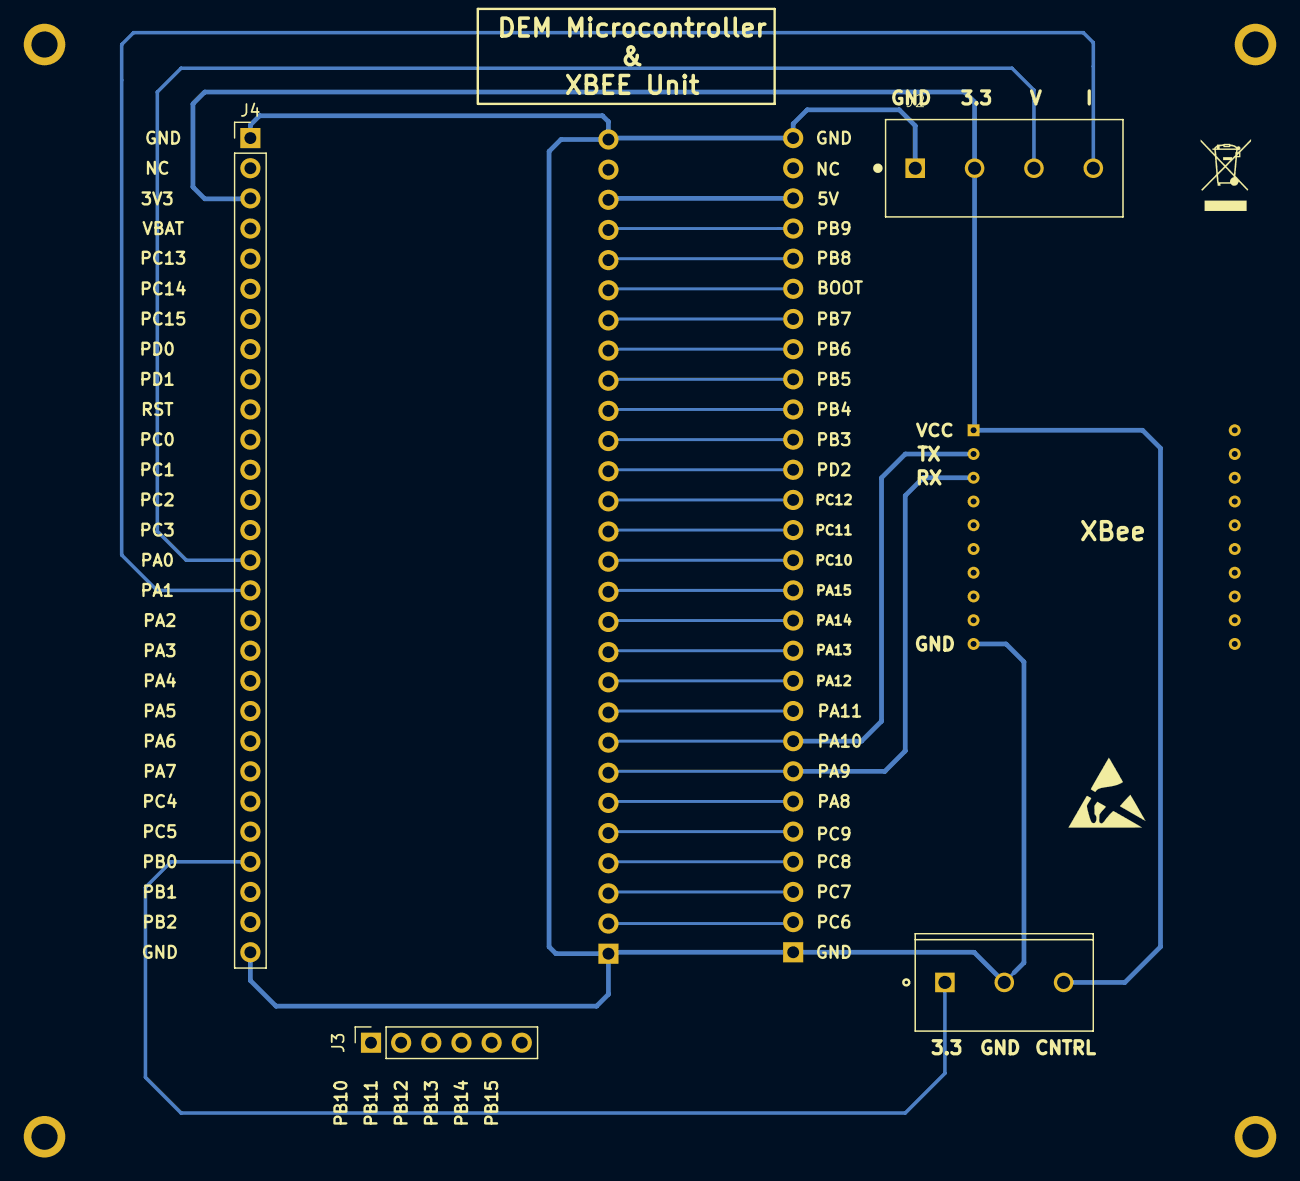
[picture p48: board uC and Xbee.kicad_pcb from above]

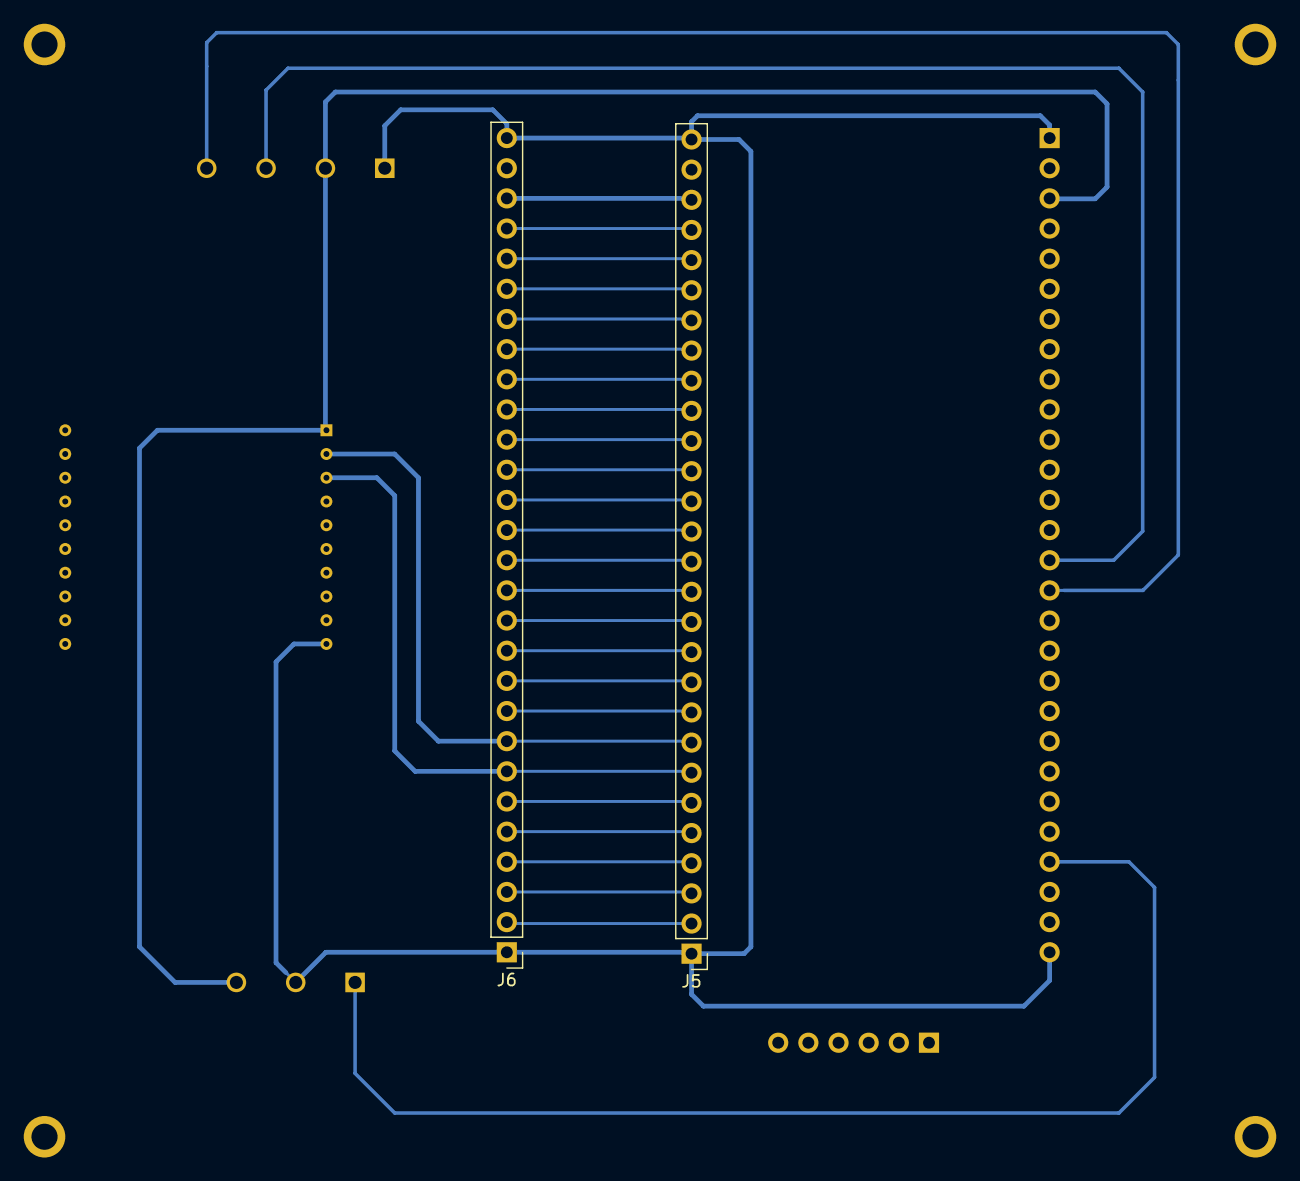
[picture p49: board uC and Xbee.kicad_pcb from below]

Board: 2 copper layers, 7 parts (2 on the bottom side), 30 nets.

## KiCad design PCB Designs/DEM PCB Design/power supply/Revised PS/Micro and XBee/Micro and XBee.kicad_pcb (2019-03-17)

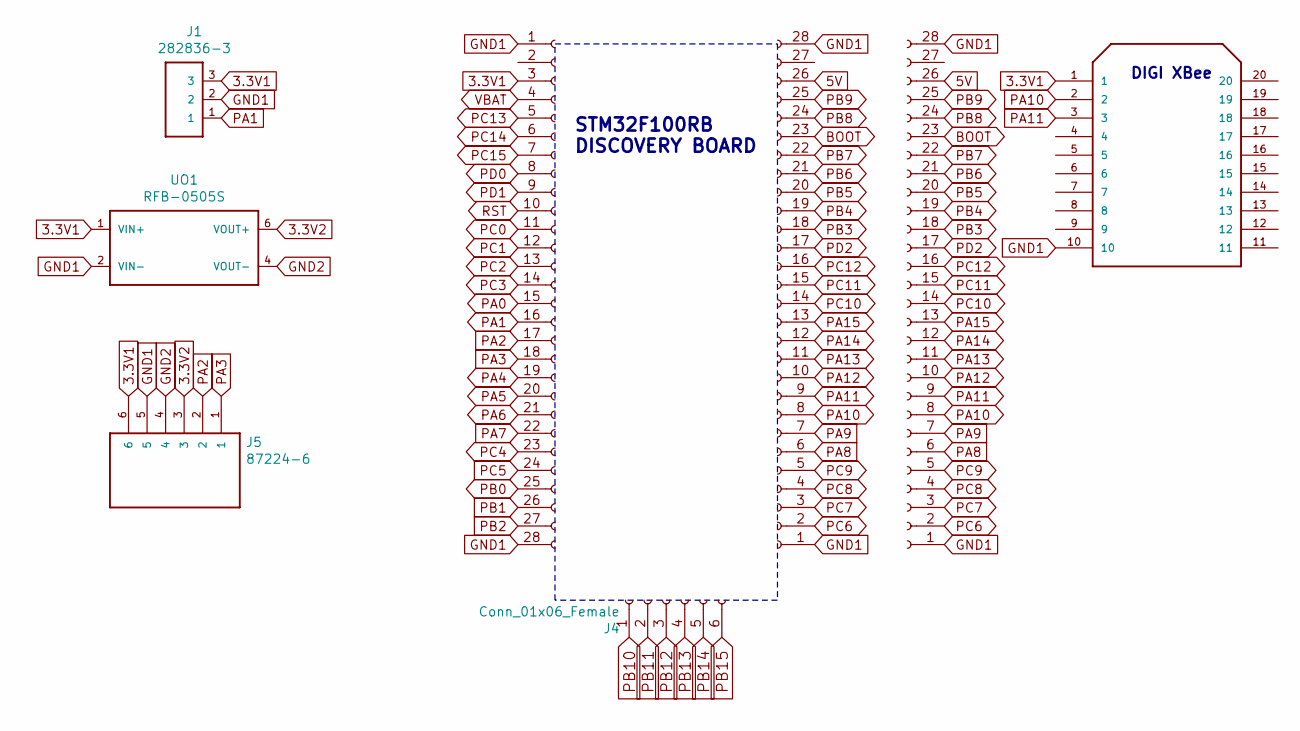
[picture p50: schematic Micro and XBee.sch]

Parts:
J1: 282836-3; TE_282836-3
J2, J3, J6: Conn_01x28_Female; PinHeader_1x28_P2.54mm_Vertical
J4: Conn_01x06_Female; PinSocket_1x06_P2.54mm_Vertical
J5: 87224-6; TE_87224-6
U2: XB24CDMSIT-001; DIP-20
UO1: RFB-0505S

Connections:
3.3V1: J1.3, J2.3, J5.6, U2.1, UO1.1 (VIN+)
3.3V2: J5.3, UO1.6 (VOUT+)
5V: J3.26, J6.26
BOOT: J3.23, J6.23
GND1: J1.2, J2.1, J2.28, J3.1, J3.28, J5.5, J6.1, J6.28, U2.10, UO1.2 (VIN-)
GND2: J5.4, UO1.4 (VOUT-)
PA0: J2.15
PA1: J1.1, J2.16
PA2: J2.17, J5.2
PA3: J2.18, J5.1
PA4: J2.19
PA5: J2.20
PA6: J2.21
PA7: J2.22
PA8: J3.6, J6.6
PA9: J3.7, J6.7
PA10: J3.8, J6.8, U2.2
PA11: J3.9, J6.9, U2.3
PA12: J3.10, J6.10
PA13: J3.11, J6.11
PA14: J3.12, J6.12
PA15: J3.13, J6.13
PB0: J2.25
PB1: J2.26
PB2: J2.27
PB3: J3.18, J6.18
PB4: J3.19, J6.19
PB5: J3.20, J6.20
PB6: J3.21, J6.21
PB7: J3.22, J6.22
PB8: J3.24, J6.24
PB9: J3.25, J6.25
PB10: J4.1
PB11: J4.2
PB12: J4.3
PB13: J4.4
PB14: J4.5
PB15: J4.6
PC0: J2.11
PC1: J2.12
PC2: J2.13
PC3: J2.14
PC4: J2.23
PC5: J2.24
PC6: J3.2, J6.2
PC7: J3.3, J6.3
PC8: J3.4, J6.4
PC9: J3.5, J6.5
PC10: J3.14, J6.14
PC11: J3.15, J6.15
PC12: J3.16, J6.16
PC13: J2.5
PC14: J2.6
PC15: J2.7
PD0: J2.8
PD1: J2.9
PD2: J3.17, J6.17
RST: J2.10
VBAT: J2.4

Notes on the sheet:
STM32F100RB DISCOVERY BOARD
DIGI XBee

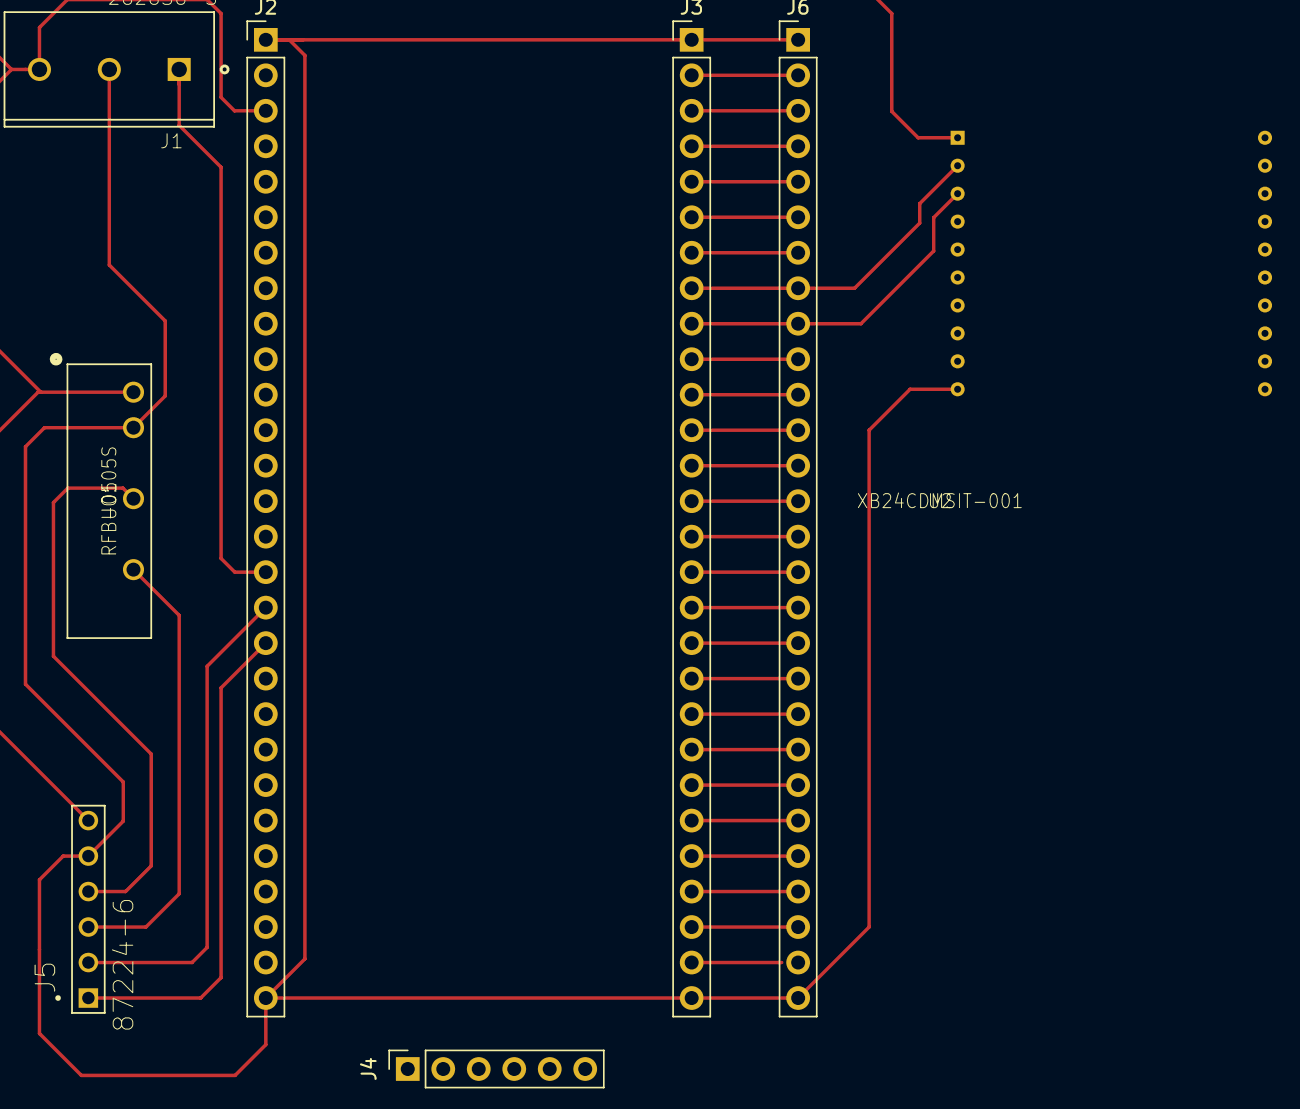
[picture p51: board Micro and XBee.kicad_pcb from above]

Board: 2 copper layers, 8 parts (0 on the bottom side), 32 nets.

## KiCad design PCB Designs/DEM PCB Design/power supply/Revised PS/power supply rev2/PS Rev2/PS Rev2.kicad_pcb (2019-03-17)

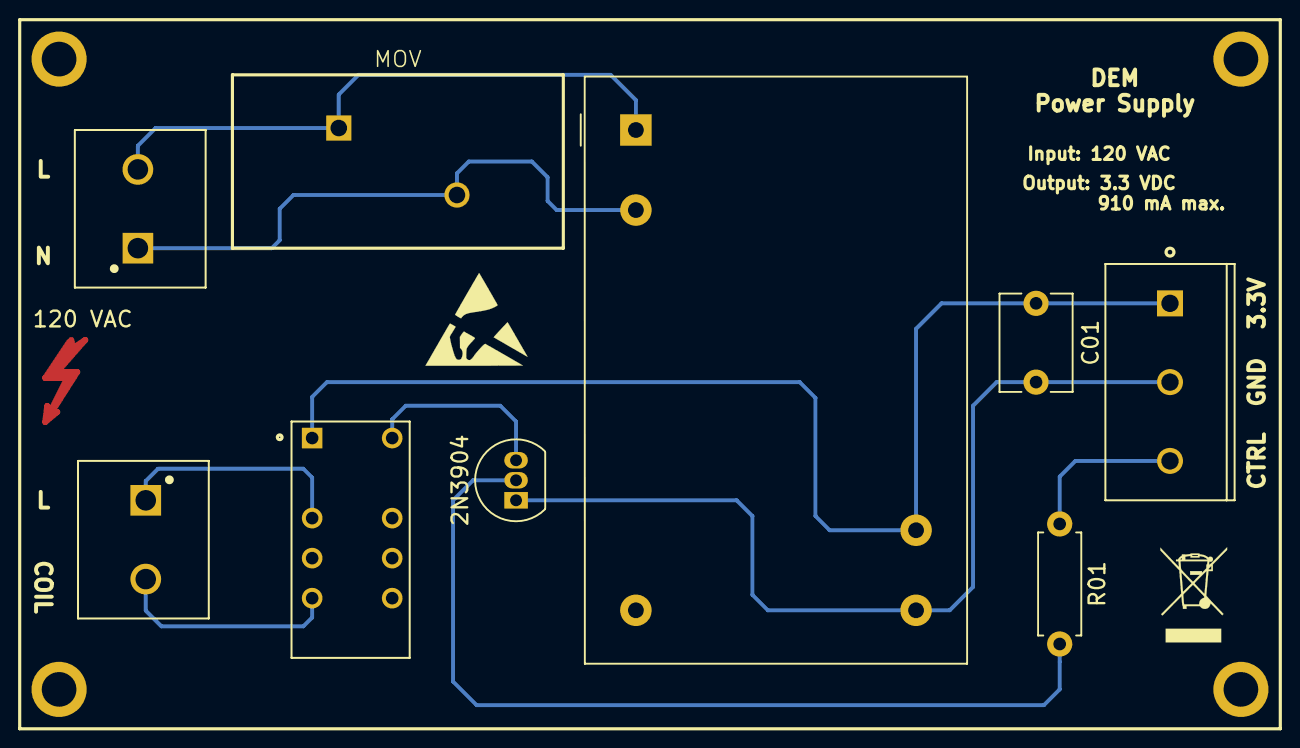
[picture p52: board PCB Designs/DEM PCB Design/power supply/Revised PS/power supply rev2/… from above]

Board: 2 copper layers, 10 parts (0 on the bottom side), 9 nets.

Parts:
2N3904: 2N3904; TO-92_Inline
120 VAC : Symbol_Highvoltage_Type1_CopperTop_Small
C01: 400 nF; C_Disc_D6.0mm_W4.4mm_P5.00mm
J01, J03: 1935161; PHOENIX_1935161
J02: 282836-3; TE_282836-3
K01: EC2-3NU; KEMET_EC2-3NU
MOV: TMOV20RP300E; CAPRR750W81L2100T1100H2300P
PS01: RAC03-3.3SGA; Converter_ACDC_RECOM_RAC04-xxSGx_THT
R01: 10k; R_Axial_DIN0207_L6.3mm_D2.5mm_P7.62mm_Horizontal

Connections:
unnamed: C01.1, J02.1, K01.1, PS01.5
unnamed: 2N3904.1, C01.2, J02.2, PS01.4
unnamed: J01.1, MOV.2, PS01.2
unnamed: J01.2, MOV.1, PS01.1
unnamed: J02.3, R01.1
unnamed: J03.1, K01.3
unnamed: J03.2, K01.5
unnamed: 2N3904.3, K01.12
unnamed: 2N3904.2, R01.2

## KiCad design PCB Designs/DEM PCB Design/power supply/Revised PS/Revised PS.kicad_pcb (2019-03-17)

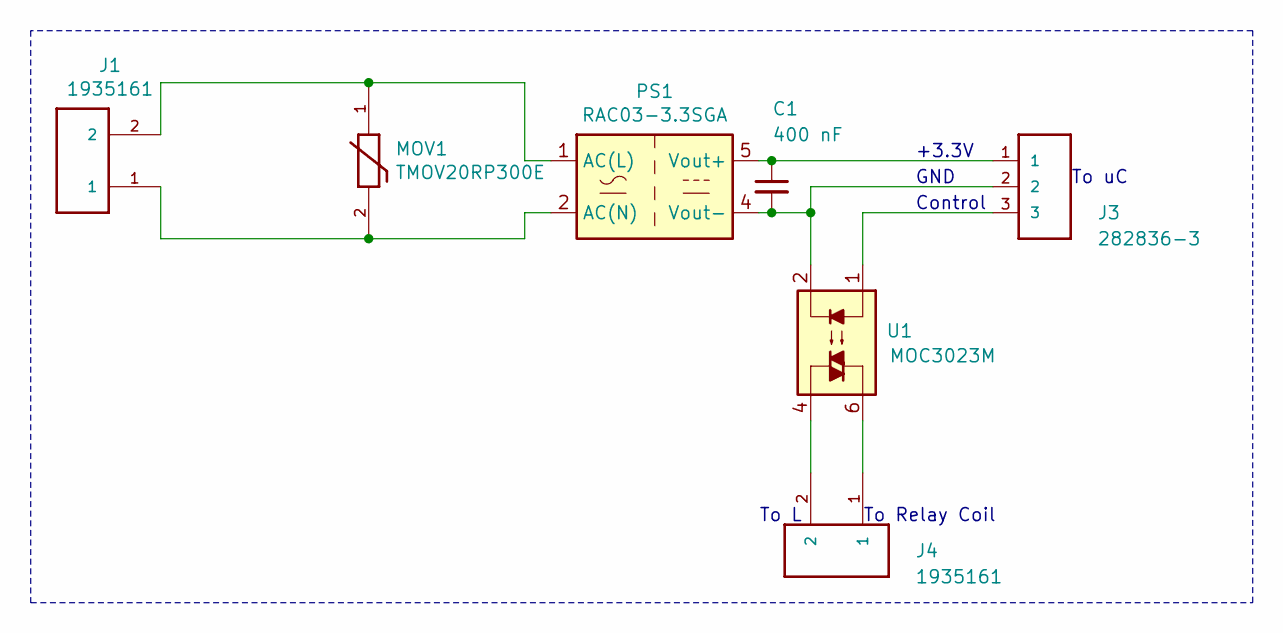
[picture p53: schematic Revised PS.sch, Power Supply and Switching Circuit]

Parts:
C1: 400 nF; C_Disc_D6.0mm_W4.4mm_P5.00mm
J1, J4: 1935161; PHOENIX_1935161
J3: 282836-3; TE_282836-3
MOV1: TMOV20RP300E; CAPRR750W81L2100T1100H2300P
PS1: RAC03-3.3SGA; Converter_ACDC_RECOM_RAC04-xxSGx_THT
U1: MOC3023M; DIP762W48P254L889H508Q6

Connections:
unnamed: C1.1, J3.1, PS1.5 (Vout+)
unnamed: C1.2, J3.2, PS1.4 (Vout-), U1.2
unnamed: J1.1, MOV1.2, PS1.2 (AC(N))
unnamed: J1.2, MOV1.1, PS1.1 (AC(L))
unnamed: J3.3, U1.1
unnamed: J4.1, U1.6
unnamed: J4.2, U1.4

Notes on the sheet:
To Relay Coil
To L
+3.3V
GND
Control
To uC


Board: 2 copper layers, 100.0 x 50.0 mm, 7 parts (0 on the bottom side), 7 nets.

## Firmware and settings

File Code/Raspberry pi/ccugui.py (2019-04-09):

#################################################################################
# Name: ccugui.py                                                               #
# Description: Main system control and user interface                           #
# Version: V3.1                                                                 #
# Author: Damilola Oludiran                                                     #
#                                                                               #
#                                                                               #
# This software is supplied "AS IS" without warranties of any kind.             #
#                                                                               #
#----------------------------------------------------------------------------   #
# History:                                                                      #
#     V1.0 Initial Version by Damilola Oludiran                                 #
#     V1.1 Moved Kivy Layout String to ccugui.kv by Damilola Oludiran           #
#     V1.2 Added Home Screen class by Damilola Oludiran                         #
#     V1.3 Designed ToU presentation widget by Damilola Oludiran                #
#     V1.4 Added Main menu, EV and Thermostat screen classes                    #
#          by Damilola Oludiran                                                 #
#     V1.5 Added temperature control widgets and buttons to thermostat screen   #
#          by Damilola Oludiran                                                 #
#     V1.6 Thermostat Button Functions by Damilola Oludiran                     #
#     V1.7 Intergrated Temperature sensor to system by Damilola Oludiran        #
#     V1.8 Added Demand response function to Thermostat by Damilola Oludiran    #
#     V1.9 Added Widgets to EV screen by Damilola Oludiran                      #
#     V2.0 Integrated the xbee module into application by Damilola Oludiran     #
#     V2.1 Revised xbee module integration by Damilola Oludiran                 #
#     V2.2 Changed Implementation to threaded class by Damilola Oludiran        #
#     V2.3 Revised Ev screen to include a plot for consumption trendline        #
#     V2.4 Implemented functionality to send switching signal                   #
#     V2.5 Implemented functionality to recieve and present power consumption   #
#          data                                                                 #
#     V2.6 Added Sheduling screen and methods by Damilola Oludiran              #
#     V2.7 Integrated Optimization function and methods by Damilola Oludiran    #
#     V2.8 Revised Optimization methods by Damilola Oludiran                    #
#     V2.9 revised xbee interfacing to synchronize with DEM by Damilola         #
#     V3.0 Revised Thermostat method to implement DR by Damilola                #
#     V3.1 Final Version by Damilola Oludiran                                   #
#################################################################################
################################################################################

#################################################################################
# Imports                                                                       #
#################################################################################
from kivy.lang import Builder
Builder.load_file("ccugui.kv")
from kivy.config import Config
Config.set('graphics', 'fullscreen', '0')

import os
os.environ['KIVY_GL_BACKEND'] = 'gl'
from kivy.app import App
from kivy.garden.matplotlib.backend_kivyagg import FigureCanvasKivyAgg
from kivy.uix.tabbedpanel import TabbedPanel
from kivy.uix.screenmanager import ScreenManager, Screen
from kivy.graphics import Color, Rectangle
from kivy.uix.behaviors import ButtonBehavior
from kivy.uix.image import Image
from kivy.uix.label import Label
from kivy.uix.boxlayout import BoxLayout
from kivy.uix.anchorlayout import AnchorLayout
from kivy.uix.gridlayout import GridLayout
from kivy.uix.button import Button
import matplotlib.pyplot as plt
import numpy as np
from kivy.properties import StringProperty
from kivy.clock import Clock
import datetime
import time
from dropt import dropt
import pandas as pd
import threading
import tou
import xbee
import tempsense
import RPi.GPIO as GPIO

#################################################################################
# GPIO Set Up                                                                   #
#################################################################################
heater = 12 
ac = 16


GPIO.setmode(GPIO.BCM)
GPIO.setup(heater, GPIO.OUT)
GPIO.setup(ac, GPIO.OUT)

GPIO.output(heater, GPIO.LOW)
GPIO.output(ac, GPIO.LOW)
################################################################################

class CCUGUI(ScreenManager):
    pass

################################################################################

#################################################################################
# Home Screen Class                                                             #
#################################################################################
class HomeScreen(Screen):
    minutes = 0
    date = StringProperty(str(datetime.date.today().strftime("%d %B, %Y")))
    time = StringProperty(str(time.strftime('%H:%M', time.gmtime(minutes*60))))
    timeofusedata=[]
    
    #################################################################################
    # Name: __init__                                                                #
    # Parameters: self                                                              #
    # Description: This method Initializes the Home Screen                          #
    #                                                                               #
    #                                                                               #
    # Preconditions: n/a                                                            #
    # Postconditions: n/a                                                           #
    #################################################################################
    def __init__(self, **kwargs):
        Screen.__init__(self, **kwargs)
        self.tou_data = tou.ToU()
        self.fig, self.ax = plt.subplots()
        self.fig_canvas = FigureCanvasKivyAgg(figure=self.fig)
        self.get_tou(1)
        self.data_graphs()
        self.ids.touplot.add_widget(self.fig_canvas)
        Clock.schedule_interval(self.clock, 1)
        Clock.schedule_interval(self.get_tou, 5)
        Clock.schedule_interval(self.data_graphs, 60)
    
    #################################################################################
    # Name: clock                                                                   #
    # Parameters: self                                                              #
    # Description: Simulates 24 hour in 24 minutes for demo purposes                #
    #                                                                               #
    # Preconditions: n/a                                                            #
    # Postconditions: n/a                                                           #
    #################################################################################
    def clock(self, *args):
        if (self.minutes == 1440):
            self.minutes = 0
        self.minutes += 1
        self.time = str(time.strftime('%H:%M', time.gmtime(self.minutes*60)))
    
    def get_date(self, dt):
        self.date = str(datetime.date.today().strftime("%d %B, %Y"))
        self.time = str(datetime.datetime.now().strftime("%I:%M:%S %p"))
    
    def get_tou(self, dt):
        self.timeofusedata = self.tou_data.recieveTOU()
    
    #################################################################################
    # Name: datagraphs                                                              #
    # Parameters: self                                                              #
    # Description: This method returns the tou clock widget                         #
    #                                                                               #
    # Preconditions: tou data is retrieved                                          #
    # Postconditions: n/a                                                           #
    #################################################################################
    def data_graphs(self, *args):
        
        size = 0.3
        out_size = 0.02
        angle = 15
        hours = 24
        hour_vals = [angle]*hours
        hour_labels = ['Midnight',1,2,3,4,5,6,7,8,9,10,11,'Noon',1,2,3,4,5,6,7,8,9,10,11]
        timeofday = [1, 1]
        timeofdaylabel= ['PM','AM']
        if (self.timeofusedata != 0):
            val = self.timeofusedata[0]
            inner_colors = self.timeofusedata[1]
            self.ids.onpeak.text = '[b]ON-PEAK : ' + self.timeofusedata[4] + '$/kWh[/b]'
            self.ids.offpeak.text ='[b]OFF-PEAK : ' + self.timeofusedata[5] + '$/kWh[/b]'
            self.ids.midpeak.text ='[b]MID-PEAK : '+ self.timeofusedata[6] + '$/kWh[/b]'
            
        else:
            val = [0,0,0,0]
            inner_colors = ['#f5f6fa']
        outer_colors = ['#f5f6fa']
        
        
        wedges, labels = self.ax.pie(hour_vals, radius=1, colors=outer_colors, labels=hour_labels,
                                startangle=97.5, counterclock=False,labeldistance =1.05,
                                wedgeprops=dict(width=out_size, edgecolor='w'))
        for label in labels:
            label.set_horizontalalignment('center')
            label.set_size('smaller')
    
        self.ax.pie(val, radius=1-out_size-0.01, colors=inner_colors, startangle=90,
                                       counterclock=False, wedgeprops=dict(width=size, edgecolor='w'))
                                    
        wedge_s,label_s =  self.ax.pie(timeofday, radius=1-out_size-size-0.025, labels = timeofdaylabel, colors=['#353b48', '#dcdde1'], startangle=90,
                                                              textprops = ({'weight': 'bold'}),labeldistance =0.4, wedgeprops=dict(width=0.1, edgecolor='w'))
        for label in label_s:
            label.set_size('large')
                                                                      
            self.ax.set(aspect="equal")
            self.fig.canvas.draw_idle()
        
        
        
################################################################################
#################################################################################
# MenuScreen Class                                                              #
#################################################################################
class MenuScreen(Screen):
    pass

################################################################################

#################################################################################
# EVScreen Class                                                                #
#################################################################################
class EVScreen(Screen):
    charging = False
    isCharging = False
    turn_on = [0x58,0x90]
    turn_off = [0x58,0x99]
    recieve = [0x58,0x00]
    dr_override = False
    isoverride = False
    price =[0]
    currvolt=[0,0]
    power = 0
    dailyusage = []
    powerconsumption = np.zeros(1440)
    totalCost =0
    totalEnergy = 0
    priceperMin = np.zeros(1440)
    
    #################################################################################
    # Name: __init__                                                                #
    # Parameters: self                                                              #
    # Description: This method initialises EV Screen Class                          #
    #                                                                               #
    # Preconditions: n/a                                                            #
    # Postconditions: n/a                                                           #
    #################################################################################
    def __init__(self, **kwargs):
        Screen.__init__(self, **kwargs)
        self.price_power_fig, self.price_plot = plt.subplots()
        self.consumption_plot = self.price_power_fig.add_subplot(111, sharex=self.price_plot, frameon=False)
        self.price_power_canvas = FigureCanvasKivyAgg(figure=self.price_power_fig)
        self.pricepwrPlot()
        self.xbee = xbee.Xbee("/dev/ttyS0")
        self.ids.consdata.add_widget(self.price_power_canvas)
        self.totalMonthconsumptionPlot()
        self.ids.monthly.add_widget(FigureCanvasKivyAgg(plt.gcf()))
        Clock.schedule_interval(self.evCharging, 0.5)
        Clock.schedule_interval(self.get_power, 0.7)
        Clock.schedule_interval(self.calCost, 1)
        Clock.schedule_interval(self.pricepwrPlot, 15)
    
    #################################################################################
    # Name: evcharging                                                              #
    # Parameters: self                                                              #
    # Description: This method implements the EV charging control                   #
    #                                                                               #
    # Preconditions: n/a                                                            #
    # Postconditions: n/a                                                           #
    #################################################################################
    def evCharging(self, *args):
        minutes = self.manager.get_screen("Home").minutes
        is_scheduled = self.manager.get_screen("sched").is_scheduled
        load_profile = self.manager.get_screen("sched").load_profile
        p_rated = self.manager.get_screen("sched").p_rated
        tou = self.manager.get_screen("Home").timeofusedata
        if(tou != 0):
            self.price = tou[2]
            self.priceperMin = tou[3]
        
        
        if (self.dr_override == True) and (self.charging == False):
            self.dr_override = False
            self.xbee.send(data=self.turn_on)
            self.charging = True
            self.ids.charge.text = 'Charging'
            self.ids.overide.text = 'Turn Off'
            if(is_scheduled == True):
                self.isoverride = True
            
        
        if (self.dr_override == True) and (self.charging == True):
            self.dr_override = False
            self.xbee.send(data=self.turn_off)
            self.charging = False
            self.ids.charge.text = 'Not Charging'
            self.ids.overide.text = 'Turn On'
            if(is_scheduled == True):
                self.isoverride = True
          
        
        if ((is_scheduled == True) and (self.isoverride == False)):
            if (minutes%15 == 0):
                i = int(minutes/15)
                print(minutes)
                print(i)
                if (i != 96): 
                    if ((load_profile[i] > 5) and (self.charging == False)):
                        print(int(load_profile[i]))
                        self.xbee.send(self.turn_on)
                        self.charging = True
                        self.ids.charge.text = 'Charging'
                        self.ids.overide.text = 'Turn Off'
                    
                    elif ((load_profile[i] < 5) and (self.charging == True)):
                        print(int(load_profile[i]))
                        self.xbee.send(self.turn_off)
                        self.charging = False
                        self.ids.charge.text = 'Not Charging'
                        self.ids.overide.text = 'Turn On'
                

                    
    
    #################################################################################
    # Name: pricepwrplot                                                            #
    # Parameters: self                                                              #
    # Description: This method plot price and power consumption data                #
    #                                                                               #
    # Preconditions: n/a                                                            #
    # Postconditions: n/a                                                           #
    # Reference for customizing plot:                                               #
    # https://stackoverflow.com/questions/14908576                                  #
    # /how-to-remove-frame-from-matplotlib-pyplot-figure-vs-matplotlib-figure-frame #
    #################################################################################
    def pricepwrPlot(self, *args):
        if (len(self.dailyusage) == 96):
            self.dailyusage = []

            self.consumption_plot.remove()
            self.consumption_plot = self.price_power_fig.add_subplot(111, sharex=self.price_plot, frameon=False)
            self.totalCost = 0
            self.totalEnergy = 0
            
            
        self.dailyusage.append(self.power)
        self.price_plot.plot(self.price, color='orange', linewidth=2, label= 'Price')
        x_skip = 4;
        n = 96
        min_per_k = 1440/n
        plt.xticks(np.arange(0, n+1, step=x_skip*(60/min_per_k)), np.arange(0, 25, step=x_skip))
        self.consumption_plot.plot(self.dailyusage, color = '#4c8a4c', linewidth=2, label='Power Consumption')
        self.consumption_plot.yaxis.tick_right()

        
        self.price_plot.spines['top'].set_visible(False)
        self.price_plot.spines['right'].set_visible(False)
        self.price_plot.spines['bottom'].set_visible(False)
        self.price_plot.spines['left'].set_visible(False)
        self.price_plot.yaxis.grid(True)
        self.price_plot.tick_params(top='off', bottom='off', left='off', right='off', labelleft='on', labelbottom='on')
        self.consumption_plot.tick_params(top='off', bottom='off', left='off', right='off', labelleft='off', labelbottom='on')
        self.consumption_plot.set_ylim(ymin=0, ymax= 2.5)
        self.price_power_canvas.draw_idle()
        
        
    #################################################################################
    # Name: totalMonthconsumptionPlot                                               #
    # Parameters: self                                                              #
    # Description: This method plots mothly power consumption data                  #
    #                                                                               #
    # Preconditions: n/a                                                            #
    # Postconditions: n/a                                                           #
    #################################################################################
    def totalMonthconsumptionPlot(self, *args):
        plt.figure()
        
        Month = [1,2,3,4,5,6,7,8,9,10,11,12,13,14,15,16,17,18,19,20,21,22,23,24,25,26,27,28,29,30,31]
        Energy = [50,30,40,45,50,65,60,43,23,40,11,
                  50,13,0,0,0,0,0,0,0,0,0,0,0,0,0,0,0,0,0,0]
        
        position = np.arange(len(Month))
        
        mybars = plt.bar(position, Energy, align ='center', linewidth =0)
        plt.xticks(position, Month)
        
        plt.title('Monthly')
        
        for spine in plt.gca().spines.values():
            spine.set_visible(False)
            
        plt.tick_params(top='off', bottom='off', left='off', right='off', labelleft='off', labelbottom='on')
        
        for bari in mybars:
            height = bari.get_height()
            plt.gca().text(bari.get_x() + bari.get_width()/2, bari.get_height()- 0.2, str(int(height)),
                           ha='center', color='white', fontsize=5)

    #################################################################################
    # Name: get_power                                                               #
    # Parameters: self                                                              #
    # Description: This method retrieve xbee queue data                             #
    #                                                                               #
    # Preconditions: n/a                                                            #
    # Postconditions: n/a                                                           #
    #################################################################################
    def get_power(self, dt=1):
        self.currvolt = self.xbee.recieve()
           
        if (self.currvolt != 0):
            print(self.currvolt)
            currtemp = self.currvolt[0]/1000
            volttemp = self.currvolt[1]/1000
        
            current = 28.123*(currtemp) + 0.0517
            voltage = 177.13*(volttemp**3) -  138.54*(volttemp**2) + 118.35*(volttemp) + 0.0193
            self.power = (current*voltage)/1000
            self.power = round(self.power, 2)
            print(self.power)
            self.ids.powerdis.text = '\r\r\r Live Usage: \n' + '      ' + str(self.power) + 'kW'
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

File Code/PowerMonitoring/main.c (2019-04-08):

/**
// Header format used with permission from Damilola Oludiran
 ******************************************************************************
 * Name: ADC_INIT.c
 * Description: Data from CCU is recieved and appropriate functions are called 
                according to that data
 * Version: V1.0
 * Author: Bikramjit Saini & Damilola Oludiran (Integration Code) 
  
 *
 * This software is supplied "AS IS" without warranties of any kind.
 *
 *
 *----------------------------------------------------------------------------
 * History:
 *          V1.0 Initial Version by Bikramjit Saini & Damilola Oludiran (Integration Code) 
 *            
 *         
 *****************************************************************************
 */
 
#include "clocks.h"
#include "stm32f10x.h"
#include "ADC_INIT.h"
#include "Power_monitoring.h"
#include "stdio.h"
#include "xbee.h"
#include"systick.h"

int GLOBAL_BUFF_SIZE = 11;
bool GLOBAL_DATA_RECEIVED =false;
bool GLOBAL_PWR_SEND;
uint16_t GLOBAL_USART_Received_Data[30];
int GLOBAL_CHAR_COUNTER = 0;
int i = 0;


int main(void)
{
	int i = 0;
	uint16_t data;
	uint16_t turn_on = 0x5890; // expected switching signal from CCU - Relay on
  uint16_t turn_off = 0x5899; // expected switching signal form CCU - Relay off
	clockInit();    // Initialize system clock
	Init_ADC();     // Initialize the ADC subsystem
	switch_enable ();// Initialize the switching pin
	xbee_init(); // Initialize X-bee
	SysTick_Init();

	while(1)
	{
		data = xbee_recieve();

		if( data == turn_on)
		{ 
			switch_on();
			GPIOC->ODR ^= GPIO_ODR_ODR8;  // LED for Switching Check
		}
		
		else if(data == turn_off)
		{ 
			switch_off();
	  } 
		
		// if the flag is set by systick timer. Used to control the rate of data transmission
		if (GLOBAL_PWR_SEND == true)
		{
			i++;
			GLOBAL_PWR_SEND = false;
		}
		
		if (i == 5)
		{
			GPIOC->ODR ^= GPIO_ODR_ODR9; // LED for Power monitoring data transmission check
		  powermonitoring();
		  i=0;
		}
		
		delay(500000);
	}
}

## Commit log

2019-01-16 Initial Commit
    Capstone User Interface design:
    - Created initial layout for all screens
    - Added transitions an some button functionality
    - Retrieved Data from local myslite3 database
    - Graphical representation for Time of Use Data
2019-01-16 Project Tracker
    For Scheduling and Progress Tracking as well as Task Assignment
    [Capstone Project tracker.xlsx]
2019-01-17 CT and temperature sensor datasheet
2019-01-22 Refactoring code for deployment on Raspberry Pi
2019-02-23 CCU Enclosure design
    - made box part
2019-02-23 Linear Optimization Algorithms for DR implementation
    [hourlyprice.csv, hourlyprice2.csv, hourlyprice3.csv]
2019-03-09 Revert "no message"
    This reverts commit 587cd837fc0db71fd895eb2b1a76b997976c0c9b.
    [main.py, xbee.py]
2019-03-09 Trying to fix pull error. Test 1
    [main.py, xbee.py]
2019-03-10 pull error check - resolving pull issue
    [main.py, xbee.py]
2019-03-12 1. The power supply and switching circuit testing results 2. Results of end to end switching Note: Delayed push due to pull errors on sourcetree
2019-03-12 Power monitoring code: Only switching circuit tested end to end - working Derived equations from the data measured from RMS to DC convertor: Power Monitoring Curve Fiting
    [Power Monitoring Curve Fiting.xlsx]
2019-03-14 Could not update earlier due to pull error. Power supply and switching circuit PCB desgins - Rev1 and Rev2 (final) Microcontroller and Xbee PCB Design - (Rev1 and Rev2(final) Also, final PCB designs 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
    [DEM.kicad_pcb, DEM.sch, Micro and XBee.kicad_pcb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]
2019-03-17 Recent changes to GUI and App functions and appearances(Post Crash)
    [hourlyprice3.csv]
2019-03-17 Final CCU PCB design
    [ccu_pcb.kicad_pcb, ccu_pcb.sch, ccu_pcb2.kicad_pcb]
2019-03-17 New Threaded Xbee communications interface for CCU App
2019-03-18 Thread ToU json file retrieve module
2019-03-25 delayed due to pullerror
    [monitoring.kicad_pcb, monitoring.sch, pcbdesign.kicad_pcb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]
2019-03-27 Powermonitoring integration with switching
